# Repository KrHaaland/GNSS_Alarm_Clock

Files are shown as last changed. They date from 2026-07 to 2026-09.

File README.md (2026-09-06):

# GNSS Alarm Clock — Firmware

Firmware for the custom **SAMD51** alarm-clock board (Adafruit Metro M4
compatible), designed in `HARDWARE/` (KiCad). Two board revisions share one
firmware:

- **v2 (current)** — SAMD51J20A, **nPM1300 PMIC** with Li-ion charging and
  USB-C, LM3671 3.3 V + TPS61023 5 V boost, battery-backed RTC, MCU core on
  its internal buck regulator. See
  [`HARDWARE_V2.md`](HARDWARE_V2.md) and [ADR-0014](docs/adr/0014-npm1300-power-management.md)/[0015](docs/adr/0015-j20-default-swd-flashing.md).
  Default build: `metro_m4_j20`.
- **v1 (prototype)** — SAMD51J19A, LTC3226 + supercaps (design in
  `HARDWARE_OLD/`). Build: `adafruit_metro_m4`. The firmware detects the
  PMIC at runtime and degrades gracefully either way.

Time is set automatically from GNSS, the timezone (with DST) is derived offline
from the GNSS coordinates and saved to flash so it stays correct indoors, and
alarms drive an LED light-show + a tune through a class-D amp. The UI is LVGL on
a 428×142 color TFT driven by four buttons.

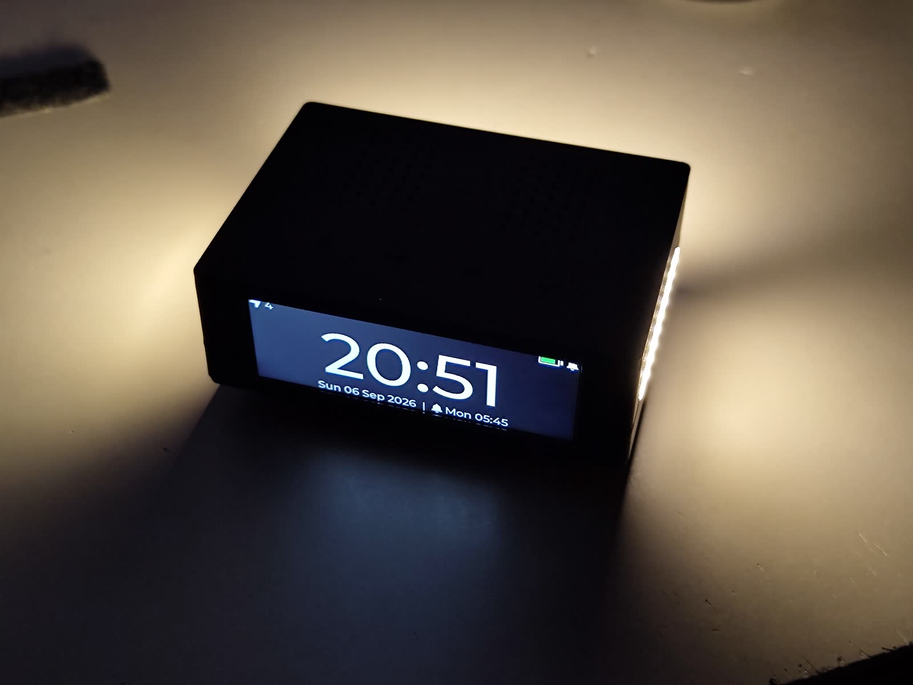
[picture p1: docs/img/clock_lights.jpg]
The clock at night, alarm light-show glowing


> **Current state:** firmware is feature-complete and running on hardware —
> display, GNSS time/timezone, alarms, audio, tunes-over-USB, settings, modes
> (speedometer/altimeter/USB-gamepad) and the RV-3028 RTC (hand-fitted; it was
> missing from the prototype) all work. See [`STATUS.md`](STATUS.md) and
> [`HARDWARE_REVIEW.md`](HARDWARE_REVIEW.md).

## Documentation

- **[User guide](docs/USER_GUIDE.md)** — buttons, menu, alarms, modes, tunes
- **[Architecture decisions](docs/adr/)** — why things are the way they are
- **[STATUS.md](STATUS.md)** — living status report · **[HARDWARE_REVIEW.md](HARDWARE_REVIEW.md)** — board findings
- **[HARDWARE_V2.md](HARDWARE_V2.md)** — v2 board reference (pinout, power tree, gotchas) · **[docs/sessions/](docs/sessions/)** — bench-session logs
- CI: GitHub Actions builds all firmware targets + runs the native test suite on every push

## What it does

- **Time**: The Quectel **L86** GNSS receiver (Serial1, 9600 NMEA, RMC+GGA @1 Hz
  plus GSV satellites-in-view every 5 s for the Sky-view screen, TinyGPS++ +
  a small in-house GSV parser) provides UTC. The clock is a `millis()`-anchored UTC counter
  disciplined by GNSS (re-syncs hourly / on ≥2 s drift) and backed by the
  **RV-3028-C7** RTC (I²C 0x52), whose VBACKUP sits on the battery (v2; the
  v1 prototype used the supercap rail) so it holds time through power loss. On boot the clock starts from the RTC
  immediately and refines from GNSS when a fix is available. A cold-start guard
  rejects the L86's free-running "year-2080" date so garbage can't be written
  into the backup RTC.
- **Timezone from coordinates**: An embedded **offline** lookup (213-box table
  covering every UTC zone worldwide — multi-zone countries split by region, plus
  no-DST exceptions like Arizona / Saskatchewan / Queensland / Kaliningrad;
  borders like US-zones and Afghanistan/Pakistan/India aligned to the real
  meridians). **Polygon zones** are checked before the boxes: real IANA
  timezone borders generated from timezone-boundary-builder data by
  `tools/gen_tz_polys.py` (tunable resolution/flash budget; enclaves ordered
  first), refinable by hand in `tools/tz_polygon_editor.html` (map GUI:
  draw/edit vertices, probe a point, export the header). Two resolutions,
  picked by flash size: v2/J20 gets the fine map
  (`src/TimezonePolyDataFine.h`, ~1–2 km borders, 404 zones / 56k vertices,
  ~250 KB), v1/J19 the coarse one (`src/TimezonePolyData.h`, ~57 KB). Anything not inside a polygon or box falls back
  to a whole-hour longitude estimate, so **every coordinate resolves**. Maps
  the GNSS position to a
  **POSIX TZ string with DST rules** (e.g. Oslo →
  `CET-1CEST,M3.5.0,M10.5.0/3`). The result is **persisted to internal flash**,
  so local time (including DST changes) stays correct after reboot even with no
  fix indoors. A DST-aware POSIX evaluator (`Timezone.*`, host-unit-tested)
  computes the offset. Manual zone override is available in the menu.
- **Alarms**: Two independent alarms with per-weekday masks. On trigger:
  - the **34 LEDs** (3 sections: left 10 / bottom 14 / right 10) run a chase at
    full brightness from a battery-capable rail (v2: TPS61023 5 V boost;
    v1: the LTC3226 supercap rail) — brightness never depends on the USB
    supply. The light show is **switchable per alarm** (Lights in the alarm
    editor; off = sound-only alarm),
  - a tune plays: a **WAV** from the QSPI flash drive, or one of 3 built-in
    melodies, via **DAC0 → TPA2016D2** class-D amp → speaker. WAVs pass a
    **200 Hz high-pass** in firmware: sub-bass cost the most battery current
    (speaker impedance minimum) for the least sound (ADR-0010),
  - optional **escalation**: after *N* minutes unacknowledged, the power buzzer
    joins in (v1 hardware only — v2 dropped the buzzer); auto-silence after
    30 min.
  - **Snooze**: short-press any button, or double-tap the clock (LIS3DH).
    **Stop**: long-press any button.
- **UI**: **LVGL 9.5** on an **NV3007 color TFT** (see below), driven by the 4
  buttons above the display: `[Back/Menu] [Prev/–] [Next/+] [OK]`. Screens:
  clock, menu, alarm-edit, time & zone, display, tunes, system-info,
  **sky view** (GSV polar plot + SNR bars — indoor antenna-placement aid),
  ringing. A true-black theme keeps the panel dark. Optional **starry night**:
  twinkling stars behind the clock digits between 22:00 and 06:00.
- **Modes** (Menu → Mode, cycles in place; alarms keep working in all of them):
  - **Alarm clock** — the normal HH:MM face.
  - **Speedometer** — the big figure shows GNSS ground speed in **km/h**.
  - **Altimeter** — GNSS altitude in **m** (MSL).
  - **Game mode** — the LIS3DH becomes a **USB HID gamepad**: tilt = stick
    X/Y, B2–B4 = buttons 1–3 (B1 keeps its menu role). The HID interface is
    always in the descriptor; it only sends reports in this mode.
- **Power (v2)**: the nPM1300 is driven end-to-end — input limit follows the
  USB-C CC advertisement (500 mA on PC ports, 1500 mA on real chargers,
  re-applied instantly on replug via the PMIC's IRQ line on PA04), charging
  400/800 mA to 4.10 V under an 80/70 °C die thermostat, live battery
  current on the Battery screen, a drawn SoC gauge on the clock face
  (ADR-0014/0016), and a low-battery policy: ship mode below 3.40 V (never
  during an alarm), fullscreen LOW BATTERY on a too-early wake, manual
  Shutdown in the menu — BUTTON1 or USB wakes it, the RTC keeps time
  throughout. The volume ceiling is bench-tuned to the PMIC's **1000 mA
  battery discharge limit (IBATLIM)** — exceeding it collapses VSYS and
  resets the device, so max volume (+7 dBV limiter) + LED chase stays under
  it with margin (ADR-0010/0014).
- **Tune upload**: the QSPI flash appears as a **USB flash drive** (`TUNES`) —
  drag & drop `.wav` files (PCM, 8/16-bit, mono/stereo, 8–48 kHz).

## Screenshots

Grabbed from the live firmware over USB serial (`tools/screenshot.py`).

| | |
|---|---|
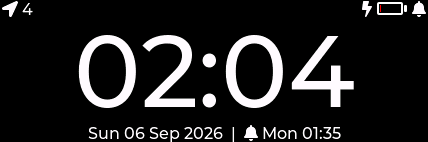
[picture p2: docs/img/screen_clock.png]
Clock face
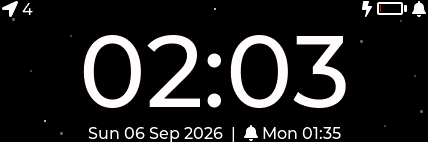
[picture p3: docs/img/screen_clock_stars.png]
Starry night
|  |  |
| Clock face — battery gauge, charge bolt, alarm bell | Starry night (22:00–06:00) |
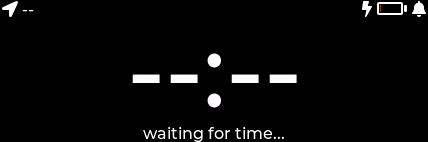
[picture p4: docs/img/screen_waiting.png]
Waiting for time
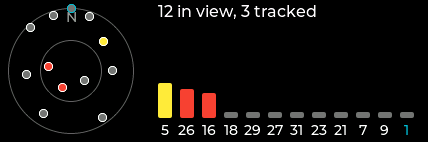
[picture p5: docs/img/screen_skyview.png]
Sky view
|  |  |
| First boot, no RTC/GNSS time yet | Sky view — GSV polar plot + SNR bars |
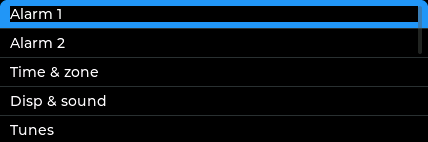
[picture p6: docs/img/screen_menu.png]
Menu
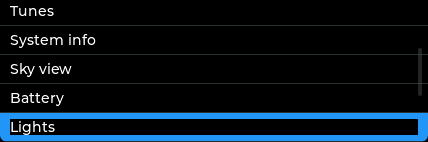
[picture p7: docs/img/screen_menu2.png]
Menu 2
|  |  |
| Main menu | …scrolled |
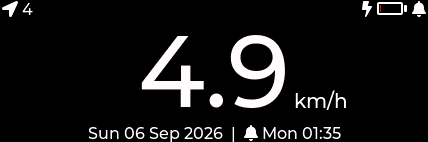
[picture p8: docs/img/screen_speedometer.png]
Speedometer
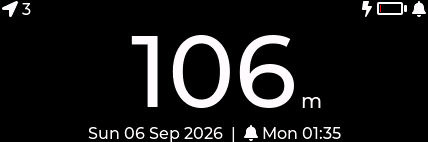
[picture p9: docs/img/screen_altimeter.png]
Altimeter
|  |  |
| Speedometer mode (GNSS) | Altimeter mode (GNSS) |
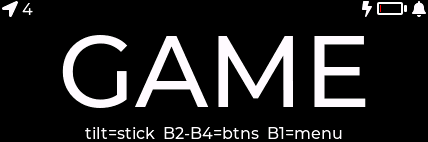
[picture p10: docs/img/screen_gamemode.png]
Game mode
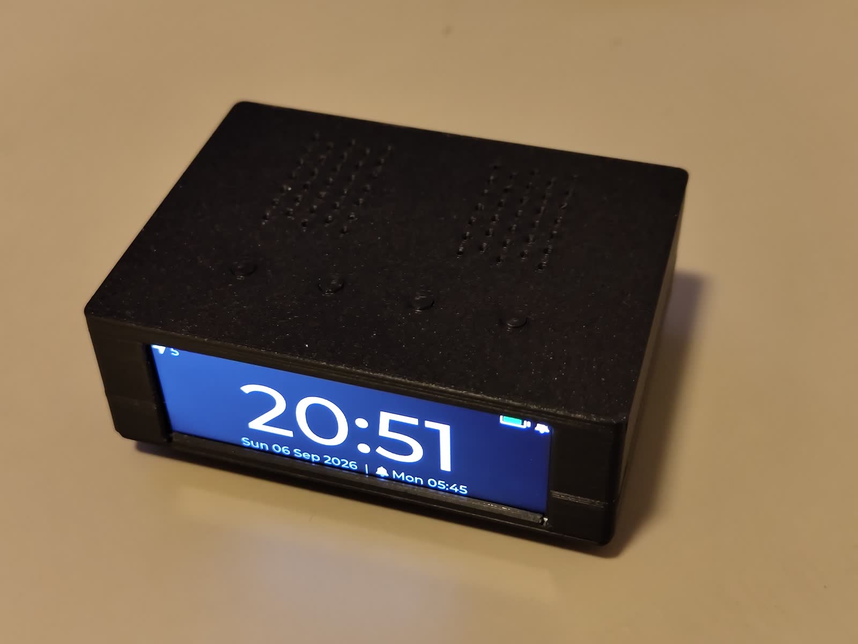
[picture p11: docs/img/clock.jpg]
The clock
|  |  |
| Game mode — USB HID gamepad | The 3D-printed enclosure |

## Display (NV3007)

The panel is an **NV3007 color TFT** (Newvision), native 142×428 bar type,
driven **landscape 428×142**. Driver: [`src/DisplayNV3007.cpp`](src/DisplayNV3007.cpp).
(The v1 prototype's ST7789 284×76 driver is kept in-tree — pick the panel via
**DISPLAY SELECT** in `platformio.ini`.)

- **Vendor init is mandatory**: `0xFF 0xA5` unlocks the extended register page
  (power/gamma/gate-driver/source-timing dump); without it the address engine
  wraps writes linearly across the glass. `0xFF 0x00` returns to the DCS page.
  Sequence cross-verified against five independent drivers (Arduino_GFX, LVGL
  lv_nv3007, vendor reference, STM32 + esp_lcd ports).
- GRAM is **168×428**; the 142 visible columns are inset 12/14. Landscape
  (`MADCTL 0xA0`, flipped 180° to match the enclosure mounting) puts the
  inset on RASET: **`NV_Y_OFFSET 12`** (unflipped 0x60 → 14). Inversion OFF.
- **SPI mode 0** (an NV3007 quirk — ST7789 setups often run mode 3), **30 MHz**
  (SERCOM2 re-clocked from the 120 MHz GCLK0 — the default 48 MHz source
  quantizes to 24 MHz max). Pixels stream via an **async DMA flush with double
  buffering** (ADR-0012, superseding ADR-0002's DMA ban): LVGL renders the
  next strip while the DMAC streams the previous one, and the completion IRQ
  hands the buffer back. Falls back to a synchronous DRE-paced register loop
  if the DMA channel is unavailable. Full frame ~26 ms on the wire, hidden
  behind rendering.
- Known silicon quirk: tiny partial writes can half-light adjacent pixels for
  RGB channel values 1–31 against black; LVGL's strip-sized flushes avoid it.
- Backlight D11/PA19, PWM-dimmed; shake-to-wake; `DISPLAY_SELFTEST` bring-up
  pattern test (colors/border/origin) as before.
- The clock figure uses a **generated 100 px Montserrat subset**
  (`src/font_clock_100.c`, 18 chars) — replacing the full 48 px font actually
  **shrank** flash by 67 KB (ADR-0011).

## Storage decision

The board has two candidate "EEPROMs" for tunes: the 24LC512 (64 KB, I²C) and a
QSPI serial flash. The firmware uses the **QSPI flash** (exposed as the USB
drive): far larger, faster, on the standard Metro M4 QSPI pins, and it enables
the drag-and-drop workflow.

**Settings** are packed into the **RV-3028 RTC's 43-byte user EEPROM**.
Chosen because it survives **firmware reflashes** (the old internal-flash
emulation sat inside the app image and was wiped on every update), takes
~100k writes/byte, and frees the **24LC512 to be dropped from the hardware-v2
BOM** (it still ACKs at 0x50 on v1 boards, unused). Verified on hardware:
settings survive both power cycles and reflashes.

### RTC user-EEPROM memory map (38 of 43 bytes)

Space is won by not storing derived data: TZ strings re-derive at boot from
the stored position (or the manual GMT-ladder index), and alarm tune filenames
are stored as 16-bit FNV-1a hashes re-matched against the TUNES directory
(missing file → builtin melody). Multi-byte fields are little-endian.

| Addr | Size | Field |
|---|---|---|
| `0x00` | 2 | Magic `'G' 'C'` |
| `0x02` | 1 | Pack-format version (4) — older blocks (v1–v3) migrate in place at boot, nothing is reset |
| `0x03` | 1 | Flags: b0 tzAuto, b1 tapSnooze, b2 use24h, b3 havePosition, b4–5 mode, b6 starryNight |
| `0x04` | 2 | Latitude, centidegrees (i16) |
| `0x06` | 2 | Longitude, centidegrees (i16) |
| `0x08` | 1 | Manual zone index into `TZ_TABLE` (`0xFF` = none/auto) |
| `0x09` | 1 | Volume (0–10) |
| `0x0A` | 1 | Snooze minutes |
| `0x0B` | 1 | Buzzer escalation after N min (0 = off) |
| `0x0C` | 1 | Brightness |
| `0x0D` | 2 | Dim timeout, seconds (u16) |
| `0x0F` | 1 | Dim brightness |
| `0x10` | 3 | Snooze counter, all time (u24, caps at 16.7 M) |
| `0x13` | 2 | Snooze counter, this week (u16) |
| `0x15` | 2 | Week start, local epoch-day − 18262 (u16, base 2020-01-01) |
| `0x17` | 7 | Alarm 1: flags (b0 enabled, b1–2 ramp Off/15/30/60 s, b3–4 random ±0/1/5/9 min, b5 lights-OFF — inverted so old blocks read as on), hour, minute, daysMask, melodyId, tuneHash (u16) |
| `0x1E` | 7 | Alarm 2: same layout |
| `0x25` | 1 | Checksum (block sums to `0xFF`) — **written last**, so a torn write invalidates the image |
| `0x26` | 5 | Free / future |

> **RV-3028 EEPROM quirks (bench-found, handled in `RtcRV3028.cpp`):** the
> chip **NACKs all I²C** while its EEPROM engine runs — both during the
> power-on auto-refresh (>100 ms) and in short windows after each programmed
> byte. The driver therefore treats failed STATUS reads as "still busy"
> (300 ms deadline), retries each byte transaction up to 5×, and read-back
> verifies every written byte.

> **Flash BOM note:** the schematic specifies a 4 MB Macronix MX25L3233F, but
> assembled boards carry a **16 MB Winbond W25Q128** (JEDEC 0xEF4018). The driver
> auto-detects the real chip via the library's default device list, so the true
> size is used for the USB drive.

## Pin map (from the KiCad netlist)

| Function | MCU pin | Arduino pin |
|---|---|---|
| Display CS / DC / RST / BL | PA18 / PA17 / PA16 / PA19 | D10 / D12 / D13 / D11 |
| Display SPI (SERCOM2) | PA12 MOSI, PA13 SCK | MOSI/SCK |
| GNSS L86 UART (SERCOM3) | PA22 TX → L86, PA23 RX ← L86 | Serial1 |
| GNSS FORCE_ON / RESET_N | PB00 / PB31 | direct port |
| I²C @100 kHz: RTC 0x52, amp 0x58, accel 0x18, EEPROM 0x50 | PB02 SDA, PB03 SCL | SDA/SCL |
| Buttons SW1..SW4 (L→R, active low) | PB14, PB13, PB12, PB15 | D5, D4, D7, D6 |
| LED gates: left / bottom / right | PA21 / PA20 / PA06 | D8 / D9 / A2 |
| Audio DAC → TPA2016 | PA02 (DAC0) | A0 |
| Amp ~SD (HIGH = on) | PB17 | D2 |
| Power buzzer gate (J5) | PB16 | D3 |
| Supercap CAPGOOD (LTC3226) | PA04 | A3 |
| LIS3DH INT1 (polled, unused) | PB08 | A4 |
| 24LC512 WP | PB01 | direct port |
| QSPI flash | PA08–11, PB10, PB11 | QSPI |

## Building & flashing

```sh
pio run                      # build (default env: adafruit_metro_m4)
pio test -e native           # host-side unit tests (timezone/DST engine)
```

### MCU select (J19 / J20)

The prototype has a **SAMD51J19A** (512 KB flash, ~95% full); the next revision
uses a **SAMD51J20A** (1 MB flash, ~48% — same pinout). Pick the build in
`platformio.ini` (`default_envs`) or per-invocation:

| env | MCU | notes |
|---|---|---|
| `adafruit_metro_m4` | J19A 512 KB | default (current prototype) |
| `metro_m4_j20` | J20A 1 MB | `boards/samd51j20a_metro.json` + `ld/samd51j20a_*.ld` |
| `sim` / `sim_j20` | either | + serial GNSS simulator (`-DGNSS_SIM`) |

```sh
pio run -e metro_m4_j20      # J20 build; flash .pio/build/metro_m4_j20/firmware.bin @0x4000
```

> **J20 + stock bootloader:** the Metro M4 UF2 bootloader is built for the
> J19A and reads the "stay in bootloader" magic at *its* RAM top
> (0x2002FFFC); a J20 app writes it at 0x2003FFFC, so the 1200-baud touch
> used to land straight back in the app. `tools/patch_tinyusb_power.py`
> patches the core's `initiateReset()` to write **both** addresses — USB
> uploads now work on the J20 with the stock bootloader.

Two flashing paths:

**A) USB (normal, no tools):** `pio run -e metro_m4_j20 -t upload` —
1200-baud touch into the bootloader, bossac writes + verifies at 0x4000
(~4 s). Manual alternative: double-tap RESET to mount the `METROM4BOOT`
drive and drag `firmware.uf2` onto it.

**B) SWD via Atmel-ICE (used in development):**

```sh
# build first, then flash the .bin at 0x4000 (offset preserves the bootloader)
openocd -c "adapter driver cmsis-dap" -c "transport select swd" \
        -c "adapter speed 2000" -f target/atsame5x.cfg \
        -c "init" -c "reset halt" \
        -c "flash write_image erase .pio/build/adafruit_metro_m4/firmware.bin 0x00004000 bin" \
        -c "reset run" -c "shutdown"
```

> ⚠️ **Never flash the `.elf` over SWD.** Its LOAD segment sits at address `0x0`
> and will overwrite the UF2 bootloader at flash start, bricking drag-and-drop
> programming (recovery = re-flash the bootloader). Always flash the **`.bin` at
> `0x4000`**. The bootloader region is additionally guarded by the
> **BOOTPROT fuse (16 KB)** since a brownout-induced wild NVMCTRL write once
> zeroed the bootloader's vector table (see `docs/sessions/`); clear it with
> `atsame5 bootloader 0` before intentional bootloader updates, restore with
> `atsame5 bootloader 16384`.

`pio device monitor -b 115200` opens the USB-CDC console. Sending `~` on
the console streams the next rendered frame as a screenshot —
`python3 tools/screenshot.py` grabs it and writes a PNG (used for the
documentation images; works on the live device, any screen).

### USB identity

The app enumerates as **`1209:0001` — "K. Haaland / GNSS Alarm Clock"**.
VID `0x1209` belongs to [pid.codes](https://pid.codes) (free USB IDs for
open-source hardware); `0x0001` is their official **test PID**, fine for
personal use — register a permanent PID via a pid.codes PR (requires a public,
OSI-licensed repo) before distributing hardware. Identity lives in
`boards/samd51j19a_kh.json` / `boards/samd51j20a_metro.json`. Bootloader mode
(double-tap reset) still enumerates as Adafruit `239A` until a custom
uf2-samdx1 is built.

### Simulated GNSS (`env:sim`)

To test the timezone/clock pipeline on-device **without a real fix**, build the
`sim` env — identical firmware plus `-DGNSS_SIM` (the L86 init is skipped and a
serial console feeds position/time):

```sh
pio run -e sim -t upload      # or SWD-flash .pio/build/sim/firmware.bin @0x4000
pio device monitor -b 115200
```

Then type commands into the monitor:

```
pos 59.91 10.75              set a fix; resolves + applies the timezone
tz  -33.87 151.2             query a zone (Jan/Jul offset + DST), no state change
utc 2026 7 13 12 0 0         set the UTC clock so local time shows on the display
status                       print fix / UTC / local time / zone
nofix                        drop the simulated fix
```

`pos` also updates the on-screen clock's zone immediately, so you can watch the
display follow you around the globe. The `sim` code compiles to nothing in the
normal build — zero production-flash cost.

## Source layout

| File | Responsibility |
|---|---|
| `src/main.cpp` | Boot order, super-loop, alarm ↔ UI ↔ button routing, I²C @100 kHz |
| `src/ClockKeeper.*` | UTC anchor, GNSS→RTC discipline, local time / DST |
| `src/Timezone.*` | Coord→zone polygons+boxes + POSIX TZ/DST evaluator (host-testable) |
| `src/TimezonePolyData.h` | Polygon zone data: `tools/gen_tz_polys.py` (world set) / `tools/tz_polygon_editor.html` (hand edits) |
| `src/Gnss.*` | L86 NMEA via TinyGPS++, PMTK config, position/speed/altitude |
| `src/RtcRV3028.*` | RV-3028-C7 driver wrapper (backup switchover, UTC, PORF) |
| `src/AlarmManager.*` | Trigger scan, ringing/snooze/escalation state machine |
| `src/AudioEngine.*` | TC2 ISR → DAC0 playback, WAV streaming, melodies, buzzer |
| `src/TuneStorage.*` | QSPI flash, FAT12 volume, USB mass storage |
| `src/DisplayST7789.*` | ST7789 driver + LVGL 9 flush (RGB565), bring-up self-test |
| `src/Ui.*` | LVGL screens: clock, menu, alarm edit, zone, display, tunes, info, sky view, battery, lights, ringing |
| `src/PmicNPM1300.*` | nPM1300: CC-based input limit, charger, IBAT/SoC, ship mode, IRQ (v2) |
| `src/Buttons.*` / `src/Leds.*` | Debounced input, LED section patterns |
| `src/AmpTPA2016.*` / `src/AccelLIS3DH.*` | Amp gain/enable, double-tap-to-snooze |
| `src/Settings.*` | Persistent settings packed into the RTC's user EEPROM (v4, 38 B) |
| `src/SimConsole.*` | Serial "virtual GPS" console — `env:sim` only (`-DGNSS_SIM`) |

## Diagnostics (compile-time, default off)

- `DISPLAY_SELFTEST` in [`DisplayST7789.cpp`](src/DisplayST7789.cpp) — on-glass
  pattern test (RGB fills, edge border) instead of LVGL.
- `I2C_SCAN` in [`main.cpp`](src/main.cpp) — loops scanning the I²C bus and
  prints ACKing addresses over USB serial (used to diagnose the RTC).

## Known issues / verify on hardware

See [`STATUS.md`](STATUS.md) for the full list. Highlights:

- 🔴 **RV-3028 RTC (U5) does not ACK on I²C** — bad joint / power on U5; being
  reflowed. (Time still works from GNSS; only power-off holdover is affected.)
- **L86 1PPS (pin 6) and AADET_N (pin 8) are unrouted** — no hardware PPS
  timing, no antenna-detect.
- **`CAPGOOD` polarity** assumed HIGH = charged (LTC3226 open-drain + pullup).
- Plus the schematic findings in [`HARDWARE_REVIEW.md`](HARDWARE_REVIEW.md)
  (LM3671 VIN/SW, L86 V_BCKP cold-start, D3 diode, C30, crystal caps, …).

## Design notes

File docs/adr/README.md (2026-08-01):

# Architecture Decision Records

Short records of the non-obvious decisions in this project — context,
the decision, and its consequences. Newest last. Format: lightweight MADR.

| # | Title | Status |
|---|---|---|
| [0001](0001-tunes-on-qspi-flash.md) | Tune storage on QSPI flash + USB MSC | Accepted |
| [0002](0002-synchronous-display-flush.md) | Synchronous per-byte display flush (no DMA) | Superseded by 0012 |
| [0003](0003-offline-timezone-resolution.md) | Offline timezone: polygons → boxes → longitude | Accepted |
| [0004](0004-settings-in-rtc-user-eeprom.md) | Settings in the RV-3028 user EEPROM | Accepted |
| [0005](0005-usb-identity-pidcodes.md) | USB identity via pid.codes | Accepted |
| [0006](0006-tinyusb-pinned-241.md) | TinyUSB pinned to 2.4.1 | Accepted |
| [0007](0007-i2c-100khz.md) | I²C bus at 100 kHz | Accepted |
| [0008](0008-hw-v2-j20-liion.md) | Hardware v2: SAMD51J20A + Li-ion | Accepted (planned) |
| [0009](0009-alarm-interaction-choices.md) | Alarm interaction choices | Accepted |
| [0010](0010-amp-loudness-architecture.md) | Amp loudness: AGC leveling, limiter as volume | Accepted |
| [0011](0011-display-panel-select-and-subset-font.md) | Panel select + subset clock font | Accepted |
| [0012](0012-async-dma-display-flush.md) | Async DMA display flush + double buffering | Accepted |
| [0013](0013-dma-paced-dac-audio.md) | DMA-paced DAC audio playback | Accepted |
| [0014](0014-npm1300-power-management.md) | v2 power management: nPM1300 strategy | Accepted |
| [0015](0015-j20-default-swd-flashing.md) | SAMD51J20A default target; SWD-first flashing | Accepted |
| [0016](0016-soc-estimate-and-gauge.md) | Battery SoC: measured-only estimate, approximate gauge | Accepted |

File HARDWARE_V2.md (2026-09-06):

# Hardware v2 — firmware-facing reference

Extracted systematically from `HARDWARE/GNSS_Alarm_Clock.kicad_pcb` (the
netlist is authoritative for the built board). v1 design lives in
`HARDWARE_OLD/`. This file is the ground truth for firmware work on v2 —
update it when the board changes.

## Power tree

```
USB-C (J1, CC1/CC2 -> PMIC)          Li-ion (J7, 2-pin JST-PH)
        |                                   |
      VUSB ──> nPM1300 (U3, I2C 0x6B) <── VBAT ──> RV-3028 VBACKUP (U5.6)
                   |  charger + power path + USB-C detection
                 VSYS  (= VBUS when present, else battery, ideal diode)
                   |   BATTERY BUDGET: nPM1300 IBATLIM caps discharge at
                   |   1000 mA — exceeding it drops VSYS below VSYSPOF and
                   |   RESETS the board. On battery, everything below must
                   |   fit in ~3.5 W. (On USB, VBUS adds its 0.5/1.5 A.)
                   ├──> LM3671 (U14)  -> +3.3V   (EN: R13 100k -> VSYS, always on)
                   └──> TPS61023 (U6) -> +5V     (EN: R4 100k -> VSYS, always on;
                        FB R5 732k / R12 100k -> ~5.0 V, boosts from battery too)
+3.3V: MCU, display (J4.7), L86 VCC+V_BCKP, RTC VDD, LIS3DH, QSPI flash,
       amp VDD (U1.13), I2C pullups (R6/R7 4.7k)

Bulk caps: C21 on +5V, C18 on +3.3V (both 220 uF aluminum electrolytic,
6.3x5.7 SMD). **C21 MUST stay an electrolytic (or get a feedforward cap
first) — its ESR is load-bearing.** Bench saga 2026-09: swapping C21 to a
560 uF (and later 330 uF) low-ESR polymer made the TPS61023 boost
UNSTABLE under load — oscillation/current slams dipped VSYS, resetting
the MCU (USB disconnects on PC charging; fast charger + all LEDs too);
charging thrashed CC<->trickle. Both polymers failed, the old elko
works: the discriminator is ESR, not capacitance. Datasheet-confirmed:
above ~40 uF output capacitance the TPS61023 needs a zero at ~1 kHz
(feedforward cap) — the elko's ESR zero (0.5 ohm x 220 uF ~ 1.4 kHz)
WAS that compensation, by accident. The ~50-125 mW ESR ripple loss is
the price of stability here. If polymer is ever wanted (v3): add
C_FF ~ 220 pF across R5 (732k) for the 1 kHz feedforward zero per the
datasheet, THEN low-ESR bulk is legal. C18 (3.3 V, buck output) is
unaffected either way — the LM3671 has its own MLCC and quiet loads.

- **The nPM1300's bucks are unused** (VOUT1/VOUT2/SW unconnected): the PMIC
  does charging, power path and USB-C only; regulation is external.
- **The MCU's core (VDDCORE) runs on its internal buck** via inductor L4
  (firmware selects it — the Arduino core defaults to the lossier LDO);
  ~4–6 mA saved at 3.3 V (ADR-0014).
- **VBUS input current limit resets to 100 mA on every VBUS plug/reset** —
  firmware re-applies it at boot AND on every attach (GPIO0 IRQ), set from
  the CC advertisement: 500 mA on Default USB/PC ports, 1500 mA on 1.5/3 A
  sources. Charging + system share the budget (supplement mode: the
  battery covers bursts beyond it).
- Charger config (firmware): 400 mA setpoint (the PMIC gives charging
  whatever remains of the input budget), terminate 4.10 V (user choice,
  cell longevity), die-temp thermostat 65/55 °C. NTC pin has a fixed 10k
  to GND (R16) — reads a constant ~25 °C, real temperature limiting is
  the die thermostat. No thermistor in the battery (J7 is 2-pin).
- **RTC backup is the battery** (VBAT -> U5.6): time survives power-off as
  long as a battery is fitted. Supercaps and LTC3226 are gone.
- **Battery: generic 505060 LiPo pouch, 3.7 V 2000 mAh, WITH PCM**
  (fitted 2026-08-10, replacing the bring-up LG HG2 18650 3000 mAh
  unprotected power cell). Battery-to-PCB leads: **100 mm, 20 AWG**
  (to J7/B2B-PH-K-S) — ~7 mOhm round trip, negligible next to the
  cell+PCM source impedance. 26 AWG was tried first and REJECTED:
  too much voltage drop under load on the bench (nominal ~27 mOhm
  round trip; real crimped wire measured worse) — and with the
  loaded-voltage 3.40 V cutoff, lead drop eats usable capacity
  directly. The PCM backstops overcharge/overdischarge/
  overcurrent, but the firmware's 3.40 V ship-mode cutoff still acts
  first (PCM floors are typically 2.5-3.0 V). Expect notably higher
  source impedance than the HG2 (generic pouch ~50-150 mOhm + PCM
  ~30-50 vs the HG2's ~25): the battery-path constant used for the
  IR-compensated SoC estimate (was ~160 mOhm total with the HG2) MUST
  be re-calibrated from the charger plug-in jump — and loaded-voltage
  sag at ~1 A is correspondingly larger (re-run the worst-case audio
  bench test; low-battery watchdog may need IR compensation).
- L86 **V_BCKP is on +3.3V** (U4.5), *not* VBAT — GNSS still cold-starts
  after a full power-off (v1 HW-review #10 persists on v2).

## MCU pin map (U18 — fitted chip is a **SAMD51J20A**)

The schematic symbol says ATSAMD51J19A, but the fitted part reports
`ATSAMD51x20` via `bossac -i` (1 MB flash / 256 KB RAM) — same stale-symbol
story as the flash chip; tidy the symbol on the next revision. J19A and
J20A are pin-identical in TQFP64, so the pin map below applies unchanged.
Build with `pio run -e metro_m4_j20` (the project default).

Complete map of all 64 pads of U18, TQFP64. Columns:

- **Pad** — TQFP64 pad number (from the ATSAMD51J19A symbol in
  `GNSS_Alarm_Clock.kicad_sch`).
- **PORT** — the SAMD51 PORT pin the symbol assigns to that pad.
- **v2 net** — net name on the pad in `GNSS_Alarm_Clock.kicad_pcb`. `—` for
  power/ground; `(unconnected)` for a genuinely floating GPIO.
- **Function** — what firmware does with it.
- **Arduino** — pin number in the `adafruit_metro_m4` variant
  (`variant.cpp`, `g_APinDescription` order). `DIRECT PORT` = the PORT pin
  is not exposed by that variant, so firmware must touch the PORT
  registers. `—` = power/ground/reset, no Arduino pin.

| Pad | PORT | v2 net | Function | Arduino |
|----:|------|--------|----------|---------|
| 1 | PA00 | XIN32 (X1.2) | 32.768 kHz crystal (XOSC32K, RTC/clock) | DIRECT PORT (crystal, not GPIO) |
| 2 | PA01 | XOUT32 (X1.1) | 32.768 kHz crystal | DIRECT PORT (crystal, not GPIO) |
| 3 | PA02 | Analog | Audio DAC out → C27 → TPA2016 INR- | D14 / A0 / DAC0 |
| 4 | PA03 | +3.3V | VREFA tied to +3.3V (analog reference, not a GPIO) | — |
| 5 | PB04 | (unconnected) | free | DIRECT PORT |
| 6 | PB05 | (unconnected) | free | DIRECT PORT |
| 7 | GNDANA | GND | analog ground | — |
| 8 | VDDANA | +3.3V | analog supply | — |
| 9 | PB06 | (unconnected) | free (was RXLED on Metro) | D27 |
| 10 | PB07 | (unconnected) | free (was USB Host EN on Metro) | D29 |
| 11 | PB08 | LIS3DH_INT1 | Accelerometer INT1 (U7.11) | D18 / A4 |
| 12 | PB09 | (unconnected) | free | D19 / A5 |
| 13 | PA04 | PMIC_GPIO0 | nPM1300 GPIO0 (U3.7); unconfigured reads LOW | D17 / A3 |
| 14 | PA05 | (unconnected) | free | D15 / A1 / DAC1 |
| 15 | PA06 | LedsR-S | Right LED section gate → R56 470R → U12 | D16 / A2 |
| 16 | PA07 | (unconnected) | free | DIRECT PORT |
| 17 | PA08 | FlashIO0 | QSPI flash DATA0 (U8.5) | D43 |
| 18 | PA09 | FlashIO1 | QSPI flash DATA1 (U8.2) | D44 |
| 19 | PA10 | FlashIO2 | QSPI flash DATA2 (U8.3) | D45 |
| 20 | PA11 | FlashIO3 | QSPI flash DATA3 (U8.7) | D46 |
| 21 | VDDIOB | +3.3V | I/O supply | — |
| 22 | GND | GND | ground | — |
| 23 | PB10 | FlashSCK | QSPI flash SCK (U8.6) | D41 |
| 24 | PB11 | FlashCS | QSPI flash CS (U8.1) | D42 |
| 25 | PB12 | BUTTON3 | SW3, active-low, 1M pull-up (R9) | D7 |
| 26 | PB13 | BUTTON2 | SW2, active-low, 1M pull-up (R8) | D4 |
| 27 | PB14 | BUTTON1 | 74LVC1G17 (U9.4) output, not a raw switch | D5 |
| 28 | PB15 | BUTTON4 | SW4, active-low, 1M pull-up (R10) | D6 |
| 29 | PA12 | SPI_MOSI | Display SPI MOSI (SERCOM2), J4.5 | D26 / MOSI |
| 30 | PA13 | SPI_SCK | Display SPI SCK (SERCOM2), J4.6 | D25 / SCK |
| 31 | PA14 | SPI_MISO | SPI MISO (SERCOM2) — not routed to J4 panel | D24 / MISO |
| 32 | PA15 | (unconnected) | free | DIRECT PORT |
| 33 | GND | GND | ground | — |
| 34 | VDDIO | +3.3V | I/O supply | — |
| 35 | PA16 | DISP_RST | Display reset (active low), J4.4 | D13 |
| 36 | PA17 | DISP_DC | Display data/command, J4.3 | D12 |
| 37 | PA18 | DISP_CS | Display chip select (active low), J4.2 | D10 |
| 38 | PA19 | DISP_BL | Display backlight/aux, J4.1 | D11 |
| 39 | PB16 | (unconnected) | **buzzer removed on v2** (was SPEAKER) | D3 |
| 40 | PB17 | AmpShutdown | TPA2016 ~SD (U1.18), 10k pull-up R68, HIGH=on | D2 |
| 41 | PA20 | LedsB-S | Bottom LED section gate → R54 470R → U11 | D9 |
| 42 | PA21 | LedsL-S | Left LED section gate → R15 470R → U10 | D8 |
| 43 | PA22 | McuTX | Serial1 TX (SERCOM3) → L86 RX (U4.1) | D1 |
| 44 | PA23 | McuRX | Serial1 RX (SERCOM3) ← L86 TX (U4.2) | D0 |
| 45 | PA24 | USB_N | USB D- (via U2 ESD) | D30 |
| 46 | PA25 | USB_P | USB D+ (via U2 ESD) | D31 |
| 47 | GND | GND | ground | — |
| 48 | VDDIO | +3.3V | I/O supply | — |
| 49 | PB22 | (unconnected) | free (was NEOPIX on Metro) | D40 |
| 50 | PB23 | (unconnected) | free | DIRECT PORT |
| 51 | PA27 | (unconnected) | free (was TXLED on Metro) | D28 |
| 52 | RESETN | SWD_RST | MCU reset (SW5 + J3 SWD, 100k pull-up R67) | — |
| 53 | VDDCORE | (core reg) | 1.2 V core LDO decoupling | — |
| 54 | GND | GND | ground | — |
| 55 | VSW | (core reg) | core regulator switch node | — |
| 56 | VDDIO | +3.3V | I/O supply | — |
| 57 | PA30 | SWD_CLK | SWD clock, J3 (100k pull-up R66) | DIRECT PORT |
| 58 | PA31 | SWD_IO | SWD data, J3 | DIRECT PORT |
| 59 | PB30 | SWO | SWO trace, J3.6 | DIRECT PORT |
| 60 | PB31 | GNSS_Reset | L86 RESET_N (U4.10), active low | DIRECT PORT |
| 61 | PB00 | GNSS_FOn | L86 FORCE_ON (U4.7) | DIRECT PORT |
| 62 | PB01 | (unconnected) | **24LC512 removed on v2** (was EEPROM WP) | DIRECT PORT |
| 63 | PB02 | I2C_SDA | I2C SDA (SERCOM), 4.7k pull-up R6 | D22 / SDA |
| 64 | PB03 | I2C_SCL | I2C SCL (SERCOM), 4.7k pull-up R7 | D23 / SCL |

Delta vs v1 (`include/pins.h`), verified net-for-net:

| Pin | v1 | v2 |
|---|---|---|
| PA04 (A3) | CAPGOOD (LTC3226, HIGH = caps charged) | **PMIC_GPIO0** (nPM1300 GPIO0; unconfigured = reads LOW) |
| PB16 (D3) | Buzzer MOSFET gate (J5) | **Unconnected — the escalation buzzer does not exist on v2** |
| PB01 | 24LC512 write protect | Unconnected (EEPROM gone) |
| PB14 (D5, BUTTON1) | raw switch, active low | driven by 74LVC1G17 (U9), see Buttons |
| PB30/SWO | — | SWO to SWD connector J3.6 |

Everything else is identical net-for-net: display PA16-19 + SERCOM2 SPI (J4
8-pin XH header: BL,CS,DC,RST,MOSI,SCK,3V3,GND — no MISO to the panel),
buttons PB12-15, LED gates PA21/PA20/PA06, GNSS PA22/PA23 + PB00/PB31, DAC
PA02 → C27 → TPA2016 INR-, QSPI PA08-11 + PB10/11, I2C PB02/PB03.

**U8 tune flash — WRONG PART FITTED on the first v2 board:** JEDEC probe
reads `EF 60 18` = **W25Q128FW**, Winbond's **1.8 V** variant, running out
of spec on the 3.3 V rail (abs max ~2.5 V). It answers JEDEC but has no
library profile, so `flash.begin()` fails and the TUNES drive/storage is
disabled (firmware degrades gracefully). **Replace with W25Q128JVSIQ**
(3 V, JEDEC `EF 40 18`, in the library's builtin list, same SOIC-8) or an
MX25L3233F (4 MB, matches the schematic symbol + our explicit descriptor).
The schematic symbol says MX25L3233F and the BOM Value says "25Q128" —
tidy both on the next revision.

## Display module gotcha: BL strap polarity

Off-the-shelf NV3007 modules differ in how the backlight enable is strapped
on the module: with a **pull-up**, a floating DISP_BL (PA19 — floats through
the whole UF2-bootloader phase) means the backlight burns at FULL power
inside the PMIC's 100 mA power-up window → a battery-less board boot-loops
before any code can help (and shows a ghost of the previous frame, since
the panel GRAM survives the shallow brownouts). Diagnosed by tying BL to
GND, which let it boot. Modules with a **pull-down** are safe. Firmware
drives PA19 low as its first instruction and soft-starts the backlight,
which closes the app-phase window but cannot reach the bootloader phase.

## Buttons

- SW2-SW4 = BUTTON2-4, active low, 1M pullups (as v1).
- **BUTTON1 is special on v2**: the physical button is SW1, which drives
  the nPM1300's **SHPHLD** pin directly and reaches PB14 through a
  74LVC1G17 buffer (U9). Idle high (PMIC internal pull), pressed = LOW —
  same polarity as v1. Consequences:
  - Pressing BUTTON1 wakes the PMIC from ship/hibernate mode (battery boot).
  - A very long press (~10 s, PMIC long-press function) power-cycles the
    whole board in hardware — independent of firmware.
- SW5 = MCU reset (SWD_RST), on the 10-pin SWD header J3 side.

## LED sections (unchanged counts, better gates)

10 left / 14 bottom / 10 right (LED1-10 / LED11-24 / LED25-34, OR-PL020W,
100R each from +5V, R20-R53). Gates now have 470R series + 10k pulldowns
(left PA21→R15/R57→U10, bottom PA20→R54/R55→U11, right PA06→R56/R58→U12) —
v1's floating-gate-at-boot quirk is fixed.

## I2C bus (100 kHz, pullups 4.7k)

| Addr | Device | Note |
|---|---|---|
| 0x18/0x19 | LIS3DH (U7) | v2 straps SA0 low (R18 10k->GND) and CS high (R63 10k->3.3V), so 0x18 is the *design* address — but the first v2 board answers at **0x19**, meaning SA0 doesn't see its pulldown (suspect solder at U7 or R18 unfitted). Harmless: FW probes both. |
| 0x52 | RV-3028 RTC | battery-backed via VBAT |
| 0x58 | TPA2016 amp | PVCC now +5V boost (works on battery) |
| 0x6B | nPM1300 PMIC | see power tree |

## GNSS (L86, U4)

Wiring identical to v1: pad1->McuTX(PA22), pad2->McuRX(PA23), VCC+V_BCKP
on +3.3V, FORCE_ON PB00, RESET_N PB31. **1PPS (U4.6) and AADET_N (U4.8)
remain unrouted** (v1 findings persist). V_BCKP not battery-backed (above).

## Other

- USB ESD: U2 PRTR5V0U2X on USB_P/N/VUSB (+C2/R1 network on pin 1).
- 32.768 kHz crystal X1 on PA00/PA01 with 10 pF load caps (v1 finding
  about wanting ~18-22 pF persists).
- Speaker: J6 from TPA2016 OUTR± (right channel only, as v1).
- nPM1300 GPIO1-4 and LED0-2 pads unconnected; GPIO0 -> PA04 (candidate:
  configure as charge-status output so FW can read charging without I2C).

## Next board revision (v3) checklist

Collected findings from the v2 bring-up, in rough priority order:

- [ ] **R68: amp ~SD pull-up → pull-DOWN.** Today the TPA2016 is enabled
      through the whole bootloader phase (~1 s) before firmware can kill
      it: wastes 5–15 mA in the battery-less boot window and audibly
      amplifies the undriven DAC node (boot noise, user-confirmed).
      Pull-down = off until firmware enables.
- [ ] **L86 load switch** (enable in front of its 3.3 V): the module is
      the largest uncontrollable boot-window load (~100 mA acquisition
      bursts) — firmware can only hold it in reset today.
- [ ] **L86 V_BCKP → VBAT** (carried over from v1 review #10): GNSS
      cold-starts after every full power-off; battery-backing it gives
      warm starts. Route 1PPS to a spare GPIO while at it.
- [ ] **VBACKUP buffer cap (U5.6)**: ~100 nF–1 µF from the RV-3028's
      VBACKUP pin to GND. In ship mode the RTC runs from VBACKUP alone
      (nA domain, high impedance) and a hot-plug ground transient — e.g.
      a floating charger's Y-cap leakage equalizing through the board
      while SWD pins board GND to PC earth — can POR it and lose the
      time (observed 2026-08-02). A local cap rides the chip through.
- [ ] **LIS3DH SA0 strap**: R18 (10k pulldown) is not effective on the
      built board (chip answers 0x19, not 0x18) — inspect/repair the
      strap or route it harder. FW probes both addresses regardless.
- [ ] **Schematic symbol tidy-up**: U18 says J19A (fitted: J20A), U8 says
      MX25L3233F with Value "25Q128" (correct part: W25Q128**JV**SIQ 3 V —
      the FW suffix cost a bricked-storage detour).
- [ ] **Display BL strap**: specify/verify pull-DOWN modules only (a
      pull-up module burns the backlight through the bootloader phase and
      boot-loops a battery-less board).
- [ ] Optional: inrush limiting on the panel rail; keep the nPM1300
      GPIO0→PA04 IRQ line (it earned its keep).

## Firmware consequences (status)

- [x] `pmic_begin()` raises VBUS ILIM at every boot + configures charger
- [x] `supercaps_ready()` returns true when PMIC present (until battery UI)
- [x] Accelerometer probes 0x18 and 0x19
- [x] Battery/PMIC screen in the menu
- [ ] Escalation buzzer is a silent no-op on v2 (PB16 unrouted) — gate the
      escalation stage on `pmic_present()` or repurpose (max volume + LEDs)
- [x] Battery gauge on the clock screen; low-battery ship-mode policy
- [x] nPM1300 GPIO0 -> PA04 used as IRQ line (VBUS attach/removal)

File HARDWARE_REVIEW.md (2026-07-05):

# Hardware Design Review — GNSS Alarm Clock (SAMD51J19A board)

> ## Display change (2026-07): SH1122 → ST7789
> The board now uses an **ST7789 color TFT** (native 76×284, driven landscape
> **284×76**) in place of the SH1122 256×64 grayscale OLED. Firmware driver:
> `src/DisplayST7789.cpp`.
> - Same 4-wire SPI on J3: CS/DC/RST + MOSI/SCK (SERCOM2).
> - **Backlight (BLK):** the ST7789 needs a backlight supply the OLED did not.
>   Per finding #14 below, **J3 has no backlight line**, so BLK must be wired
>   separately — currently assumed on **D11 / PA19** (the old `OLED_BL`,
>   PWM-capable via TCC1 for dimming). *Confirm/adjust the actual BLK pin.*
> - Also confirm the **flash BOM substitution** (16 MB Winbond W25Q128, see the
>   TuneStorage note) when you revise the BOM.
> - Panel-specific ST7789 params still being tuned on the bench: MADCTL
>   orientation, display inversion, and the column/row window offsets.

Reviewed from `HARDWARE/production/netlist.ipc` (IPC-356 connectivity),
`HARDWARE/production/bom.csv`, and `HARDWARE/samd51_gps_alarm_clock.kicad_sch`.
Findings were produced by 8 domain reviewers and each **adversarially
verified** by an independent skeptic. 19 confirmed, 7 refuted.

> ⚠️ Reality check on the critical finding: the assembled board **does** power
> up and run (MCU, USB, display all work across many flash cycles). That is in
> tension with a fully-broken 3.3 V regulator. **Measure the 3.3 V rail and
> U14 temperature** to decide whether your unit is affected/was reworked, or
> whether the KiCad symbol pin mapping actually differs from what the netlist
> text suggests. Treat the LM3671 item as "verify on the bench first."

---

## 🔴 Critical

### 1. LM3671 (U14) 3.3 V buck — VIN and SW swapped in the KiCad symbol
- **Evidence:** schematic symbol `LM3671MFX-3.3_NOPB` declares pin **1 = "VIN"**,
  pin **5 = "SW"** (pin2=GND, pin3=EN, pin4=FB). Real LM3671MF SOT-23-5 pinout
  (TI SNVS482) is **pin1=SW, pin2=GND, pin3=EN, pin4=FB, pin5=VIN**. Netlist
  copper follows the (wrong) symbol: U14 pad1=+5V, pad4=+3.3V (FB), pad5=NET-(U14-SW),
  and L1 joins pad5 ↔ +3.3V. Footprint pads are standard SOT-23-5 (no compensating renumber).
- **Why wrong:** on real silicon +5 V lands on the switch node and VIN is fed
  only through inductor L1 from the 3.3 V output → the buck cannot regulate; the
  whole +3.3 V rail (MCU, GNSS, RTC, EEPROM, accel, QSPI flash, OLED) is affected
  and the SW pin is abused by 5 V.
- **Fix:** correct the library symbol so pin 1 = SW and pin 5 = VIN (or swap the
  copper so +5 V lands on pad5 and the L1/SW node on pad1). FB→+3.3 V is already
  correct for the fixed-output variant.

---

## 🟠 Major

### 2. Buzzer/speaker flyback diode D3 wired the wrong way (found by 3 reviewers)
- **Evidence:** D3 cathode (NET-(D3-K)) = U13 drain = J5-2; D3 anode = GND.
  J5-1 = ALARMPOWER (via 0 Ω R64). U13 is a low-side N-FET (source=GND).
- **Why wrong:** for a low-side switch on a supply-referenced inductive load
  (speaker/buzzer coil), the freewheel diode must be **anode→drain, cathode→ALARMPOWER**
  so the turn-off spike recirculates into the supply. As built it parallels the
  MOSFET body diode and clamps only negative undershoot → no protection; the FET
  can avalanche on the positive spike.
- **Fix:** reorient D3 across the coil — cathode to ALARMPOWER (J5-1 / NET-(C21-PAD1)),
  anode to the drain (NET-(D3-K)).

### 3. C30 (VDDCORE decoupling) tied to +3.3 V instead of GND
- **Evidence:** C30 pad1=NET-(U18-VDDCORE), pad2=**+3.3V**. Siblings C26/C29 are
  correctly VDDCORE↔GND. BOM groups C26+C30 as identical 1 µF → C30 is meant to be
  the 3rd VDDCORE bypass cap.
- **Why wrong:** VDDCORE is the SAMD51 internal ~1.2 V core rail; its bypass must
  reference GND. Tying it to +3.3 V injects the 3.3 V ramp/switching transient into
  the core node.
- **Fix:** move C30 pad2 from +3.3 V to GND.

### 4. 32.768 kHz crystal load caps wrong (C24/C25 = 10 pF for a 12.5 pF-CL xtal)
- **Evidence:** X1 = Epson FC-135 (CL = 12.5 pF per schematic description); C24/C25 = 10 pF.
- **Why wrong:** required load caps ≈ 2·(CL − Cstray) ≈ 18–22 pF. 10 pF presents
  ~7–8 pF effective load → oscillator runs fast (~+50…100 ppm, several s/day) and
  startup margin is reduced.
- **Fix:** fit ~18–22 pF (start 18 pF), tune on-board; or swap X1 for a 7 pF-CL crystal.
- *Note:* affects the SAMD51's own 32 kHz clock accuracy; GNSS/RTC still discipline wall-clock time.

### 5. USB ESD array (U2 PRTR5V0U2X) ground pin not grounded (found by 2 reviewers)
- **Evidence:** U2 GND pin is tied to a 1 MΩ (R1) / 1 µF (C2) node, not the GND plane.
- **Why wrong:** the ESD diode array shunts surge current into its GND pin; through
  1 MΩ (DC) / 1 µF (useless at ESD timescales) there is no low-impedance path to
  ground → ESD protection on D+/D- is defeated.
- **Fix:** route U2 pin 1 directly to GND; remove/relocate R1/C2.

### 6. Audio amp input INR+ hard-grounded instead of AC-coupled
- **Evidence:** DAC0 (PA02, net ANALOG) → C27 → INR-; INR+ tied directly to GND.
- **Why wrong:** TPA2016 differential inputs are internally biased; the standard
  single-ended hookup AC-couples both inputs (signal into one, a matching cap to
  GND on the other). Hard-grounding INR+ imbalances the bias → DC offset / turn-on pop.
- **Fix:** ground INR+ through a cap matching C27 (e.g. 100 nF).

### 7. Amp PVCC (ALARMPOWER) lacks local decoupling at U1
- **Evidence:** bulk supercaps C12/C13 are remote; C18 (220 µF)/C19 are on other rails.
- **Why wrong:** class-D PVCC needs a local low-ESR bulk + HF ceramic at the amp to
  supply pulsed switching current; remote high-ESR caps let PVCC sag/ring → distortion.
- **Fix:** add ≥10 µF (ideally the 220 µF) + 100 nF from ALARMPOWER to GND right at
  U1 pins 4/5 and 11/12; verify C18's intended rail.

### 8. RTC alarm interrupt (U5 ~INT, pin 2) not routed to the MCU
- **Evidence:** RV-3028 ~INT is a dead-end net.
- **Why wrong:** the RTC's open-drain ~INT is meant to wake the MCU on alarm/timer;
  unconnected, alarms can only be caught by continuous I²C polling → MCU can't sleep
  (defeats the low-power/backup-timekeeping design intent).
- **Fix:** route ~INT to a wake-capable GPIO with a pull-up to +3.3 V; configure it as
  an external interrupt in firmware.

### 9. VREFA (PA03) left floating
- **Evidence:** PA03 (external ADC reference) unrouted, undecoupled.
- **Why wrong:** if firmware ever selects the external reference the ADC reads garbage.
- **Fix:** either drive VREFA from a reference + add 100 nF/1 µF, or document that only
  the internal/VDDANA reference may be used. *(Current firmware uses internal ref → low practical impact.)*

---

## 🟡 Minor

### 10. GNSS V_BCKP (U4 pin 5) on main +3.3 V instead of a persistent backup rail
- **Why it matters:** V_BCKP holds the L86's ephemeris/almanac + last fix. On +3.3 V it
  dies with main power → **full cold start every boot** (TTFF ~30 s+). **This is the root
  cause of the firmware "year-2080 / no-fix" cold-start behavior.**
- **Fix:** route V_BCKP to the persistent supercap rail (as the RTC's backup already is),
  or a coin cell / diode-OR'd backup.

### 11. VDDANA not isolated from digital 3.3 V (no ferrite) + missing HF decoupling
- Add a ferrite from +3.3 V to VDDANA with 100 nF + 1 µF at the pin.

### 12. I²C / peripheral ICs have only 10 µF bulk, no 100 nF HF bypass
- Add a 100 nF close to VDD of RV-3028, 24LC512, LIS3DH (VDD & VDD_IO), TPA2016 (keep the 10 µF).

### 13. Unused amp left channel inputs (INL+/INL-) left floating
- Tie INL+/INL- to GND (or 100 nF each). Leaving OUTL open is fine.

### 14. OLED_BL toggled in firmware but not routed to J3
- The backlight/aux control terminates at the MCU only. Harmless for the SH1122 (no backlight);
  either add a J3 pin or drop OLED_BL from firmware.

### 15. LTC3226 (U15) regulated backup output (VOUT) + control pins unused
- The load runs off the raw charge-pump/supercap node → ALARMPOWER is unregulated (sags as caps
  discharge). Intentional if the direct-off-supercap topology was chosen; otherwise wire the
  PowerPath PFET on GATE, route load to VOUT, set LDO_FB/RST_FB.

### 16. LED array current budget vs LTC3226/supercap (verify, not a wiring error)
- Worst-case simultaneous LED (up to ~0.85 A if all sections on) + amp load vs the supercap
  ESR / charger current. Firmware chases one section at a time, so peak is lower; confirm no
  brownout/dimming. If marginal: raise the 80 Ω, or PWM/stagger sections.

---

## ✅ Checked and correct (refuted candidates)
USB-C CC resistors (R2/R3 = 5.1 kΩ pull-downs to GND), GNSS UART crossover
(MCUTX→L86 RXD, MCURX→L86 TXD), LM3671 feedback (FB→VOUT, correct for fixed
variant), SAMD51 VDDCORE inductor L4, LED/buzzer MOSFET gate resistors +
pull-downs, and the crystal being on the correct XIN32/XOUT32 pins.

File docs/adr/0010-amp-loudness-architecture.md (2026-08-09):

# 0010 — Amp loudness architecture: AGC leveling, limiter as volume

Date: 2026-07-14, ceiling re-tuned 2026-08-09 · Status: **Accepted**

## Context
The TPA2016D2 was used as "fixed gain + peak limiter"; loudness = the gain
register, digital volume scaled the DAC stream in parallel. User-supplied
WAV tunes are mastered wildly differently, and a bedside alarm benefits from
a gentle volume ramp.

## Decision
Enable the chip's **AGC at 1:4 compression** so program material is leveled
toward the output ceiling. With AGC active the **output limiter level is the
real volume control**, so:
- volume 0–10 maps to the limiter level: v1 = −6.5 dBV (~28 mW into 8 Ω) …
  v10 = **+7 dBV** (~0.63 W into 8 Ω). The ceiling is deliberately below the
  chip max (+9 dBV): bench measurement (2026-08-09) showed max volume + LED
  chase crossing the nPM1300's **1000 mA battery discharge limit** as the
  AGC wound up — IBATLIM collapses VSYS and resets the device. A USB-only
  higher ceiling was rejected: the limit applies instantly at unplug while
  software reacts in ~10–50 ms, an unwinnable race. See ADR-0014,
- fixed gain stays constant (+6 dB into the AGC),
- the digital (DAC) volume is pinned high — it would otherwise be undone by
  the AGC,
- a **200 Hz 2nd-order Butterworth high-pass** filters the WAV path in
  firmware (AudioEngine, `AUDIO_HPF_HZ`): below the small driver's resonance
  the impedance is at minimum (max current) while the cone barely radiates,
  so deep bass was the most expensive content per mA and the least audible.
  Trimming it lowers the sustained current peaks that threaten the
  nPM1300's IBATLIM (ADR-0014) — and the AGC then spends the energy budget
  on the audible band instead. Builtin melodies (sines ~260 Hz+) bypass it.
  Bench tool: `tools/gen_sweep.py` + the dev IBAT readout map the speaker's
  current-vs-frequency curve in one 30 s pass,
  the set volume over 0/15/30/60 s — configured **per alarm** in the alarm
  editor (weekday alarm can fade in, weekend alarm can blast); snooze
  **re-rings skip the ramp**, and buzzer escalation jumps to full volume,
- the SETUP register's fault/thermal bits are surfaced on System info.

## Consequences
- All tunes play at comparable loudness regardless of mastering.
- Wake-up starts gentle but cannot be slept through (re-ring + escalation
  bypass the ramp).
- Volume perception is now tied to the limiter. The floor cannot go below
  the chip's −6.5 dBV while AGC leveling is active (the AGC lifts material
  toward the ceiling regardless of input gain) — a true whisper mode would
  need compression disabled at low volumes.

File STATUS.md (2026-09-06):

# Project Status Report — GNSS Alarm Clock

_Last updated: 2026-09-06 — **release [v1.0.1](https://github.com/KrHaaland/GNSS_Alarm_Clock/releases/tag/v1.0.1)** (bin + UF2 for both boards); previously [v1.0.0](https://github.com/KrHaaland/GNSS_Alarm_Clock/releases/tag/v1.0.0) published** (bin + UF2 for both boards)_

Custom **SAMD51** board (Adafruit Metro M4 compatible) — the **v2 board
(SAMD51J20A, nPM1300 PMIC, Li-ion, USB-C) is now the primary target**; the
v1 prototype (J19A, supercaps) remains supported. Firmware:
PlatformIO + Arduino + **LVGL 9.5**. This report captures the current state,
what changed most recently, and the open items — hardware and firmware.

---

## 1. Overall status

**Firmware is feature-complete — release v1.0.0 — and running on the v2
board.** Every subsystem is implemented and bench-verified. Open hardware
items are parts in the mail (L86 module, 3 V QSPI flash, pull-down display);
none stop daily use — the clock runs off the battery-backed RTC.

| Subsystem | State | Notes |
|---|---|---|
| Display (NV3007) | ✅ Working | 428×142 landscape, vendor-page init, Y+14 offset, 30 MHz mode 0 |
| GNSS time (L86) | 🔴 Module dying | Works only when heated (4-5 proto cycles); replacement ordered. FW verified OK |
| Power/charging (v2) | ✅ Working | CC-based 500/1500 mA budget, 400/800 mA charge → 4.10 V, 80/70 °C thermostat, ship-mode low-batt policy (ADR-0014/0016) |
| Timezone + DST | ✅ Working | Offline coord→POSIX-TZ, persisted to flash. J20: fine polygon map (404 zones, ~1–2 km borders); J19: coarse |
| RTC (RV-3028) | ✅ Working | U5 hand-soldered onto the prototype; ACKs at 0x52, settings EEPROM verified. Backup switchover (LSM) EEPROM-verified at every boot — factory-fresh chips ship with it OFF |
| Alarms + snooze | ✅ Implemented | Verify ring/re-ring/tap on hardware (§4) |
| Audio (DAC→TPA2016) | ✅ Working | WAV + 3 melodies, digital + amp volume |
| LEDs (3 sections) | ✅ Working | Chase/blink; v2: +5 V boost rail (battery-capable), v1: supercap rail |
| Tunes over USB | ⏳ Awaiting part | v2's U8 is a 1.8 V W25Q128FW (wrong variant) — storage disabled until a JVSIQ is fitted; melodies work |
| Settings persistence | ✅ Working | RV-3028 user EEPROM (38 B packed, v4) — survives reboot, reflash **and format upgrades** (in-place migration, verified) |
| UI (9 screens) | ✅ Working | 4-button nav, true-black theme, starry-night option |

---

## 2. Recent changes

**The C21 polymer lesson (2026-09):** upgrading the 5 V bulk cap to a
low-ESR polymer (560, then 330 uF) destabilized the TPS61023 boost —
oscillation under load dipped VSYS and reset the MCU (USB disconnects
during PC charging; fast charger + all LEDs too; charger thrashing
CC<->trickle). The old 220 uF electrolytic's ESR zero (~1.4 kHz) was
unknowingly the loop compensation the datasheet requires above 40 uF
output capacitance. Elko restored; v3 may use polymer only together with
a ~220 pF feedforward cap across R5. Diagnosis trail: charge-status
decoding -> FW A/B test (exonerated firmware) -> no host over-current ->
component A/B (both polymers fail, elko works). New permanent tool from
the hunt: **Reset cause on System info** (RSTC->RCAUSE decoded).

**Power budget, RTC backup & bootloader hardening (2026-08-03 → 08-09):**
- **IBATLIM is the system's power wall**: the nPM1300 limits battery
  discharge to 1000 mA — exceeding it collapses VSYS below VSYSPOF and
  resets the device (bench-confirmed: full volume + all LEDs cut ~30 s in
  as the amp's AGC wound up, even at 4.1 V). Volume ceiling re-tuned to
  +7 dBV (~500–900 mA worst case measured); a USB-only higher ceiling was
  rejected — IBATLIM applies instantly at unplug, software can't win that
  race (ADR-0010).
- **Dev telemetry**: live `V/mA` readout on the clock face + ringing screen
  (`UI_DEV_IBAT` in Ui.cpp, 1 Hz) — bench tool for the power work above.
- **200 Hz high-pass in the WAV path** (2nd-order Butterworth, per-tune
  sample-rate aware): deep bass drew the most current (speaker impedance
  minimum) for the least sound — trimming it cuts the sustained peaks that
  threaten IBATLIM and lets the AGC spend the budget on audible content.
  Bench-verified with a log-sweep WAV (`tools/gen_sweep.py`) + the mA
  readout; this board's actual IBATLIM trips somewhere above the 1120 mA
  measurement ceiling (spec says 1000 — margin exists but is unstamped).
- **RTC backup switchover now EEPROM-verified at boot** after a flat-battery
  incident reset the RTC: factory-fresh RV-3028s ship with switchover OFF;
  read-back + rewrite until BSM=LSM verifies, PORF surfaced on System info.
- **Bootloader zeroed by a brownout**: repeated VSYSPOF resets during the
  power bench work left one wild NVMCTRL quad-word write at address 0
  (NVMCTRL.ADDR resets to 0) — the bootloader's vector table was zeroed,
  bricking boot (double-fault lockup). Restored via SWD; **BOOTPROT fuse
  now set (16 KB)** so flash hardware refuses such writes.
- **USB flashing repaired**: the stock J19A bootloader reads the dbl-tap
  magic at a different RAM top than the J20 app writes it; the build now
  patches `initiateReset()` to write both — `pio run -t upload` works over
  USB (ADR-0015 update).
- **Settings format v4**: snoozeTotal u32→u24 + spare byte dropped (40→38 B);
  old blocks migrate in place at boot, nothing resets.
- Display flipped 180° (`MADCTL 0xA0`, Y-offset 12) to match the enclosure.
- **Low-battery farewell chirp**: the automatic 3.40 V shutdown announces
  itself — 0.5 s 2200 Hz beep (fixed moderate volume, independent of the
  alarm volume) + a sequential LED sweep — so a forgotten charger is
  noticed. Manual Shutdown stays silent on purpose.
- **Charger-vs-shutdown races fixed**: the nPM1300 refuses ship-mode entry
  with VBUS present — pmic_enter_ship_mode() used to spin forever (frozen
  screen when a charger was plugged during the LOW BATTERY boot gate); it
  now reboots into a normal charging boot after 300 ms. The boot gate also
  polls VBUS during its 4 s message and continues booting if a charger
  appears. Known remaining gap: a 10 s SHPHLD reset WITH USB attached
  power-cycles the PMIC back to its 100 mA default and brownout-loops in
  the bootloader window (amp noise) — bench workaround: unplug first; real
  fix is the planned custom bootloader with an early ILIM write.
- **Ringing screen**: ALARM 1/2 title lifted above the big digits' opaque
  background (same z-order fix as the clock-face symbols).
- **Per-alarm Lights switch** (alarm editor): off = sound-only alarm — no
  LED chase/blink while ringing. Stored in a free alarm-flag bit
  (inverted; old settings read back as on, no migration needed). Also
  saves the chase's ~0.2-0.3 A on battery alarms.

**Power management completed (2026-08-01 → 08-02)** — ADR-0014/0016:
- **CC-following input limit** (500 mA PC / 1500 mA charger) re-applied
  instantly on replug via the nPM1300's GPIO0 IRQ (wired to PA04) — fixed
  a real bug where a replug left the limit at 100 mA, draining the battery
  in the charger.
- **Charging**: setpoint follows the budget (400/800 mA), 4.10 V
  termination, die thermostat bench-tuned 55/45 → **80/70 °C** (measured:
  800 mA continuous, die ~75 °C cold-board / near 80 heat-soaked; thermal
  vias spread ~1 W across the ground plane). VDDCORE moved to the MCU's
  internal buck (~4–6 mA saved).
- **Battery telemetry**: IBAT measurement on the Battery screen (signed
  current = the bench multimeter on-screen); Lights menu (per-section LED
  switches) as its power-measurement companion.
- **Low-battery policy**: ship mode below 3.40 V on battery (paused while
  an alarm rings/snoozes; the ring beats the last percent), fullscreen
  icon + Montserrat-48 "LOW BATTERY" on a too-early wake (J20-only — it
  overflowed the J19), manual Shutdown menu item; BUTTON1/USB wakes, the
  battery-backed RTC keeps time. Field-proven on a genuinely empty cell.
- **SoC**: IR-compensated voltage estimate (160 mΩ path calibrated from
  the observed plug-in jump); a coulomb-counting tracker was tried and
  deliberately reverted (guesses beat by measurements — ADR-0016). Clock
  face shows a drawn battery gauge (red/orange/green fill), no percent.
- Battery (bring-up): LG HG2 18650 3000 mAh unprotected power cell — the
  firmware's cutoff was the protection layer. **Replaced 2026-08-10 by the
  production cell: generic 505060 LiPo, 2000 mAh, with PCM** (firmware's
  3.40 V cutoff still acts first). Higher source impedance than the HG2 —
  SoC path-resistance re-calibration + worst-case audio re-test pending.

**v2 board bring-up (2026-07-22 → 08-01)** — full session log in
`docs/sessions/`. Every subsystem verified on the new board:
- **MCU is a SAMD51J20A** (verified `bossac -i`; schematic symbol says J19A)
  → `metro_m4_j20` is the default build (ADR-0015). Flash 42 %, RAM 60 %.
- **nPM1300 power** (ADR-0014): VBUS limit raised to 500 mA at every boot
  (100 mA OTP default brownout-looped the LED test on a battery-less
  board), charger enabled at 200 mA → 4.10 V, boot-window load clamping
  (L86 reset, amp off, backlight low + soft-start ramp).
- **Battery UI**: SoC% + level-mirroring battery icon + charge bolt on the
  clock face; "Battery" menu screen with live VBAT/state/die-temp.
- **VDDCORE on the internal buck** (`SUPC->VREG.SEL=1`, board has the L4
  inductor): ~4-6 mA saved continuously vs the core's default LDO.
- **Bench findings, all diagnosed on-board**: LIS3DH cold joint (answers at
  0x19 — SA0 strap not effective; FW probes both addresses), L86 cold VCC
  joint (reflowed; **module now failing after 4-5 prototype cycles — trickle
  of NMEA unless heated; replacement ordered**), U8 flash is a 1.8 V
  W25Q128FW (wrong variant, storage disabled until a JVSIQ arrives),
  display module straps BL with a pull-up (full backlight through the
  bootloader phase → battery-less bootloop; replacement display has a
  pull-down), one aborted bossac write left a half-flashed app that
  enumerated but "saw no satellites" — SWD via Atmel-ICE is now the primary
  flash path (ADR-0015).
- **ledtest diag env**: I2C scan + WHO_AM_I, LED sections, GNSS listener
  with reset-pulse aliveness test, QSPI JEDEC probe, nPM1300 unlock.
- Earlier in the window: async DMA display flush (ADR-0012), DMA-paced
  audio (ADR-0013), Sky view (GSV), starry night, Tunes-freeze fix
  (LVGL pool 80 K).

## 2b. Older changes (v1 era)

**Display bring-up (SH1122 → ST7789)** — committed:
- New `DisplayST7789` driver (RGB565, LVGL 9). Panel is a centered sub-window of
  the 320×240 GRAM → window offsets **`ST_X_OFFSET=18` / `ST_Y_OFFSET=82`**.
- **Inversion off** (`ST_INVERSION=0`) — this panel inverts colors with INVON.
- **SPI raised 4 → 24 MHz** — full-frame flush ~86 ms → ~15 ms; big UI smoothness
  win. Synchronous per-byte flush kept (DMA path freezes the MCU via an
  unhandled `DMAC_1` IRQ).
- Gated `DISPLAY_SELFTEST` bring-up tool retained (default 0).
- **Backlight PWM dimming** — `display_set_contrast()` now uses `analogWrite` on
  D11/PA19 (TCC1_CH3), so the brightness slider + dim-after timeout actually dim
  the panel (was on/off before).

**Timekeeping / GNSS:**
- Added `gnss_get_speed_kmph()` and `gnss_get_altitude_m()` (from RMC/GGA, only
  when fixed) and a **Speed / Alt line on the System-info screen**.
- **Fine-grained timezone table** — expanded `kZones[]` from ~32 to **213
  boxes** covering every UTC zone worldwide: multi-zone countries split
  (US/Canada/Mexico/Russia/Brazil/Australia/China-single…) and no-DST
  exceptions (Arizona, Saskatchewan, Queensland/NT/WA, Kaliningrad, Sonora,
  Quintana Roo, Crimea, Easter I., Lord Howe…), with current 2025/26 DST rules
  (Brazil/Mexico/Iran/Turkey no DST, Egypt DST back, etc.). Generated + verified
  region-by-region. A **100+ city coverage audit** then caught and fixed 5
  errors: broad boxes overreaching neighbors (India→Afghanistan, Myanmar→
  Thailand, Egypt→Jordan — re-aligned to real borders) and two missing
  territories (added America/Nuuk, Atlantic/Cape_Verde). Host-tested: 19 cases
  incl. a 13-city offset/DST check + an 8-case border regression guard. Anything
  not in a box falls to a whole-hour longitude estimate, so every coordinate
  resolves. Flash 86.6% → 88.0%.

**UI:**
- Clock face: **centered HH:MM, seconds removed**.
- **Mode selector** (Menu → Mode, cycles in place; settings **v2** — stored
  settings reset once on first boot): Alarm clock / **Speedometer** (GNSS
  km/h as the big figure) / **Altimeter** (GNSS m) / **Game mode** (LIS3DH as
  a USB HID gamepad: tilt = stick, B2–B4 = buttons, B1 = menu; HID interface
  always enumerated, silent outside the mode). Alarms fire in every mode.
  Sim console gained `mov <kmh> [altM]` to exercise the GNSS modes indoors.
- **Shake / tap to wake** — new `accel_moved()` (motion delta on the LIS3DH)
  restores full brightness / resets the dim timer, like a button press.
  Sensitivity `MOVE_THRESHOLD` (~0.6 g) is tunable on the bench.

**I²C:**
- **Bus dropped 400 → 100 kHz.** RV-3028 intermittently failed to ACK at
  400 kHz (board lacks local HF decoupling — HW review #12). Added a gated
  `I2C_SCAN` bus scanner.

**Build targets:** added **SAMD51J20A** envs for the next board revision
(`metro_m4_j20`, `sim_j20`; custom `boards/samd51j20a_metro.json` +
`ld/samd51j20a_flash_with_bootloader.ld`, 1 MB/256 KB). Same firmware: J19
95.2% flash → J20 47.6%. Select via `default_envs` in platformio.ini. J20
must be SWD-flashed until a J20 UF2 bootloader is built.

**Settings storage moved to the RV-3028 user EEPROM** (packed 39-byte image;
coordinates instead of TZ strings, tune-name hashes matched against the TUNES
dir at boot; memory map in README). Survives firmware reflashes — the old
FlashStorage emulation sat inside the app image and was wiped on every update
— and has 4x the write endurance. FlashStorage_SAMD dropped (flash 95.6% ->
93.3%); the 24LC512 is now unused and **leaves the BOM in hardware v2**.
Bring-up found two RV-3028 quirks (chip NACKs I2C during EEPROM busy at POR
and in windows after each programmed byte) — fixed with tolerant busy-wait +
per-byte retry & read-back verify. **User-verified: settings survive both
reboot and reflash.**

**Amp (TPA2016) rework:** AGC 1:4 loudness leveling (all tunes comparable),
volume 0–10 maps to the output limiter across its full range — v1 = −6.5 dBV
(~28 mW) … v10 = +9 dBV (~1.0 W into the 8 Ω speaker, chip max). **Gentle-wake
ramp is per alarm** (alarm editor "Ramp": Off/15/30/60 s — first ring only;
snooze re-rings and buzzer escalation at full volume; packed into spare alarm
flag bits, EEPROM v3). New **Volume slider** on "Disp & sound" (the setting
previously had no UI control). Amp fault/thermal status on System info.

**Random alarm trigger:** per-alarm "Random" (Off/±1/±5/±9 min) — each
occurrence fires at a fresh hardware-TRNG offset around the set time (absolute
-minute targeting, so windows cross hour/day boundaries). Display keeps
showing the nominal time. Packed into spare alarm-flag bits (no EEPROM cost).

**Display swapped to NV3007 (428×142):** new driver (vendor-page init is
mandatory — without the 0xFF 0xA5 register dump the address engine wraps
writes linearly), GRAM 168×428 with Y+14 landscape offset, SPI mode 0,
inversion off. Init cross-verified against five independent driver
codebases (researched via web). Old ST7789 driver kept, selectable via
DISPLAY SELECT in platformio.ini. UI scaled up for the doubled resolution
(fonts 12→16/14/20, wider sliders/dropdowns, taller day-matrix).

**100 px clock font:** generated a Montserrat-Medium subset (" -.0123456789:AEGM",
4bpp, Pillow from lvgl's bundled TTF, LVGL 9.5 fmt_txt layout) for the big
clock/ring figure on the 142 px panel. Montserrat-48 became unreferenced and
is linker-GC'd: flash 95.7% -> 82.9% (net -67 KB) while the clock doubled in
size. Generator approach documented in src/font_clock_100.c header.

**Display speed (NV3007):** SPI 24 → **30 MHz** (SERCOM2 re-clocked from the
120 MHz GCLK0 — the default 48 MHz source can't divide above 24) and the pixel
stream now goes through a **DRE-paced bulk loop** writing straight into the
double-buffered SERCOM data register (back-to-back SCK instead of a per-byte
`SPI.transfer()` RX round-trip). Full-frame flush ~90 → ~26 ms; user-verified
"veldig mye bedre". Follow-ups: LVGL refresh period 30 → 15 ms and render
buffer 24 → 32 rows.

**Async DMA flush (ADR-0012, supersedes 0002):** dedicated DMAC channel
(Adafruit_ZeroDMA — installs the IRQ handlers whose absence caused the 0002
freeze) + **two** 32-row LVGL buffers (RAM 63 %), so rendering overlaps the
transfer and the main loop no longer stalls during flushes. Synchronous
DRE-loop kept as automatic fallback. User-verified on hardware: "displayet
er smooth!"

**DMA-paced audio (ADR-0013):** the per-sample TC2 ISR (22–48 k IRQ/s) is
gone — TC2 overflow now triggers one DMAC beat per sample from a two-half
ping-pong buffer into DAC0, with one IRQ per 2048-sample half. Underrun
guard silences a stale half; per-sample ISR kept as fallback. Verified:
WAV/melodies play cleanly while scrolling the UI — pixels and samples
stream concurrently on two DMAC channels.

**Sky view (GSV):** new screen — polar az/elev plot + SNR bars of every
satellite in view, colored by signal and constellation (GPS/GLONASS). The L86
now emits GSV every 5th fix (PMTK314; full-rate GSV would crowd the 9600-baud
link) and a small in-house parser runs beside TinyGPS++ (which lacks GSV).
Works without a fix — this is the indoor antenna-placement aid.

**Starry night:** optional (Disp & sound) — 26 twinkling stars behind the
clock digits between 22:00 and 06:00, clock mode only. Stored in a spare
flags bit (b6), no EEPROM format bump. Also: AM/PM and unit tags now sit on
the big digits' baseline.

**Post-mortem:** the sky screen's ~50 LVGL objects exhausted the 48 KB LVGL
pool at boot — LV_ASSERT_MALLOC hangs in a loop with a black panel (USB alive
via IRQs, hence the confusing symptom). Pool now 64 KB, RAM 71.7 %.

**Docs:** README refreshed to current reality; this STATUS report added.

---

## 3. Open HARDWARE items

### ✅ RV-3028 RTC (U5) — RESOLVED (was: not populated)
Bus scan showed `0x52` silent because **U5 was never soldered onto this
prototype**. Hand-fitted on the bench; now ACKs at 0x52, the settings
EEPROM survives both reboot and reflash, and **holdover is verified**
(2026-07-21): power-loss → correct time back via the supercaps. The full
RTC chain — timekeeping, backup power, settings storage — works.

### L86 GNSS signals unrouted (new findings)
- **1PPS (L86 pin 6) is a dead-end net** — no hardware pulse-per-second to the
  MCU. This is the most valuable signal for a *GNSS clock* (sub-µs timing vs our
  ~1 s NMEA timestamp). Would need a bodge wire to a spare GPIO.
- **AADET_N (L86 pin 8) unrouted** — no active-antenna presence/short detection.

### Existing HARDWARE_REVIEW findings (unchanged)
See [`HARDWARE_REVIEW.md`](HARDWARE_REVIEW.md). Most relevant:
- 🔴 **#1 LM3671 (U14) VIN/SW swapped** in symbol+copper — *verify on bench*
  (board does run, so measure the 3.3 V rail / U14 temp before acting).
- 🟠 **#10 L86 V_BCKP on main 3.3 V** → full cold start every boot (root cause of
  the "year-2080/no-fix" behavior). Route to the supercap backup rail.
- 🟠 **#8 RV-3028 ~INT unrouted** → alarm/wake only by polling (can't sleep).
- 🟠 D3 flyback diode reversed; C30 VDDCORE cap to +3.3 V not GND; crystal load
  caps C24/C25 10 pF (want ~18–22 pF); USB ESD array U2 ground; amp INR+ /
  PVCC decoupling.

---

## 3½. Hardware v2 — status (built and running!)

The v2 board is assembled and every subsystem is bench-verified (see
`HARDWARE_V2.md` for the full firmware-facing reference). Realized:
SAMD51J20A, nPM1300 (charger 400/800 mA → 4.10 V, power path, USB-C CC),
LM3671 3.3 V + TPS61023 5 V boost (both battery-capable), battery-backed
RTC, battery icon/SoC in the UI. The escalation buzzer was dropped in
hardware (PB16 unconnected).

**Waiting on parts:**
- **L86 GNSS module** — the veteran module (4-5 prototype cycles) now only
  talks when heated; replacement ordered.
- **W25Q128JVSIQ (3 V)** — fitted U8 is the 1.8 V FW variant; storage/TUNES
  disabled until swapped. FW supports the JVSIQ out of the box.
- **Display with BL pull-down** — current module's pull-up burns the
  backlight through the bootloader phase (battery-less bootloop).

**Still open (firmware):**
- Custom **uf2-samdx1 bootloader**: pid.codes identity + early nPM1300
  ILIM write (kills the last battery-less-boot window, ADR-0014/0015).
- Escalation stage on v2: gate the (nonexistent) buzzer on
  `pmic_present()`, or substitute max-volume + LED blitz.
- L86 V_BCKP still on 3.3 V (not battery): GNSS cold-starts after power
  loss — next board spin, along with an L86 load switch and the U8/U18
  schematic symbol tidy-up.

## 4. Open FIRMWARE items

**Verify on hardware (behavior already implemented):**
- Double-tap-to-snooze (LIS3DH, `CLICK_THRESHOLD=32` — tune on hardware).
- Value up/down editing in menus; alarm ring → snooze → re-ring cycle.
- `CAPGOOD` polarity (HIGH = supercaps charged).

**Polish / nice-to-have:**
- **Red gamma** — bright red renders slightly brown; ST7789 gamma table could be
  tuned (cosmetic; UI is white-on-black).
- ~~Async flush (DMA)~~ — **done** (ADR-0012): DMA + double buffering,
  verified on hardware. The display path is now wire-bound; the only lever
  left is a higher SCK (50 MHz — above the NV3007's ~40 MHz ceiling, revisit
  only on the v2 PCB with proper routing).
- **GSV sky-view** — enable GSV + parse per-satellite SNR for an indoor
  reception/antenna-placement screen (high value given indoor use).
- **Escalation timer** restarts on each snooze re-ring (`s_ringStartMs` reset) —
  confirm that's the intended behavior vs. total-elapsed.

**Code hygiene (non-blocking):**
- Stale header comments still say "SH1122" in `main.cpp` / `Ui.cpp` /
  `platformio.ini` (functionally ST7789). *(Being cleaned up.)*
- `TuneStorage.cpp` includes `ff.c` via a fragile relative path into
  `.pio/libdeps/…` — breaks if the lib layout / env name changes.
- Settings have no migration path — a version/magic bump silently resets to
  defaults.

---

## 5. Build / flash quick reference

- Build: `pio run` (default env `adafruit_metro_m4`).
- Tests: `pio test -e native` (timezone/DST engine).
- Flash (SWD/Atmel-ICE): write **`firmware.bin` at `0x4000`** via OpenOCD —
  **never the `.elf`** (overwrites the UF2 bootloader). See [README](README.md).
- Flash (normal): double-tap reset → drag `firmware.uf2` to `METROM4BOOT`.
- Diagnostics: `DISPLAY_SELFTEST` / `I2C_SCAN` (`#define … 1`, rebuild).

**Toolchain pins that matter:** LVGL 9.5.0; Adafruit TinyUSB **2.4.1**
(do not bump — the core bundles 3.1.0; 2.4.1 is the highest that enumerates);
Adafruit SPIFlash 5.1.1; SdFat-Adafruit 2.3.103; TinyGPS++ 1.0.3;
FlashStorage_SAMD 1.3.2; RV-3028-C7 lib 2.1.0.

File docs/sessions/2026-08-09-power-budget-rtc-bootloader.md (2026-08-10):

# Bench session 2026-08-03 → 08-10 — power budget, RTC backup, bootloader

Follow-up bench work on the v2 board (J20 + nPM1300 + LG HG2). Three
investigations that turned out to be one story: the battery discharge limit.

## 1. The IBATLIM discovery (speaker experiments)

Trigger: 2×4 Ω speakers in parallel (2 Ω) instantly reset the device; the
same pair in series (8 Ω) cut out ~30 s into a full-volume tune with all
LEDs on — even at 4.1 V battery.

Root cause: the **nPM1300 limits battery discharge to 1000 mA (IBATLIM,
its maximum setting)**. Exceeding it collapses VSYS below VSYSPOF → hard
reset. The ~30 s delay was the TPA2016's AGC winding program material up
toward the limiter ceiling — draw creeps for the first half minute of
playback. Measured with the new dev telemetry (live V/mA on the clock
face + ringing screen, `UI_DEV_IBAT`): 500–900 mA swings at the re-tuned
ceiling, worst case (all 34 LEDs continuous + bass-heavy tune).

Decisions:
- **Volume ceiling lowered to +7 dBV** (limiter step 27, was chip-max 31):
  the whole 0–10 knob rescales, max now equals the measured-safe level.
- **USB-only higher ceiling rejected**: IBATLIM applies analog-instantly at
  unplug; software reacts in 10–50 ms. Unwinnable race (ADR-0010).
- Speaker guidance: min 4 Ω per amp channel (chip spec); loudness gains
  come free from enclosure sealing + driver sensitivity, not lower
  impedance. Deep bass costs the most mA for the least sound on small
  drivers — master alarm tunes with a ~200 Hz high-pass.

## 2. RTC reset on a flat battery

The RTC lost time when the cell ran flat, despite VBACKUP sitting on VBAT.
Two real gaps found and fixed:
- Factory-fresh RV-3028s ship with **backup switchover disabled**; the
  library nominally sets LSM every boot but nothing ever verified it.
  `rtc_begin()` now reads the config EEPROM back (via Refresh → RAM mirror;
  ReadSingle can't reach 0x37) and rewrites until BSM=LSM + TCE=off
  verifies. System info shows `ok+LSM` / `BKUP=0xNN!` / `POR!`.
- The PORF flag was latched but never read by anyone — now sticky and
  surfaced, so a future reset is attributable.

The actual trigger was most likely a bench-only ground transient (floating
charger hot-plugged while SWD pinned board GND to PC earth). v3 checklist:
buffer cap on VBACKUP (U5.6).

## 3. Bootloader zeroed by a brownout

After the repeated VSYSPOF resets above, the board went dark: **the UF2
bootloader's first 16 bytes (vector table) were zeroed** — SP=0/PC=0 at
boot → double-fault lockup. Exactly one NVMCTRL quad-word (16 B) written
at address 0, which is NVMCTRL.ADDR's reset default: a wild write during
one of the brownout deaths (the firmware itself never touches internal
flash).

Recovery + hardening:
- Bootloader restored over SWD (Adafruit uf2-samdx1 v3.16.0 for Metro M4);
  app region was untouched.
- **BOOTPROT fuse set to 16 KB** (was 0 = unprotected): flash hardware now
  refuses any write/erase in the bootloader region. Clear with
  `atsame5 bootloader 0` before intentional bootloader updates.

## 4. USB flashing repaired (long-standing mystery solved)

ADR-0015's "1200-baud touches reset into the app instead of the
bootloader" got a root cause: the Arduino core writes the stay-in-bootloader
magic at the **compiled chip's** RAM top (J20 → 0x2003FFFC), the stock
J19A-built bootloader reads **its** RAM top (0x2002FFFC). The
`patch_tinyusb_power.py` build script now also patches `initiateReset()`
to write both addresses. `pio run -e metro_m4_j20 -t upload` verified
end-to-end over USB — bossac writes+verifies in ~4 s (~5× faster than
SWD). SWD remains the surgical path (this session was its showcase:
lockup autopsy, bootloader restore, fuses).

## 5. Settings format v4

snoozeTotal shrunk u32 → u24 (caps 16.7 M) and the spare byte dropped:
40 → 38 B packed, 5 B free. Old blocks migrate **in place at boot** via the
established versioned-migration pattern (v1/v2 chain through the same
shift); verified on-device — counters and alarms survived. Little-endian
made it clean: the u24 keeps the u32's three low bytes in place.

Also this window: display flipped 180° (`MADCTL 0xA0`, Y-offset 12) to
match the enclosure mounting.

## 6. Audio high-pass — sub-bass costs mA, not sound (08-09 → 08-10)

Follow-through on the IBATLIM work: deep bass is the most expensive
content per mA (speaker impedance minimum below the driver resonance) and
the least audible on a small driver. A **200 Hz 2nd-order Butterworth
high-pass** now filters the WAV path (per-tune sample-rate aware; builtin
melodies bypass — synth sines ~260 Hz+). The AGC spends the energy budget
on the audible band instead: same loudness, lower sustained peaks.

Bench instrument built alongside: `tools/gen_sweep.py` generates a 30 s
log sweep WAV (20 Hz–20 kHz, equal time per octave, crest factor 1 — the
harshest possible load) that together with the dev IBAT readout maps the
speaker's current-vs-frequency curve in one pass. Measured on this board:
**survives ≥1116 mA sustained** — the IBAT ADC's ceiling at the 1000 mA
limit setting — so this unit's actual IBATLIM sits above spec (Nordic
originally characterized 1370 mA before down-spec'ing to 1000). Margin
noted, not designed against. Also considered and correctly rejected:
polymer bulk caps (ESR hygiene, not amps — µs-scale energy, not the
100 ms a bass note needs) and AGC re-tuning (changes how often you're at
max, not how high max is; only the limiter voltage bounds current
deterministically).

## 7. Per-alarm Lights switch (08-10)

New alarm-editor row: the LED show while ringing (chase + escalation
blink) is switchable per alarm — off = sound-only alarm. Stored in free
alarm-flag bit 5, inverted so old blocks read back as on (no format
bump — the starryNight/jitter trick). Side benefit: saves the chase's
~0.2–0.3 A on battery alarms.

## 8. Production battery fitted (08-10)

The bring-up LG HG2 18650 (3000 mAh, unprotected, ~25 mΩ) was replaced by
the production cell: **generic 505060 LiPo pouch, 2000 mAh, with PCM**.
Charging config kept (400/800 mA = 0.2/0.4C on this cell, 4.10 V
termination, 80/70 °C thermostat). Pending measurements: SoC
path-resistance re-calibration (the ~160 mΩ constant is HG2+holder
specific; generic pouch + PCM is expected notably higher), worst-case
audio re-test (bigger sag), and possibly IR-compensating the low-battery
watchdog with the new constant.

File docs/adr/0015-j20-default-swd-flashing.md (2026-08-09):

# 0015 — SAMD51J20A as default target; SWD-first flashing

Date: 2026-08-01 · Status: **Accepted**

## Context
The v2 board was designed around the schematic's ATSAMD51J19A symbol, but
the fitted chip reports `ATSAMD51x20` via `bossac -i` (1 MB flash / 256 KB
RAM) — the J19/J20 are pin-identical in TQFP64. Running the J19 build left
half the silicon unused and forced repeated memory squeezes (LVGL pool
incidents, font subsetting). Meanwhile, USB-based flashing (1200-baud touch
+ bossac) proved unreliable on the bench: racing re-enumeration, a write
aborted mid-flash (leaving a half-programmed app that enumerated but
misbehaved — worth remembering as a failure mode), and touches that reset
into the app instead of the bootloader.

## Decision
- **`metro_m4_j20` is the default PlatformIO environment** (512 KB → 1 MB
  flash, 192 → 256 KB RAM). The J19 env stays for the v1 prototype.
- **SWD via Atmel-ICE is the primary flashing path**: openocd CMSIS-DAP,
  `firmware.bin` written at **0x4000** (never the `.elf` — its LOAD segment
  at 0x0 overwrites the UF2 bootloader). Fast (~40 KiB/s), deterministic,
  immune to USB enumeration races, and it cannot half-flash silently
  (verify is part of the write).
- Known quirk: openocd's `reset halt` + `reset run` counts as a double-tap
  and parks the board in the bootloader; issue one extra single
  `reset run` (or press reset once) to enter the app.
- USB paths (1200-baud touch, UF2 drag-and-drop) remain as fallbacks when
  no debug probe is attached.

## Update 2026-08-09: USB flashing repaired and promoted
The "touches that reset into the app" mystery was root-caused: the Arduino
core writes the stay-in-bootloader magic at the **compiled chip's** RAM top
(J20: 0x2003FFFC) while the stock J19A-built bootloader reads **its own**
(0x2002FFFC). `tools/patch_tinyusb_power.py` now patches `initiateReset()`
to write both addresses; `pio run -t upload` works reliably over USB (and
bossac verifies ~5× faster than SWD). SWD remains the surgical path —
bootloader repair, fuses, lockup autopsies. Relatedly: after a
brownout-induced wild NVMCTRL write zeroed the bootloader's vector table,
the **BOOTPROT fuse is now set to 16 KB** (clear with `atsame5 bootloader 0`
before intentional bootloader updates).

## Consequences
- Memory ceilings are gone for the foreseeable future (flash 42 %, RAM
  60 % at time of writing); features like a finer timezone polygon map
  (ADR-0003 tooling supports regeneration) become practical.
- The stock Metro M4 bootloader handles the x20 over bossac fine, so the
  old "J20 needs SWD for first flash" caveat is dropped; the custom
  uf2-samdx1 bootloader (pid.codes identity + early PMIC ILIM write,
  ADR-0014) remains planned but is not a blocker.
- CI builds all four envs, so the J19 build cannot silently rot.

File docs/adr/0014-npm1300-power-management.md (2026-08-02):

# 0014 — v2 power management: nPM1300 strategy

Date: 2026-08-01 · Status: **Accepted**

## Context
The v2 board replaces v1's LTC3226 + supercaps with a **nPM1300 PMIC**
(I2C 0x6B): Li-ion charging, USB-C input with CC detection, VBUS→VSYS power
path with battery supplement. Regulation stays external (LM3671 3.3 V,
TPS61023 5 V boost — both VSYS-fed). Hard requirement from the user: the
device must never draw more than **500 mA from a PC USB port**. Battery:
2000–3000 mAh Li-ion, 2-pin (no thermistor; the PMIC's NTC pin has a fixed
10k to GND = constant ~25 °C reading).

The PMIC powers up with a **100 mA VBUS limit** (OTP default, resets on
every VBUS plug) and its charger **disabled** until the host configures it.

## Decision
1. **`pmic_begin()` runs at every boot, as early as possible**, and sets
   the VBUS input limit from the **USB-C CC advertisement**
   (USBCDETECTSTATUS): Default USB / A-to-C cable / PC port → **500 mA**
   (the hard port-protection rule); a detected 1.5/3 A source → **1500 mA**.
   Read-back verified. The PMIC enforces the limit in hardware and
   supplement mode lets the battery cover bursts beyond it. Because the
   limit resets to 100 mA on every VBUS attach, the PMIC's **GPIO0 (wired
   to PA04) is configured as an IRQ output** for VBUS events; the main loop
   services it and re-applies the CC-based limit on replug. The re-apply is
   **deferred, not immediate**: reconfiguring in the attach IRQ raced the
   PMIC's own attach sequence (CC still classifying, read-back mismatch —
   surfaced as "RAISE FAILED" on the Battery screen with the limit stuck
   low). `pmic_task()` runs a pass ~300 ms after the event and a second at
   ~1.5 s (late CC settle), retrying every 1.5 s while verification fails.
2. **Boot-window load clamping**: before the I2C transactions (~2–3 ms),
   firmware's first instructions clamp every reachable load — L86 held in
   reset (it hangs directly on 3.3 V, no enable pin, bursts ~100 mA
   acquiring), TPA2016 forced off (R68 pulls it ON by default), display
   backlight driven low (some modules strap BL with a pull-up: a floating
   PA19 means full backlight through the whole bootloader phase). The
   backlight then **soft-starts** (PWM ramp ~100 ms) in display_init().
3. **Charger config**: 400 mA charge *setpoint* — the PMIC prioritizes
   system load in hardware and gives charging whatever remains of the
   input budget (~325–350 mA at the measured ~165 mA system draw), so the
   setpoint is a max, not a demand. Terminate at **4.10 V** (user choice:
   the clock lives on the charger; undercharging markedly extends cell
   life), NTC type 10k. A **die-temperature thermostat** pauses charging
   at 80 °C and resumes at 70 °C (chip default 110/100; bench-tuned
   upward from 55/45 as charge rates grew). **Measured equilibrium at 800 mA:** die ~75 °C
   with a cool board, creeping toward 80 °C once the whole PCB is
   heat-soaked (the thermal-via field under the PMIC spreads the ~1 W
   across the ground plane — case stays comfortably warm). Near the
   threshold the thermostat duty-cycles briefly, trading a little charge
   time for temperature — accepted behavior — tight enough that the
   enclosure stays cool and the charge rate self-regulates. The charge
   setpoint itself follows the detected budget: 400 mA on 500 mA
   sources, 800 mA on 1.5/3 A sources (0.13C/0.27C on the LG HG2). Charger enabled
   only after current + termination + thresholds are set.
4. **SoC estimate**: linear voltage map 3.5 V → V_term via
   `pmic_soc_percent()` — one shared implementation for the clock-face
   battery row and the Battery screen. Reads high while charging; good
   enough for a status glance, no fuel-gauge pretensions.
5. **MCU core runs on the internal buck regulator** (`SUPC->VREG.SEL=1`,
   first instruction in `setup()`): the Arduino core defaults to the LDO,
   but the board carries the VSW inductor (L4). Saves ~4–6 mA at 3.3 V
   continuously and trims the MCU's draw inside the 100 mA power-up
   window; becomes proportionally more valuable when a sleep/night mode
   is introduced.
6. **Battery-less boot is out of scope on USB-A**: the UF2 bootloader phase
   (~0.5–1 s) runs before any application code, inside the 100 mA window,
   with the un-clampable base load (MCU + L86 + pulled-on amp + panel) at
   ~100–120 mA. Remedies, in order of practicality: keep a battery fitted
   (the design assumption); use a USB-C→C cable from a 1.5/3 A source (the
   PMIC reads the CC advertisement autonomously, before any code); bake the
   ILIM write into the planned custom uf2-samdx1 bootloader; add inrush
   limiting/load switches on the next board spin.

7. **Low-battery policy (ship mode)**: on battery only — never on a
   charger, and never while an alarm is Ringing/Snoozed (the LED+speaker
   load sags VBAT 50–100 mV and would false-trigger; waking someone beats
   the last percent of battery) — three consecutive 10 s readings under
   3.40 V enter ship mode (<500 nA, battery cut from VSYS, RTC keeps time
   on VBAT). Woken below 3.45 V without a charger: fullscreen
   "LOW BATTERY" for 4 s, then back to ship mode. A menu "Shutdown" item
   (OK-confirmed, refused on USB power) enters the same state manually.
   Wake is BUTTON1 (=SHPHLD) or USB attach.
8. **Battery telemetry**: IBAT measurement rides on every VBAT ADC round;
   the Battery screen shows signed current, the active input limit, charge
   state and die temperature — the bench multimeter lives on-screen.

## Consequences
- Any future code that adds a load at boot must either run after
  `pmic_begin()` or be added to the clamp block.
- On 1.5/3 A sources the limit is 1500 mA, so charging + alarm peaks are
  fully USB-fed; the 400 mA charge setpoint (not the input limit) is then
  the charging bottleneck, by choice.
- The fixed-10k NTC means no real temperature protection — acceptable for
  a stationary indoor clock at a 400 mA setpoint with the 55 C thermostat.
- VBUS replug always reverts to 100 mA until `pmic_begin()` runs — device
  behavior right after plug-in (before boot completes) stays budget-bound.

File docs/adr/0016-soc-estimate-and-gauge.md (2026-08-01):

# 0016 — Battery SoC: measured-only estimate behind an approximate gauge

Date: 2026-08-02 · Status: **Accepted** · Related: [0014](0014-npm1300-power-management.md)

## Context
The clock face needs a battery indicator. The nPM1300 has no hardware
fuel gauge — it provides raw VBAT/IBAT/die-temp. Nordic's nRF Fuel Gauge
library was evaluated and **rejected on principle: it is a closed-source
precompiled binary** (also: it wants a characterized battery model and a
battery-temperature input the board doesn't have). The firmware stays
fully open source.

A naive linear voltage→SoC map mis-read badly around charging: plugging a
charger lifted the terminal voltage (I·R + polarization), showing an
instant +8 % at 350 mA and +20 % at 800 mA.

## Decision
1. **SoC = IR-compensated voltage, nothing else.**
   `V_ocv ≈ V_meas − I_meas × 160 mΩ`, linear 3.5 V → V_term. The 160 mΩ
   is the whole battery path as seen from the PMIC's VBAT pin (LG HG2
   cell ~25 mΩ; the rest is holder contacts + wiring) and was calibrated
   from the observed plug-in jump itself. Every displayed value derives
   from a present-moment measurement — no history, no stored state.
2. **A coulomb-counting tracker was built, shipped, and deliberately
   reverted the same day.** Integrating measured IBAT against the cell
   capacity fixed the plug-in jump but replaced one measured artifact
   with layered guesses: the anchor error propagates, real capacity at a
   4.10 V termination is unknown (and ages), the estimate seams visibly
   when switching models at unplug, and a reboot mid-charge re-anchors
   wrong. Verdict (user): honest-but-disturbed beats smooth-but-guessed.
3. **The clock face shows no percent number.** False precision confuses;
   instead a **drawn battery gauge** (white 2 px frame + nub — matching
   the true-black/white aesthetic) with a fill bar whose width tracks the
   estimate and whose color grades **red < 20 % / orange < 50 % / green**.
   A charge bolt appears while charging — which is also the honest signal
   that the reading is elevated (~15–20 % at 800 mA; known, accepted).
   The Battery menu screen keeps full numeric detail (V, signed I, state,
   die temp, active input limit) for diagnostics.
4. Status symbols live in a flex row lifted above the clock label in
   z-order: the true-black theme (`blacken()`) gives every object an
   opaque black background, and the big digits' box otherwise clips
   overlapping symbols.

## Consequences
- SoC accuracy is honest-approximate (±10–15 %, worse while charging) —
  the gauge presentation makes that acceptable; nothing pretends to know
  better than the measurement.
- The 160 mΩ constant is board-specific (mostly holder contacts): a new
  holder or battery type means re-checking the plug-in jump.
- If real accuracy is ever wanted: characterize the cell and implement a
  proper (open-source) model — not more layered heuristics.

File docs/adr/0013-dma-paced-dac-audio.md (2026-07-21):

# 0013 — DMA-paced DAC audio playback

Date: 2026-07-21 · Status: **Accepted** · Related: [0012](0012-async-dma-display-flush.md)

## Context
Audio playback (WAV from QSPI + builtin melodies) was paced by a TC2 ISR
firing **once per sample** — 22 050–48 000 interrupts per second — popping a
lock-free ring buffer into DAC0. That worked, but burned a few percent CPU
in pure interrupt overhead, added constant IRQ jitter, and the display's new
async DMA flush (ADR-0012) proved the DMAC + Adafruit_ZeroDMA path safe.

## Decision
Let the DMAC move samples instead of the CPU:

- **TC2 stays the sample-rate pacer** (MFRQ at the WAV's rate, IRQ disabled);
  each overflow raises `TC2_DMAC_ID_OVF`, triggering **one halfword beat**
  ring → `DAC->DATA[0]`.
- The ring is now a **two-half ping-pong buffer** (2 × 2048 samples, same
  8 KB as before): the two descriptors are linked in a loop with
  `BLOCKACT=INT`, so the channel plays A → B → A … continuously and the CPU
  gets **one IRQ per half** (~93 ms at 22.05 kHz) instead of one per sample.
- The half-complete IRQ frees the played half for `audio_task()` to refill.
  **Underrun guard:** if the half now starting was never refilled, the IRQ
  overwrites it with midpoint silence — stale audio never loops audibly
  (the analog of the old ISR's midpoint hold).
- Drain (end of a non-looping source) pads the final half with silence and
  stops after both queued halves have played.
- **Fallback:** if DMA channel allocation fails, `audio_begin()` re-enables
  the per-sample TC2 ISR, which walks the same halves.

## Consequences
- CPU cost of playback drops to ~zero; no per-sample IRQ jitter. Together
  with ADR-0012 the ring screen is interrupt-quiet: the DMAC streams pixels
  and samples concurrently while the CPU only decodes WAV and runs LVGL.
- Volume/content changes take effect within ~one half (~0.1–0.2 s), same
  order as the old 4096-sample ring.
- Two DMAC channels now in use (display=0, audio=1); audio's single-beat
  triggers interleave freely with the display's stream.
- Verified on hardware 2026-07-21: melodies + WAV play cleanly while
  scrolling the UI.

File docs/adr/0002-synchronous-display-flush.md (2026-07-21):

# 0002 — Synchronous per-byte display flush (no DMA)

Date: 2026-07-05 · Status: **Superseded by [0012](0012-async-dma-display-flush.md)**

## Context
The ST7789 flush originally used the SAMD51 SPI DMA path (4-arg
`SPI.transfer`). On this core the DMA completion fires **DMAC channel-1's
IRQ, which has no handler installed** — the CPU lands in `Dummy_Handler`'s
infinite loop: display dead, USB dead, MCU frozen. Diagnosed over SWD
(PC parked in `Dummy_Handler`).

## Decision
Stream pixels with **synchronous per-byte `SPI.transfer`** at 24 MHz and
accept ~15 ms per full-frame flush. Do not enable DMA without first
installing proper DMAC IRQ handlers.

## Consequences
- Absolute stability; LVGL partial rendering keeps typical flushes small.
- ~15 ms of blocking CPU per full-screen redraw (menu transitions) — fine in
  practice at 24 MHz.
- A future optimization (direct SERCOM register loop or DMA-with-handler)
  can halve it if ever needed.

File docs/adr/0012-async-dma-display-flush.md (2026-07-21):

# 0012 — Async DMA display flush with double buffering

Date: 2026-07-21 · Status: **Accepted** · Supersedes: [0002](0002-synchronous-display-flush.md)

## Context
ADR-0002 banned DMA after the SPI library's own DMA path (4-arg
`SPI.transfer`) froze the MCU: its completion fired **DMAC channel-1's IRQ,
which had no handler installed**, parking the CPU in `Dummy_Handler`. The
synchronous flush that replaced it was later upgraded to a DRE-paced SERCOM
register loop at 30 MHz (wire speed, ~26 ms full frame on the NV3007) — but
it still blocks: LVGL cannot render the next strip while the previous one is
on the wire, and the main loop (GNSS parsing, buttons, WAV feed) stalls for
the duration of every flush.

The root cause of the 0002 freeze was the *missing handler*, not DMA itself.

## Decision
Flush the NV3007 asynchronously with a dedicated DMAC channel via
**Adafruit_ZeroDMA** (bundled with the core), which installs handlers for all
five SAMD51 DMAC IRQ lines — the exact piece missing in the 0002 incident:

- One channel, beat-triggered on `SERCOM2_DMAC_ID_TX`, byte beats, one
  descriptor rewritten per flush (`changeDescriptor` + `startJob`). A 32-row
  strip is 27 392 beats, under the 65 535-beat descriptor cap.
- **Two 32-row LVGL buffers** (2 × ~27 KB, RAM 49 → 63 %): `flush_cb` starts
  the DMA job and returns; LVGL renders the next strip into the other buffer
  while the transfer runs.
- The completion IRQ waits out the shift register (TXC, <1 µs), drains the RX
  side and clears BUFOVF/ERROR (so polled `SPI.transfer` keeps working for
  command bytes), raises CS, and calls `lv_display_flush_ready()`.
- **Fallbacks:** if channel allocation or `startJob` fails, the driver falls
  back to the synchronous DRE-paced loop — the display never goes dark over a
  DMA problem. `display_power()` (and `flush_cb` itself, belt-and-suspenders)
  wait out an in-flight transfer before touching the bus.

## Consequences
- Rendering and transfer overlap: full-screen redraws drop from
  render + ~26 ms to ~max(render, 26 ms); scroll/animation frames more easily
  fit the 15 ms refresh tick.
- The CPU is free during transfers — audio feed, GNSS parsing and button
  polling no longer stall behind a flush (most visible on the ring screen).
- +27 KB RAM for the second buffer (63 % on the J19; a non-issue on the
  J20's 256 KB).
- Anything new touching SERCOM2 or the render buffers outside `flush_cb`
  must call `dma_wait_idle()` first.
- Verified on hardware 2026-07-21: menus, fast screen changes, ring screen
  with audio — stable and visibly smoother ("displayet er smooth!").

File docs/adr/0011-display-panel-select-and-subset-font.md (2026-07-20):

# 0011 — Compile-time panel select + subset clock font

Date: 2026-07-14 · Status: **Accepted**

## Context
The prototype's ST7789 (284×76) was replaced by an NV3007 bar TFT (native
142×428, driven landscape 428×142) on the same SPI pins. The NV3007 is not
init-compatible: without its vendor register dump (behind the `0xFF 0xA5`
page unlock) the address engine ignores windows and wraps writes linearly
across the glass — bench-observed as colored bands. It also requires SPI
mode 0 and has a GRAM inset (168×428, visible columns offset 12/14).
Separately, the old 48 px clock figure drowned on the 142 px-tall panel,
and LVGL's built-in fonts stop at 48 px.

## Decision
1. **One display API, compile-time panel select.** Both drivers implement the
   same four functions + `DISP_W/H`; `Display.h` picks the driver from a
   build flag (`DISPLAY SELECT` in platformio.ini, NV3007 default, ST7789 for
   the v1 board). The rest of the firmware is panel-agnostic; the UI reads
   `DISP_W/H`.
2. **NV3007 init is the cross-verified vendor sequence** (five independent
   driver codebases agree), kept byte-exact including undocumented registers
   (`0x46 0x10`, doubled `0xEC`). Landscape MADCTL 0x60 with RASET+14.
3. **Big clock figure via a generated subset font**: `font_clock_100.c` is a
   Montserrat-Medium 100 px subset of the 18 characters the big label can
   show, generated with Pillow from lvgl's own bundled TTF directly in the
   LVGL 9.5 `fmt_txt` layout (4bpp continuous packing, adv_w in 1/16 px,
   FORMAT0_TINY cmap, no kerning) — no node/lv_font_conv dependency.

## Consequences
- Panel swaps are a driver file + one flag; bring-up tooling
  (`DISPLAY_SELFTEST` patterns) is part of each driver.
- Retiring both Montserrat-48 users made the 90 KB full-ASCII font
  linker-GC'd: the clock **doubled in size while flash dropped 95.7% → 82.9%**.
  The same subsetting technique is available if flash gets tight again.
- NV3007 quirks to remember: SPI mode 0 only; partial writes can half-light
  adjacent pixels for RGB channel values 1–31 on black (LVGL strip flushes
  avoid it); GRAM readback over SPI does not work.

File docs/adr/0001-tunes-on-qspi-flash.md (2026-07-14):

# 0001 — Tune storage on QSPI flash + USB mass storage

Date: 2026-07-04 · Status: **Accepted**

## Context
The board carries two candidate "EEPROMs" for alarm tunes: a 24LC512
(64 KB, I²C) and a QSPI serial flash (4 MB on the schematic; assembled
boards carry a 16 MB Winbond W25Q128). Tunes are sampled audio — seconds
of WAV at 22 kHz already exceeds 64 KB.

## Decision
Use the **QSPI flash** for tunes, formatted FAT12 and exposed to the host as
a **USB mass-storage drive** (`TUNES`) for drag-and-drop upload. Leave the
24LC512 unused (later repurposed candidate → superseded by ADR-0004/0008).

## Consequences
- Minutes of audio instead of seconds; standard Adafruit SPIFlash/SdFat stack.
- Tune upload requires no custom tooling — any file manager works.
- WAV playback is refused while the USB host owns the drive (`storage_busy`).
- The 24LC512 became dead weight → eventually dropped from the v2 BOM.

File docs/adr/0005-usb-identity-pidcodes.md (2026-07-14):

# 0005 — USB identity via pid.codes

Date: 2026-07-13 · Status: **Accepted**

## Context
The firmware shipped with Adafruit's VID/PID (0x239A:0x8020, Metro M4), so
hosts displayed "Adafruit …". Own VID costs ~$6000 (USB-IF); pid.codes hands
out PIDs under VID 0x1209 to open-source projects, and reserves
0x0001–0x0010 as free-for-testing.

## Decision
Enumerate as **0x1209:0x0001** (pid.codes test PID) with descriptor strings
"K. Haaland / GNSS Alarm Clock", MSC INQUIRY vendor "KH", and **MaxPower
500 mA** (the clock charges storage caps / future Li-ion from VBUS). The
Adafruit bootloader pairs stay in the board `hwids` so PlatformIO's upload
port-hunting still works.

## Consequences
- No "Adafruit" anywhere in app mode; upload/monitor flows unchanged.
- The test PID is shared by definition — register a permanent PID via a
  pid.codes PR (requires public OSI-licensed repo) before distributing.
- Bootloader mode still enumerates as 239A until a custom uf2-samdx1 is
  built (planned with the J20 bootloader, ADR-0008).
- MaxPower required patching TinyUSB 2.4.1 (hardcoded 100 mA) via
  `tools/patch_tinyusb_power.py` + `board_build.usb_power` (the builder's
  own define otherwise wins over `build_flags`).

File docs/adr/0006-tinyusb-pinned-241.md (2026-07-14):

# 0006 — TinyUSB pinned to 2.4.1

Date: 2026-07-04 · Status: **Accepted**

## Context
The Adafruit SAMD core bundles its own TinyUSB copy. Relying on the bundled
copy broke enumeration (device descriptor read error -110); forcing 3.x via
lib_deps clashes with the bundled copy (TU_RESERVED/TU_COUNTER redefinitions).

## Decision
Pin `adafruit/Adafruit TinyUSB Library@2.4.1` — the newest version that
enumerates cleanly alongside this core.

## Consequences
- Stable CDC+MSC+HID composite; do not bump without re-testing enumeration.
- The build compiles **two** copies of some TinyUSB sources (lib_deps + core
  bundle) and the linker may pick either — patches must be applied to both
  (see `tools/patch_tinyusb_power.py`).

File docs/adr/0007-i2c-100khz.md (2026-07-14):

# 0007 — I²C bus at 100 kHz

Date: 2026-07-05 · Status: **Accepted**

## Context
At 400 kHz the RV-3028 intermittently failed to ACK. The hardware review
(finding #12) notes the board lacks local HF decoupling at the I²C devices.

## Decision
Run the bus at **100 kHz** (standard mode). All devices (RTC 0x52, accel
0x18, EEPROM 0x50, amp 0x58) are registers-only, low-rate peripherals.

## Consequences
- Rock-solid bus; total traffic is tiny (poll accel at 50 Hz, RTC on sync).
- Revisit only if v2 adds HF bypass caps and a bandwidth need appears.

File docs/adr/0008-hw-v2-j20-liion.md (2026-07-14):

# 0008 — Hardware v2: SAMD51J20A + Li-ion

Date: 2026-07-13 · Status: **Accepted (planned)**

## Context
The J19A's 512 KB flash sits at ~93 % with fonts, LVGL and timezone data.
Supercaps limit alarm loudness duration and provide no true portability.

## Decision
v2 swaps in the pin-compatible **SAMD51J20A** (1 MB flash / 256 KB RAM,
build targets `metro_m4_j20`/`sim_j20` already in-tree with custom board
JSON + linker script) and replaces the supercaps with a **Li-ion cell +
USB charger** (power-path topology recommended; MaxPower 500 mA already
declared). The **24LC512 leaves the BOM** (ADR-0004).

## Consequences
- Flash pressure gone (~47 %); room for font subsetting to be optional.
- Firmware work queued for the schematic: charger status pins replace
  CAPGOOD, battery icon/percentage, low-battery behavior, RTC VBACKUP and
  L86 V_BCKP from the battery (fixes GNSS cold-start, HW review #10).
- A J20 uf2-samdx1 bootloader build is needed for UF2 drag-and-drop
  (SWD flashing works meanwhile) — good moment to bake in the pid.codes
  identity (ADR-0005).

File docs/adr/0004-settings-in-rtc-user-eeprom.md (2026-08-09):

# 0004 — Settings in the RV-3028 user EEPROM (packed 38 B)

Date: 2026-07-14, format v4 2026-08-09 · Status: **Accepted** (supersedes
internal-flash storage)

## Context
Settings originally lived in SAMD51 internal flash via FlashStorage_SAMD.
That storage array sits **inside the app image** (0x4C000), so every firmware
reflash wiped alarms/zone/counters. Alternatives: the idle 24LC512 (1M
cycles, but leaving the v2 BOM) or the RTC's 43-byte user EEPROM (~100k
cycles, survives reflash by construction, chip must exist anyway).

## Decision
Pack settings into a **38-byte image in the RV-3028 user EEPROM** (map in
README). Derived data is not stored: TZ strings re-derive at boot from
packed lat/lon centidegrees or the manual GMT-ladder index; alarm tune
filenames pack as 16-bit FNV-1a hashes matched against the TUNES directory.
Checksum written last so torn writes invalidate the block.
Format changes migrate **in place at boot** (versioned branches in
`settings_begin()` — v1→v3 ramp moves, v3→v4 snoozeTotal u32→u24 + one-byte
shift), so users never lose stored settings to an upgrade.

## Consequences
- Settings survive power loss **and reflashes** (user-verified both).
- 24LC512 can leave the v2 BOM; FlashStorage dependency dropped (−12 KB).
- Bench-found chip quirks are handled in `RtcRV3028.cpp`: the RV-3028
  **NACKs all I²C while its EEPROM engine runs** (POR auto-refresh >100 ms;
  short windows after each programmed byte) → tolerant 300 ms busy-wait,
  per-byte retry (≤5×) and read-back verification.
- Writes are slow (~16 ms/byte) — irrelevant at a-few-bytes-a-day rates.

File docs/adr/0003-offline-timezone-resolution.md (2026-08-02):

# 0003 — Offline timezone: polygons → boxes → longitude fallback

Date: 2026-07-06 (boxes), 2026-07-12 (polygons), 2026-08-02 (dual resolution) ·
Status: **Accepted**

## Context
The clock must derive local time (incl. DST) from GNSS coordinates with **no
network**. Full IANA border data is far too large for an MCU; a naive
longitude formula gets whole countries wrong.

## Decision
Three layers, first hit wins:
1. **Polygons**: real IANA borders from timezone-boundary-builder,
   simplified to int16 centidegrees, smallest-area-first so enclaves win.
   Generated by `tools/gen_tz_polys.py`, hand-refinable in
   `tools/tz_polygon_editor.html`. **Two resolutions of the same map**,
   picked at compile time by flash size: the J20 (1 MB) includes
   `TimezonePolyDataFine.h` (eps 0.015° ≈ 1.7 km worst-case, 404 zones /
   927 polygons / 56k vertices, ~250 KB — close to both the 1.1 km int16
   quantization floor and the uint16 vertex-index ceiling); the J19
   (512 KB, ~85 % full) keeps the coarse `TimezonePolyData.h`
   (eps 0.20°, ~383 zones, ~57 KB).
2. **Boxes** (`kZones[]`, 214): hand-curated rectangles, exceptions-first
   (Arizona, Saskatchewan, Kaliningrad, …) — also the fallback data set.
3. **Longitude**: `round(lon/15)` → whole-hour offset, no DST. Every
   coordinate resolves.
Zones carry **POSIX TZ strings** evaluated at runtime by a host-unit-tested
parser (`Timezone.*`, `pio test -e native`).

## Consequences
- Correct offset + DST for essentially every populated place, offline.
- POSIX strings with non-`M` DST rules are unsupported by the evaluator —
  the generator sanitizes them to fixed offsets (found via Morocco).
- Border precision is ~km-level (simplification); offsets rarely differ
  across a border anyway. Manual GMT-ladder override exists in the menu.

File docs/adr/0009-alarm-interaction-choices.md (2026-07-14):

# 0009 — Alarm interaction choices

Date: 2026-07-05..13 · Status: **Accepted**

## Context
Several small behavioral decisions shape how the alarm feels; each had a
bench-found reason.

## Decision
- **Double-tap** (not single-tap) snoozes: the speaker's own vibration
  triggers single-tap detection; the LIS3DH click path also needs its
  high-pass filter enabled (CTRL_REG2=0x84) or gravity sits at the
  threshold and fires continuously.
- Taps are ignored the first **2 s** of each ring (stale-tap drain +
  arm delay) so a bump can't instantly snooze.
- **daysMask 0 == daily** (0x7F) — an alarm with no days selected still
  rings rather than silently never firing.
- A newly-due alarm **takes over an active snooze** instead of being
  swallowed; stopping during the trigger minute cannot re-fire it.
- Escalation (power buzzer after N min) restarts its countdown on each
  snooze re-ring; auto-silence after 15 min.
- Every snooze increments the persisted **shame counter** (week + total),
  shown on the ringing screen and System info.
- **Random trigger** (per alarm, ±1/±5/±9 min): each occurrence rolls a fresh
  offset from the SAMD51's hardware TRNG; the target is an absolute
  local-epoch minute so the window crosses hour/day boundaries correctly,
  and the UI keeps showing the nominal time (no cheating).

## Consequences
Predictable wake-up behavior with the failure modes (vibration self-snooze,
forgotten day-mask, swallowed alarms) engineered out.

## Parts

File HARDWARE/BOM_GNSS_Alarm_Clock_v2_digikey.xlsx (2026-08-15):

GNSS Alarm Clock v2 - Bill of Materials
Generated from HARDWARE/GNSS_Alarm_Clock.kicad_pcb, 2026-08-10. 146 components, 38 unique parts. Resistor value notation normalized (schematic mixes 100KΩ/100k/100kΩ).
Designators | Qty | Value / Part | Price | Line total (NOK) | Digikey Partnumber | Notes
C1, C3, C4 | 3 | 22uF | 2.99 kr |  | 1276-CL21A226MAYNNNECT-ND | Samsung CL21A226MAYNNNE. BACKORDER: 0 pa lager, paafyll ~15-09-2026 (22uF/0805 bredt restordret)
C2, C5, C26 | 3 | 1uF | 1.54 kr |  | 399-C0805C105K3RACTUCT-ND | KEMET C0805C105K3RACTU
C6, C7, C8, C9, C10, C11, C12, C16, C17, C19, C20, C22, C28, C29 | 14 | 10uF | 2.22 kr |  | 445-7644-1-ND | TDK C2012X5R1C106K085AC (905 pa lager - nok til 14 stk)
C13 | 1 | 4.7uF | 2.80 kr |  | 445-4116-1-ND | TDK C2012X5R1E475K125AB
C14, C15, C27 | 3 | 100nF | 0.96 kr |  | 1276-1003-1-ND | Samsung CL21B104KBCNNNC
C18, C21 | 2 | 220uF | 7.72 kr |  | P15084CT-ND | Bulk electrolytic - polymer upgrade candidate (e.g. Nichicon RSA series), 10V rating for the VSYS-side position. | Panasonic EEE-FT1A221AP (elko). Polymer-alternativ: Nichicon RSA0J331MCN1GS = 493-7370-1-ND, 10,61 kr, god lagerstatus
C24, C25 | 2 | 10pF | 1.06 kr |  | 732-7846-1-ND | Wurth 885012007051 (Samsung-originalen utgatt)
J1 | 1 | USB4110GFA | 12.25 kr |  | 2073-USB4110-GF-A-1-ND
J3 | 1 | SWD-Connector_3220-10-0100-00 | 5.69 kr |  | 1175-1627-ND | CNC Tech 3220-10-0100-00
J4 | 1 | B8B-XH-A | 2.89 kr |  | 1651049
J6, J7 | 2 | B2B-PH-K-S | 1.06 kr |  | 926611 | Battery connector - production cell: 505060 LiPo 3.7V 2000mAh with PCM. | pris per stk
L1 | 1 | 2.2uH | 5.21 kr |  | 445-VLCF4020T-2R2N1R7CT-ND | TDK. BACKORDER: paafyll ~03-09-2026
L2 | 1 | 1uH | 4.15 kr |  | 445-6683-1-ND | EQUIVALENT: TDK VLS4012ET-1R0N for YXMAA0412-1R0M (1uH 4x4x1.2mm 2.5A) - NB: NRND
L4 | 1 | 10uH | 2.70 kr |  | 490-LQH32CN100K33LCT-ND | EQUIVALENT: Murata LQH32CN100K33L 1210 (LQH31CN utgatt, dette er Muratas erstatning)
LED1, LED2, LED3, LED4, LED5, LED6, LED7, LED8, LED9, LED10, LED11, LED12, LED13, LED14, LED15, LED16, LED17, LED18, LED19, LED20, LED21, LED22, LED23, LED24, LED25, LED26, LED27, LED28, LED29, LED30, LED31, LED32, LED33, LED34 | 34 | OR-PL020W | 3.86 kr |  | 160-1725-1-ND | ADVARSEL: OR-PL020W er en SIDE-EMITTER 3.8x1.2mm (LCSC-datablad) - LTW-670DS (PLCC-2 toppemitter) er FEIL pakketype. Finn side-view hvit LED eller kjop originalen fra LCSC (C205440) ved restock. Pris her gjelder LTW-670DS.
R1, R8, R9, R10 | 4 | 1MΩ | 0.96 kr |  | 311-1.00MCRCT-ND | Yageo RC0805FR-071ML
R4, R12 | 2 | 100kΩ | 0.96 kr |  | 311-100KHRCT-ND | Yageo RC0603FR-07100KL
R5 | 1 | 732kΩ | 0.96 kr |  | 311-732KHRCT-ND | Yageo RC0603FR-07732KL
R6, R7 | 2 | 4.7kΩ | 0.96 kr |  | 311-4.70KCRCT-ND | Yageo RC0805FR-074K7L
R13, R67 | 2 | 100kΩ | 0.96 kr |  | 311-100KCRCT-ND | Yageo RC0805FR-07100KL
R15, R54, R56 | 3 | 470Ω | 0.96 kr |  | 311-470CRCT-ND | Yageo RC0805FR-07470RL
R16, R18, R55, R57, R58, R63, R68 | 7 | 10kΩ | 0.96 kr |  | 311-10.0KCRCT-ND | v3 change queued: amp ~SD pull-up should become pull-DOWN (boot noise). | Yageo RC0805FR-0710KL
R20, R21, R22, R23, R24, R25, R26, R27, R28, R29, R30, R31, R32, R33, R34, R35, R36, R37, R38, R39, R40, R41, R42, R43, R44, R45, R46, R47, R48, R49, R50, R51, R52, R53 | 34 | 80Ω | 0.96 kr |  | 311-80.6CRCT-ND | Yageo RC0805FR-0780R6L - 80.6 ohm E96 (80 ohm finnes ikke i E96; 0,75% avvik)
R66 | 1 | 1kΩ | 0.96 kr |  | 311-1.00KCRCT-ND | Yageo RC0805FR-071KL
SW1, SW2, SW3, SW4, SW5 | 5 | TS-1187A-B-A-B | 3.47 kr |  | 1146840 | EQUIVALENT: C&K PTS645SM43SMTR92 6x6 SMD tact (TS-1187A-B-A-B ikke hos DigiKey); pris per stk
U1 | 1 | TPA2016D2RTJR | 22.57 kr |  | 296-25430-1-ND
U2 | 1 | PRTR5V0U2X_C2827688 | 8.10 kr |  | 1727-PRTR5V0U2X,215CT-ND
U3 | 1 | NPM1300-QEAA-R7 | 28.45 kr |  | 4823-NPM1300-QEAA-R7CT-ND
U4 | 1 | L86-M33 | 127.31 kr |  | 13278361 | Quectel L86-M33 - lagerfort hos DigiKey
U5 | 1 | RV-3028-C7 | 24.59 kr |  | 2195-RV-3028-C732.768KHZ1PPM-TA-QCCT-ND | RV-3028-C7 32.768KHZ 1PPM-TA-QC
U6 | 1 | TPS61023DRLR | 11.77 kr |  | 296-TPS61023DRLRCT-ND
U7 | 1 | LIS3DH | 18.71 kr |  | 497-10613-1-ND | LIS3DHTR
U8 | 1 | 25Q128 | 40.61 kr |  | W25Q128JVSIQCT-ND | Correct part: W25Q128JVSIQ (3.0V). A 1.8V W25Q128FW was fitted by mistake once; do not repeat.
U9 | 1 | 74LVC1G17 | 1.45 kr |  | 296-11933-1-ND | SN74LVC1G17DBVR
U10, U11, U12 | 3 | IRLML6344TRPBF | 4.53 kr |  | IRLML6344TRPBFCT-ND | pris per stk
U14 | 1 | LM3671MFX-3.3/NOPB | 16.98 kr |  | 296-45289-1-ND
U18 | 1 | ATSAMD51J19A-AUT | 64.81 kr |  | ATSAMD51J20A-AUT-ND | Schematic says SAMD51J19A - FITTED PART IS SAMD51J20A (verified via bossac). Order J20A.
X1 | 1 | 32.768 | 25.66 kr |  | SER4071CT-ND | Epson FC-135R 32.7680KA-A3 (= Q13FC1350000500-krystallen under ordrekode)
Display NV3007 428x142 TFT (modul m/ BL pull-down) | 1 |  | 60.00 kr
Batteri 505060 LiPo 3.7V 2000mAh m/PCM | 1 |  | 90.00 kr
PCB (produksjon) | 1 |  | 40.00 kr
Diverse: skruer, kabler, 3D-print (kabinett) | 1 |  | 50.00 kr
TOTAL per klokke (komponenter + display/batteri/PCB/div, eks. mva):
Priser fra digikey.no 2026-08-16, eks. mva. EQUIVALENT = original ikke lagerfort hos DigiKey.

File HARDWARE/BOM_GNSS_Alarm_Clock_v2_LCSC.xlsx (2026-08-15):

GNSS Alarm Clock v2 - Bill of Materials
Generated from HARDWARE/GNSS_Alarm_Clock.kicad_pcb, 2026-08-10. 146 components, 38 unique parts. Resistor value notation normalized (schematic mixes 100KΩ/100k/100kΩ).
Designators | Qty | Value / Part | Price (USD) | MOQ | Line total (USD) | LCSC Partnumber | Notes
C1, C3, C4 | 3 | 22uF | $0.1173 | 1 |  | C296720 | Samsung CL21A226KOQNNNE 22uF 16V X5R (16V slaar spec; 25V-varianten utsolgt)
C2, C5, C26 | 3 | 1uF | $0.0507 | 10 |  | C28323 | Samsung CL21B105KBFNNNE 1uF 50V X7R, MOQ 10
C6, C7, C8, C9, C10, C11, C12, C16, C17, C19, C20, C22, C28, C29 | 14 | 10uF | $0.1007 | 20 |  | C15850 | Samsung CL21A106KAYNNNE 10uF 25V X5R, MOQ 20
C13 | 1 | 4.7uF | $0.0440 | 20 |  | C1779 | Samsung CL21A475KAQNNNE 25V, MOQ 20
C14, C15, C27 | 3 | 100nF | $0.0234 | 20 |  | C49678 | YAGEO CC0805KRX7R9BB104, MOQ 20
C18, C21 | 2 | 220uF | $0.0384 | 20 |  | C970693 | Bulk electrolytic - polymer upgrade candidate. | DMBJ RVT0J221M0605 (elko, kun 220 pa lager). Polymer-alternativ: Panasonic 6SVPC330M = C139569, $0.71/stk, 1040 pa lager
C24, C25 | 2 | 10pF | $0.0183 | 100 |  | C107107 | YAGEO CC0805JRNPO9BN100 NP0, MOQ 100 (~$1.83 min-kjop)
J1 | 1 | USB4110GFA | $1.5708 | 1 |  | C5143397 | EKSAKT GCT USB4110-GF-A; 100+ @ $0.97
J3 | 1 | SWD-Connector_3220-10-0100-00 | $1.5289 | 1 |  | C448647 | EQUIVALENT: Samtec FTSH-105-01-L-DV-K (CNC Tech-originalen ikke lagerfort) - standard ARM 2x5 1.27mm
J4 | 1 | B8B-XH-A | $0.1480 | 5 |  | C157972 | EKSAKT B8B-XH-A(LF)(SN), MOQ 5
J6, J7 | 2 | B2B-PH-K-S | $0.0354 | 20 |  | C131337 | Battery connector (J7) - production cell: 505060 LiPo 3.7V 2000mAh with PCM. | EKSAKT B2B-PH-K-S(LF)(SN), MOQ 20; pris per stk
L1 | 1 | 2.2uH | $0.3131 | 1 |  | C136245 | EKSAKT TDK VLCF4020T-2R2N1R7, 1543 pa lager (DigiKey: restordre!)
L2 | 1 | 1uH | $0.0632 | 1 |  | C340375 | YJYCOIN YNR4020-1R0N 1uH 2.15A - NB 2.0mm hoy vs originalens 1.2mm, sjekk klaring. Eksakt YXMAA0412 = C241325, men kun via szlcsc/JLCPCB
L4 | 1 | 10uH | $0.0834 | 10 |  | C5832376 | cjiang FTC252012S100MBCA 10uH 1008, MOQ 10
LED1, LED2, LED3, LED4, LED5, LED6, LED7, LED8, LED9, LED10, LED11, LED12, LED13, LED14, LED15, LED16, LED17, LED18, LED19, LED20, LED21, LED22, LED23, LED24, LED25, LED26, LED27, LED28, LED29, LED30, LED31, LED32, LED33, LED34 | 34 | OR-PL020W | $0.0200 | 1 |  | C205440 | EKSAKT OR-PL020W lagerfort hos LCSC men UTSOLGT (ingen pris). NB: original er SIDE-EMITTER 3.8x1.2mm - in-stock 'ekvivalenter' i PLCC-2/3528 (topp-emitter) er FEIL pakke. Vent pa restock eller finn side-view-ekvivalent
R1, R8, R9, R10 | 4 | 1MΩ | $0.0078 | 100 |  | C17514 | UNI-ROYAL 0805W8F1004T5E, MOQ 100
R4, R12 | 2 | 100kΩ | $0.0068 | 100 |  | C25803 | UNI-ROYAL 0603WAF1003T5E, MOQ 100
R5 | 1 | 732kΩ | $0.0025 | 100 |  | C23239 | UNI-ROYAL 0603WAF7323T5E, MOQ 100
R6, R7 | 2 | 4.7kΩ | $0.0082 | 100 |  | C17673 | UNI-ROYAL 0805W8F4701T5E, MOQ 100
R13, R67 | 2 | 100kΩ | $0.0019 | 100 |  | C17407 | UNI-ROYAL 0805W8F1003T5E, MOQ 100
R15, R54, R56 | 3 | 470Ω | $0.0073 | 100 |  | C17710 | UNI-ROYAL 0805W8F4700T5E, MOQ 100
R16, R18, R55, R57, R58, R63, R68 | 7 | 10kΩ | $0.0056 | 100 |  | C17414 | R68: v3 change queued - amp ~SD pull-up should become pull-DOWN. | UNI-ROYAL 0805W8F1002T5E, MOQ 100
R20, R21, R22, R23, R24, R25, R26, R27, R28, R29, R30, R31, R32, R33, R34, R35, R36, R37, R38, R39, R40, R41, R42, R43, R44, R45, R46, R47, R48, R49, R50, R51, R52, R53 | 34 | 80Ω | $0.0025 | 10 |  | C17833 | UNI-ROYAL 0805W8F806JT5E 80.6R E96 (eksakt 80R finnes ikke), MOQ 10, 2320 pa lager
R66 | 1 | 1kΩ | $0.0083 | 100 |  | C17513 | UNI-ROYAL 0805W8F1001T5E, MOQ 100
SW1, SW2, SW3, SW4, SW5 | 5 | TS-1187A-B-A-B | $0.0185 | 20 |  | C318884 | EKSAKT TS-1187A-B-A-B (XKB), MOQ 20 - 943k pa lager
U1 | 1 | TPA2016D2RTJR | $3.5323 | 1 |  | C412823
U2 | 1 | PRTR5V0U2X_C2827688 | $1.4751 | 1 |  | C12333
U3 | 1 | NPM1300-QEAA-R7 | $1.7482 | 1 |  | C7501206 | UTSOLGT hos LCSC - kjop hos DigiKey (28,45 kr)
U4 | 1 | L86-M33 | $8.1300 | 1 |  | C909689 | EKSAKT L86-M33 men UTSOLGT - kjop hos DigiKey (127,31 kr); 30+ @ $5.93 ved restock
U5 | 1 | RV-3028-C7 | $2.2200 | 1 |  | C3019759 | UTSOLGT (begge TA-QC/TA-QA-varianter) - kjop hos DigiKey (24,59 kr)
U6 | 1 | TPS61023DRLR | $0.2670 | 5 |  | C919459 | MOQ 5
U7 | 1 | LIS3DH | $1.9400 | 1 |  | C15134 | LIS3DHTR
U8 | 1 | 25Q128 | $2.7537 | 1 |  | C97521 | Correct part: W25Q128JVSIQ (3.0V) - do not order the 1.8V FW variant. | W25Q128JVSIQ 2.7-3.6V bekreftet, 30k pa lager
U9 | 1 | 74LVC1G17 | $0.1897 | 5 |  | C7836 | SN74LVC1G17DBVR (ekte TI), MOQ 5
U10, U11, U12 | 3 | IRLML6344TRPBF | $0.1977 | 5 |  | C53550 | MOQ 5; pris per stk
U14 | 1 | LM3671MFX-3.3/NOPB | $1.0509 | 1 |  | C477918
U18 | 1 | ATSAMD51J19A-AUT | $8.8200 | 1 |  | C619371 | Fitted/correct part is SAMD51J20A (schematic symbol says J19A). | EKSAKT ATSAMD51J20A-AUT - men kun 29 pa lager
X1 | 1 | 32.768 | $0.1739 | 5 |  | C32346 | Epson Q13FC1350000400 (FC-135 12.5pF standardvariant), MOQ 5
Sum reell bestilling for 1 kort (max(antall, MOQ) x stykkpris; LED1 utsolgt/ikke medregnet): |  |  |  |  |  | NOK: gang med ~9,44
Priser fra lcsc.com 2026-08-16 (USD, laveste pristrinn - flere har MOQ 10-100, se notater). UTSOLGT hos LCSC: nPM1300, RV-3028, L86, OR-PL020W - kjopes hos DigiKey/ventes pa.
— I NOK (kurs i celle D under) —
USD/NOK-kurs (2026-08-16): |  |  | 9.44
Komponenter fra LCSC (omregnet)
Display NV3007 428x142 TFT (modul m/ BL pull-down) | 1 |  | 60.00 kr
Batteri 505060 LiPo 3.7V 2000mAh m/PCM | 1 |  | 90.00 kr
PCB (produksjon) | 1 |  | 40.00 kr
Diverse: skruer, kabler, 3D-print (kabinett) | 1 |  | 50.00 kr
TOTAL per klokke (eks. mva, eks. frakt):

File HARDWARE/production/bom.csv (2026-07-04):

Designator | Footprint | Quantity | Value | LCSC Part #
_5, _4, _3, _2, |  | 5
C10, C11, C16, C17, C19, C20, C21, C28, C6, C7, C8, C9 | 0805 | 12 | 10uF
C12, C13, C14, C15 | CP_Radial_D6.3mm_P2.50mm | 4 | C_Polarized
C18 | CP_Elec_6.3x5.7 | 1 | 220uF
C2 | 0805 | 1 | 1uF
C22 | 0805 | 1 | 2.2uF
C23 | 0805 | 1 | 4.7uF
C24, C25 | 0805 | 2 | 10pF | C32949
C26, C30 | 0805 | 2 | 1uF | C52923
C27 | 0805 | 1 | 100nF
C29 | 0805 | 1 | 10μF | C52923
D3 | D_SMA | 1 | US1M
J1 | USB4110-GF-A | 1 | USB4110GFA
J2 | PinHeader_2x05_P1.27mm_Vertical | 1 | Conn_ARM_JTAG_SWD_10
J3 | B7B-XH-A | 1 | B7B-XH-A
J5, J6 | B2B-PH-K-S | 2 | B2B-PH-K-S
L1 | VLCF4020T-2R2N1R7 | 1 | 2.2uH
L4 | 1008 | 1 | 10uH
LED1, LED10, LED11, LED12, LED13, LED14, LED15, LED16, LED17, LED18, LED19, LED2, LED20, LED21, LED22, LED23, LED24, LED25, LED26, LED27, LED28, LED29, LED3, LED30, LED31, LED32, LED33, LED34, LED4, LED5, LED6, LED7, LED8, LED9 | OR-PL020W | 34 | OR-PL020W | C205440
R1, R10, R11, R8, R9 | 0805 | 5 | 1M
R13 | 0805 | 1 | 100k
R14 | 0805 | 1 | 33kΩ
R15, R54, R56, R59 | 0805 | 4 | 470Ω | C25117
R18, R55, R57, R58, R60, R63, R68 | 0805 | 7 | 10kΩ | C25744
R2, R3 | 0805 | 2 | 5100Ω
R20, R21, R22, R23, R24, R25, R26, R27, R28, R29, R30, R31, R32, R33, R34, R35, R36, R37, R38, R39, R40, R41, R42, R43, R44, R45, R46, R47, R48, R49, R50, R51, R52, R53 | 0805 | 34 | 80Ω
R6, R7 | 0805 | 2 | 4.7K
R61 | 0805 | 1 | 1MΩ
R62 | 0805 | 1 | 300kΩ
R64 | 1206 | 1 | 0Ω | C25117
R65 | 0805 | 1 | 10kΩ
R66 | 0805 | 1 | 1kΩ | C11702
R67 | 0805 | 1 | 100KΩ | C25741
RESET, SW1, SW2, SW3, SW4 | TS-1187A-B-A-B | 5 | TS-1187A-B-A-B | C318884
U1 | TPA2016D2 | 1 | TPA2016D2RTJR | TPA2016D2RTJR
U10, U11, U12, U13 | IRLML6344 | 4 | IRLML6344TRPBF | C53550
U14 | LM3671MFX-3.3 | 1 | LM3671MFX-3.3/NOPB
U15 | LTC3226 | 1 | LTC3226EUD-PBF
U18 | ATSAMD51J19_TQFP | 1 | ATSAMD51J19A-AUT
U2 | PRTR5V0U2X | 1 | PRTR5V0U2X_C2827688 | C2827688
U4 | L86-M33 | 1 | L86-M33
U5 | RV-3028-C7 | 1 | RV-3028-C7 | C3019759
U6 | SOIC-8_3.9x4.9mm_P1.27mm | 1 | 24LC512
U7 | LGA-16_3x3mm_P0.5mm_LayoutBorder3x5y | 1 | LIS3DH | C15134
U8 | SOP-8_3.9x4.9mm_P1.27mm | 1 | MX25L3233FM1
X1 | Q13FC13500005 | 1 | 32.768 | C841881

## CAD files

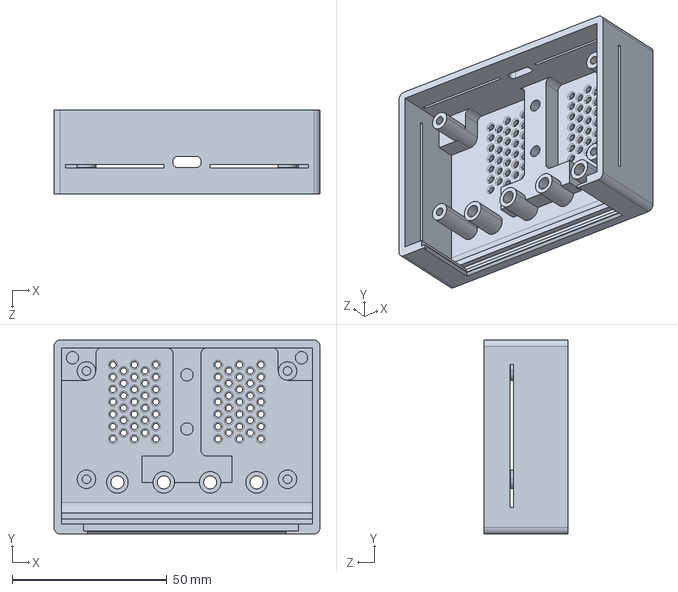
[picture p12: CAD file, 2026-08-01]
HARDWARE/Enclosure/Main_box_main-part.STEP
86.0 x 62.7 x 27.0 mm

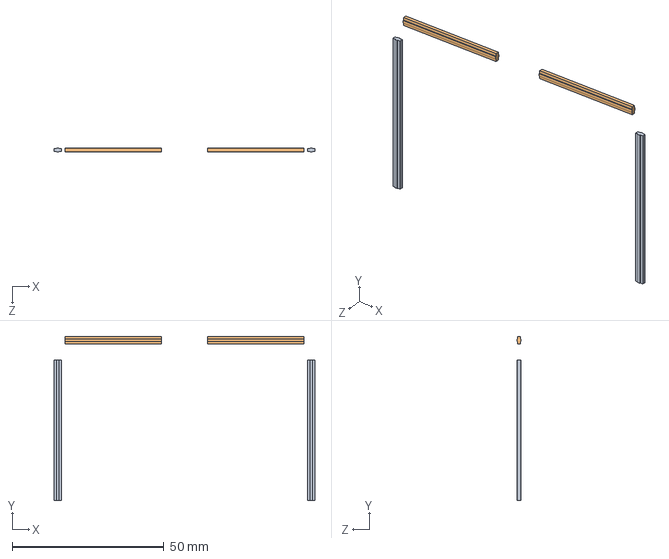
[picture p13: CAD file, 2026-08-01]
HARDWARE/Enclosure/Main_box_lights-part.STEP
86.0 x 54.2 x 1.40 mm

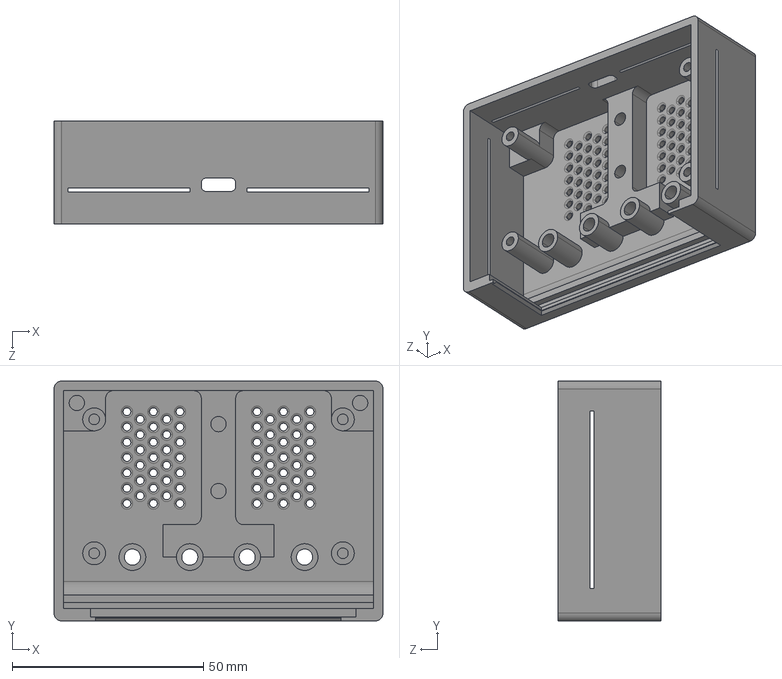
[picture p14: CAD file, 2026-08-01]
HARDWARE/Enclosure/Main_box.STEP
86.0 x 62.7 x 27.0 mm

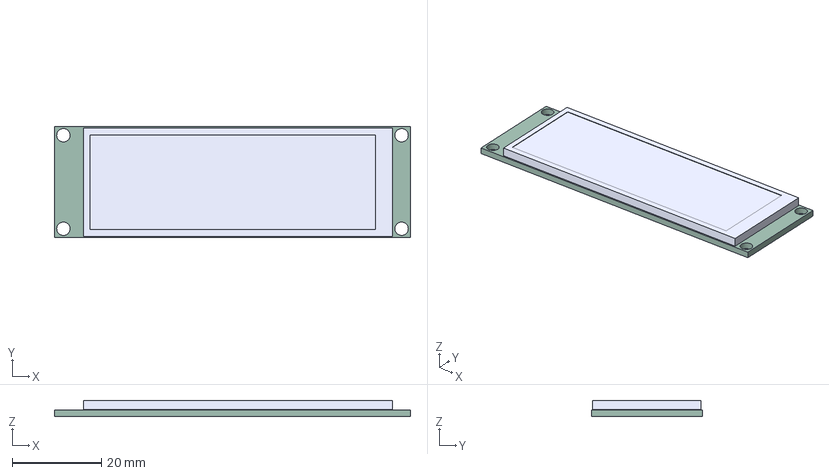
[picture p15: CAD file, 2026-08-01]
HARDWARE/Enclosure/PCB_Display.step
80.0 x 25.0 x 3.70 mm
disp_panel
Display_kicadpro_PCB

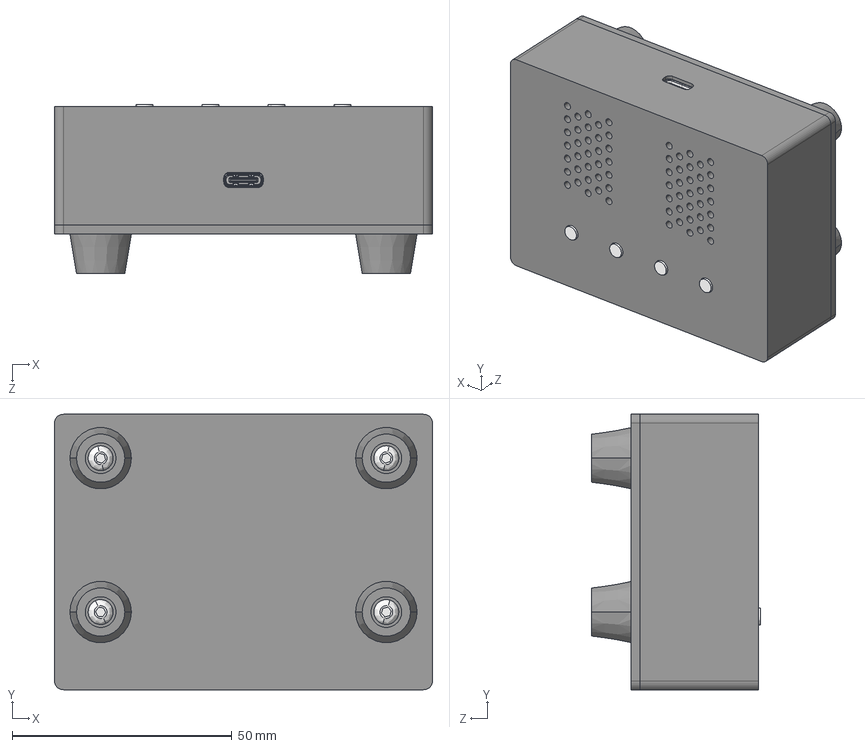
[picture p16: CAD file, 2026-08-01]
HARDWARE/Enclosure/Assem.STEP
86.0 x 62.7 x 38.5 mm
Main_Box
Button x 4
C_0805_2012Metric-0.step x 30
R_0805_2012Metric-1.step x 56
CP_Elec_63x57.step x 2
SW-SMD_4P-L5.2-W5.2-H1.5-LS6.4-P3.70.step x 5
L86-M33-2.step
VLCF4020T-1R8N1R9.step
LED-SMD_L3.8-W1.2-H0.6-OR-PL020W.step x 34
LGA_16_3x3mm_P05mm_LayoutBorder3x5y.step
USB4110-GF-A_revB(1) MF.step
BxB-XH-A_08.step
part.step
COMPOUND.step x 2
CRYSTAL-SMD_L3.2-W1.5-1.step
R_0603_1608Metric-3.step x 3
part-4.step x 3
3220-xx-0100-00 body_10.step
Pin^3220-xx-0100-00.step x 10
RV-3028-C7-5.step
part-6.step
SOIC-8_5.3x5.3mm_P1.27mm-7.step
FRAME-DRL0006A.step
BODY-SOT.step
IND-SMD_L4.5-W4.1-H2.0_YXMAA04X.step
BODY-SOT-8.step
LEAD-SOT.step x 5
LEAD-DUMMY.step
SOT-143-4_L2.9-W1.3-P1.92-LS2.4-BL.step
SOT-23-5-9.step
L_1008_2520Metric-10.step
RTJ20.step
GNSS_Alarm_Clock_PCB.step
disp_panel.step
SOT-23-1.step
SxB-PH-SM4-TB white_8.step
Display_kicadpro_PCB.step
speaker x 2
pcb_bat_plate
505060_battery
speaker_fastener
Lid
hex_socket_button_head_M3x16.step x 4
Rubber_feet x 4

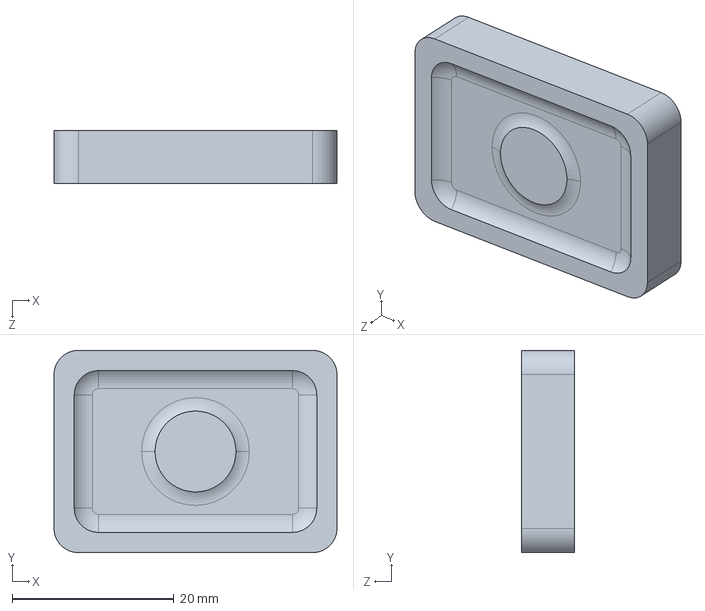
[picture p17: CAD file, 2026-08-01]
HARDWARE/Enclosure/speaker.STEP
35.0 x 25.0 x 6.50 mm

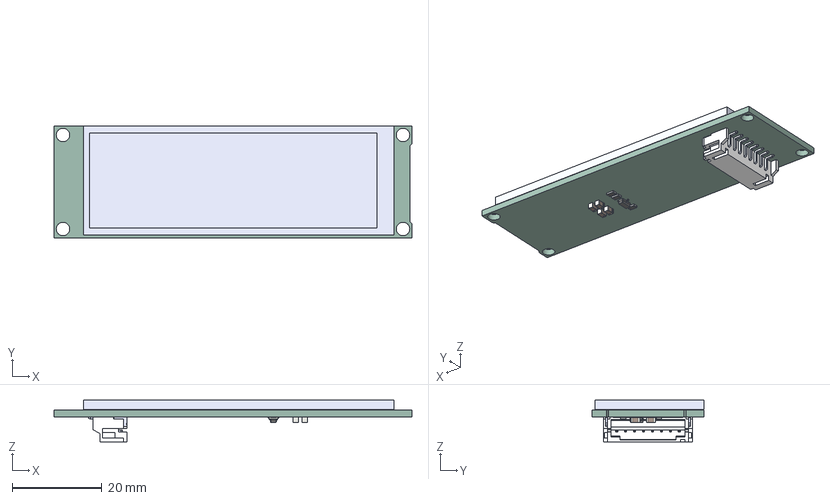
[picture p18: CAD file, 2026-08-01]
HARDWARE/Enclosure/PCB_Display_panel-shifted.step
80.0 x 25.0 x 9.28 mm
disp_panel
C_0805_2012Metric x 4
SOT-23
R_0805_2012Metric x 3
SxB-PH-SM4-TB white_8
Display_kicadpro_PCB

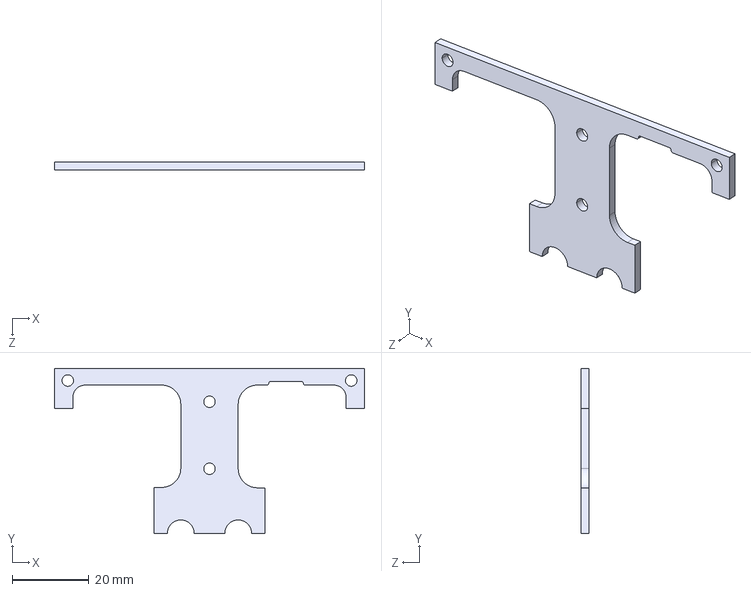
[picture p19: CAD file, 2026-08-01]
HARDWARE/Enclosure/speaker_fastener.STEP
81.0 x 43.2 x 2.00 mm

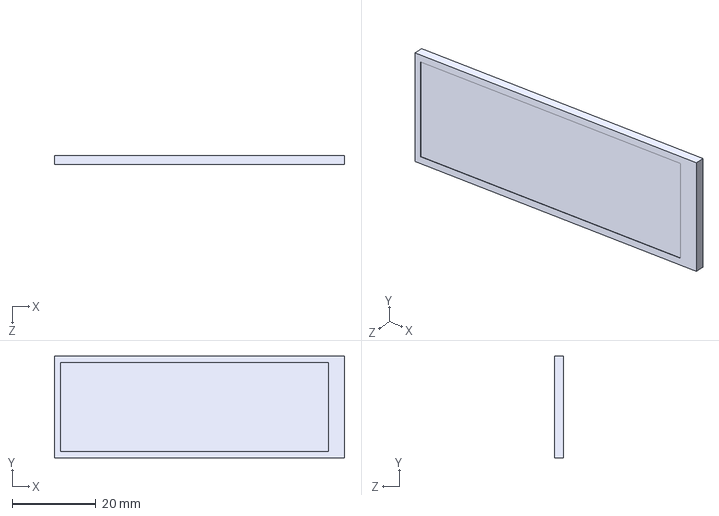
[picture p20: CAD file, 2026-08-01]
HARDWARE/Enclosure/disp_panel.STEP
69.4 x 24.4 x 2.10 mm

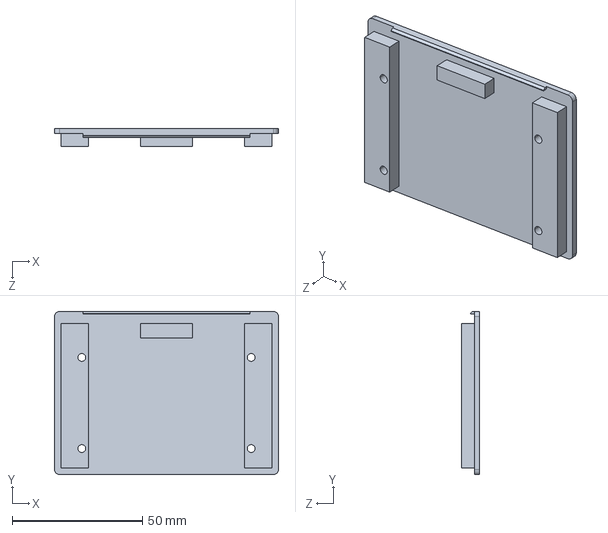
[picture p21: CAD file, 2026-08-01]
HARDWARE/Enclosure/Lid.STEP
86.0 x 62.7 x 7.00 mm

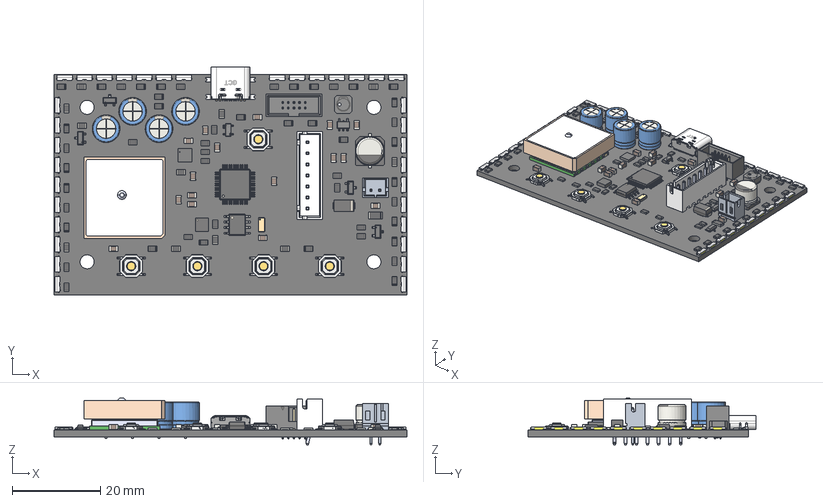
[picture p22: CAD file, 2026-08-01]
HARDWARE/Enclosure/PCB.step
80.0 x 51.6 x 10.6 mm
OR-PL020W x 34
C_0805_2012Metric x 16
R_0805_2012Metric x 60
PCB 1.13
CP_Radial_D6.3mm_P2.50mm x 4
TS-1187A-B-A-B x 5
BODY-SOT
LEAD-SOT x 5
LEAD-DUMMY
IRLML6344 x 4
SOIC-8_3.9x4.9mm_P1.27mm
3220-xx-0100-00 body_10
Pin^3220-xx-0100-00 x 10
R_1206_3216Metric
LGA-16_3x3mm_P0.5mm_LayoutBorder3x5y
D_SMA
USB4110-GF-A_revB(1) MF
L86-M33
RV-3028-C7
VLCF4020T-2R2N1R7
CP_Elec_6.3x5.7
PRTR5V0U2X
LTC3226
BxB-XH-A_07
TQFP-48_7x7mm_P0.5mm
GPS-Klokke_PCB

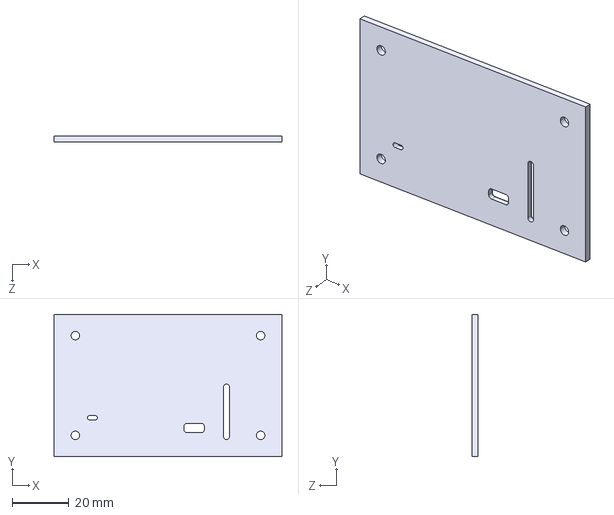
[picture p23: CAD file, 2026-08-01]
HARDWARE/Enclosure/pcb_bat_plate.STEP
80.0 x 50.0 x 2.00 mm

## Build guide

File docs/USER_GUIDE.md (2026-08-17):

# GNSS Alarm Clock — User Guide

How to operate the clock. (Building/flashing lives in the
[README](../README.md); design decisions in [docs/adr/](adr/).)

## The four buttons

Above the display, left to right:

| | B1 | B2 | B3 | B4 |
|---|---|---|---|---|
| Normal | **Back** / open menu | Prev / up | Next / down | **OK** / open menu |
| Editing a value | Cancel | − step | + step | Commit |
| Long-press | **Home** (clock) from anywhere | Coarse − | Coarse + | — |
| While ringing | any short press = **snooze**, any long press = **stop** | | | |
| While snoozed | long press = stop; short presses navigate normally | | | |
| Game mode | menu | gamepad button 1 | button 2 | button 3 |

**Editing:** focus a value (roller/dropdown/slider/day-matrix) with B2/B3,
press B4 to enter edit mode, adjust with B2/B3 (long-press jumps: ×5 in
dropdowns, ×10 in rollers, ±50 on sliders), B4 commits, B1 cancels.
Dropdown lists open as a full-screen overlay with the current choice centered.

## The clock screen

- Big **HH:MM** (or the active mode's figure). Top-left: satellite count.
  Top-right: USB (host owns the TUNES drive), a charge bolt while charging,
  a **drawn battery gauge** (white frame, fill width = charge level, colored
  red under 20% / orange under 50% / green above — no percent number; the
  estimate is approximate by nature, especially while charging), bell (an
  alarm is enabled). v1 boards show a full green battery when the supercaps
  are ready. Bottom: date and next alarm.
- **Low battery** (v2): under 3.40 V on battery (never during an alarm, never on a charger) the clock powers itself off; woken below 3.45 V without a charger it shows **LOW BATTERY** for 4 s and sleeps again. The RTC keeps time throughout.
- Display dims after the configured timeout — any button **or a small
  shake/tap** wakes it (LIS3DH motion).
- **Starry night** (Disp & sound): between **22:00 and 06:00** a couple dozen
  faintly twinkling stars appear behind the digits. Clock mode only.

## Menu

`B1` (or `B4`) on the clock screen opens it:

| Item | What it does |
|---|---|
| Alarm 1 / Alarm 2 | Enable switch, time rollers, weekday matrix (S M T W T F S — **no days selected = every day**), tune dropdown, **Ramp** (per-alarm gentle wake: Off/15/30/60 s), **Random** (the alarm fires at a random offset of ±1/±5/±9 min around the set time — a new roll every occurrence, and the display still shows the set time so you can't cheat), **Lights** (the LED show while ringing; off = sound-only alarm), Test, Save. *Back does not save.* |
| Time & zone | **Auto TZ (GNSS)** on/off; manual **Zone** = the full GMT ladder (GMT−12…+14 incl. half/quarter hours, fixed offsets, no DST); 24 h switch; **Sync now**. |
| Disp & sound | **Volume** (0–10, live while a tune plays), brightness slider (live), dim-after timeout, dim level, **Starry night** (stars behind the clock 22–06). |
| Tunes | Preview built-in melodies and WAVs from the TUNES drive (press again to stop). Unavailable while the USB host owns the drive. |
| System info | Fix/sats/HDOP, position, speed/altitude, zone + POSIX string, UTC offset/DST, GNSS sync age, RTC status, caps status, **snooze counters**, FW version. Scroll with B2/B3. |
| Battery | (v2 boards) Live power status: USB present, battery voltage + estimated SoC, charge state (trickle/CC/CV/charged — "battery assisting" means the load momentarily exceeds the 500 mA USB budget and the battery covers the difference), PMIC die temperature. Charging targets 400 mA on a 500 mA source and 800 mA on a detected 1.5/3 A USB-C source, to 4.10 V (the PMIC gives charging whatever remains of the budget, and pauses above 80 °C die temp until it cools to 70 °C). Live battery current (+ = charging, − = discharging) is shown on this screen. |
| Sky view | Live satellite map: left a **polar plot** (center = straight up, outer ring = horizon, N = north; dot color green/yellow/red/grey = signal strength, border white = GPS / cyan = GLONASS), right **SNR bars** for the strongest 12 with PRN numbers (65–96 = GLONASS). Updates every ~5 s — walk the clock around to find the best indoor reception spot. Works without a fix. |
| Lights | Manual on/off switch per LED section (Left 10 / Bottom 14 / Right 10). A power-measurement tool: flip a section, hop to Battery and read the current. State persists while navigating; an alarm's light show overrides it. |
| Tap snooze | Toggle double-tap-to-snooze. |
| Mode | Cycles the main screen: **Alarm clock → Speedometer → Altimeter → Game mode**. |
| Shutdown | (v2, battery only) Confirm with OK → the PMIC cuts the battery (<500 nA); the RTC keeps time. **B1 or a USB plug wakes it.** On USB power it asks you to unplug instead. The clock also does this by itself when the battery runs down to 3.40 V (never while an alarm rings/snoozes) — announced by a short high chirp and a light sweep right before it goes dark, so you notice a forgotten charger. Woken too early without a charger it shows LOW BATTERY and turns back off — plug in USB and it boots normally. |
| Back | To the clock. |

## Alarms

- On trigger: LED chase + the chosen tune (WAV, else built-in melody) —
  fading in over the alarm's own **Ramp** setting on the first ring (snooze
  re-rings and buzzer escalation play at full volume immediately). The light
  show is per-alarm: **Lights off** in the alarm editor gives a sound-only
  alarm. Tunes play at comparable loudness regardless of how the WAV was
  mastered (AGC).
  After the configured minutes unacknowledged, the power buzzer joins in.
  Auto-silence after 30 min; the alarm re-arms for its next day.
- **Snooze**: short-press any button, or **double-tap the clock body**
  (if Tap snooze is on; taps are ignored the first 2 s of each ring).
  Default 9 minutes, then it re-rings.
- **Stop**: long-press any button (also while snoozed).
- The **snooze shame counter** counts every snooze — this week and all time —
  shown on the ringing screen ("snooze (3x this week!)") and in System info.

## Modes

- **Speedometer / Altimeter**: the big figure shows GNSS ground speed (km/h)
  or altitude (m). `---` until there is a fix. Alarms still work.
- **Game mode**: the clock is a **USB gamepad** ("K. Haaland GNSS Alarm
  Clock"): tilt = stick X/Y (~20° for full deflection), B2–B4 = buttons 1–3,
  B1 = menu. Test on Linux with `jstest-gtk`. Alarms still work.

## Tunes (WAV upload)

Plug into a computer — the **TUNES** drive appears. Drop `.wav` files in the
root: PCM, 8- or 16-bit, mono or stereo, 8–48 kHz, filename ≤ 31 chars.
Select the tune in the alarm editor. If a chosen file is later deleted, the
alarm falls back to its built-in melody.

**Converting MP3s**: `python3 tools/tune_converter.py` (Linux/Windows,
needs ffmpeg on PATH) — opens a small GUI: load any audio file, drag across
the waveform to cut out the section you want, preview it, and it writes a
clock-ready WAV (16-bit mono, rate of your choice, peak-normalized,
filename-length guarded).

Playback high-passes WAVs at **200 Hz**: the small speaker can't reproduce
deep bass anyway — it only burns battery current (below the driver's
resonance the impedance is at its minimum while the cone barely moves), so
sub-bass is traded for louder, cleaner output in the audible band. Pick or
master alarm tunes for mid/high energy; sub-heavy tracks lose nothing you
would have heard.

## Time & timezone

Time comes from GNSS automatically (the RV-3028 RTC keeps it through power
loss). The timezone — including DST — is derived **offline** from your
position and remembered, so the clock is right indoors and after reboots.
If you ever want a fixed offset instead, switch Auto TZ off and pick from
the GMT ladder.

## Settings persistence

Everything you configure (alarms, zone, brightness, mode, counters) is
stored in the RTC's EEPROM and survives power loss **and firmware updates**.

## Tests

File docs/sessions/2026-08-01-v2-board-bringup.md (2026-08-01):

# Session log: v2 board bring-up (2026-07-22 → 2026-08-01)

Human-readable summary of the bench session that brought the v2 board from
freshly soldered to fully operational. The complete raw log (every command,
measurement and wrong turn) is in `2026-07-13_2026-08-01-session-raw.jsonl.gz`.

## Starting point

Freshly hand-soldered v2 board: SMD only (THT display/SWD held back until
the LEDs were proven), no battery. The same session window also produced
the display/audio DMA work (ADR-0012/0013), Sky view, starry night and the
Tunes-freeze fix — this summary covers the hardware bring-up arc.

## The bring-up, in order of discovery

1. **Board enumerated immediately** — bootloader + USB + MCU good.
2. **Bottom LED section brownout-looped the board.** Root cause: the
   nPM1300 powers up with a 100 mA VBUS limit until the host raises it.
   Wrote the `ledtest` diag env (I2C scan + serial-armed LED cycling) and
   the nPM1300 unlock (`VBUSINILIM0=5` + `TASKUPDATEILIMSW`). All three
   sections passed with no battery fitted. → ADR-0014, `PmicNPM1300` module.
3. **I2C census:** RTC (0x52) ✅, TPA2016 (0x58) ✅, nPM1300 (0x6B) ✅ —
   and LIS3DH silent. After reflow of U7 it answered at **0x19** despite
   the design strapping SA0 low (R18): the strap isn't reaching the pin
   (cosmetic — FW now probes 0x18 and 0x19, WHO_AM_I-verified).
4. **Battery arrived (3000 mAh interim, 2000 mAh on order).** Charger
   configured: 200 mA, terminate 4.10 V (user's longevity choice), NTC
   type 10k (board has a fixed resistor — no thermistor in the pack).
   Battery/PMIC menu screen added.
5. **USB unplug killed the board** despite the battery → the battery
   holder was at fault; replaced by the user. Power path then verified:
   seamless VBUS ↔ battery switchover.
6. **GNSS silent (0 bytes).** The `ledtest` reset-pulse aliveness test
   (a healthy L86 answers $PMTK011 within ~1 s of reset even with no
   antenna) proved it electrically dead. Multimeter: RESET_N read 2.8 V
   (backup domain alive) while FORCE_ON read 0 V (main domain dead) →
   cold VCC joint on U4. Reflow → **13 satellites indoors.**
7. **Tunes screen froze the clock.** Two independent finds: LVGL pool
   exhaustion (64 K → 80 K; same failure signature as the earlier Sky-view
   incident) and, via a raw JEDEC probe (`EF 60 18`), that U8 is a
   **W25Q128FW — the 1.8 V variant** on a 3.3 V rail. Storage stays
   gracefully disabled until a W25Q128JVSIQ (3 V) is fitted; the BOM's
   "25Q128" listing hid the voltage suffix.
8. **The MCU is actually a SAMD51J20A** (`bossac -i`: ATSAMD51x20) — the
   schematic symbol says J19A. Switched default build to `metro_m4_j20`:
   flash 84.8 → 42.4 %, RAM 80.2 → 60.2 %. → ADR-0015.
9. **USB flashing degraded all day** (aborted write at 56 % → an app that
   enumerated but was half-flash garbage — "no satellites" red herring;
   failing 1200-baud touches). Switched to **SWD via Atmel-ICE** (openocd,
   `.bin` @ 0x4000 — never the `.elf`): fast and deterministic. Quirk:
   openocd's double reset parks the UF2 bootloader; one extra single reset
   enters the app.
10. **Battery-less boot bootlooped with a ghost image.** Long diagnosis
    (panel GRAM survives shallow brownouts, so the "image" was the previous
    boot's frame) ended with the user's find: the current display module
    straps **BL with a pull-up**, so a floating PA19 burns the backlight at
    full power through the whole bootloader phase — inside the 100 mA
    window. Tying BL to GND let it boot; the replacement display has a
    pull-down. FW now clamps BL/L86/amp as its first instructions and
    soft-starts the backlight; the bootloader-phase window remains until
    the custom bootloader lands.
11. **GNSS module end-of-life:** after all fixes the veteran L86 (4-5
    prototype solder cycles, spec allows 2-3) only produces NMEA when
    heated. Replacement ordered; the clock runs fine off the battery-backed
    RTC meanwhile.

## Where that leaves the project

Fully working v2 board pending three parts in the mail: L86-M33 module,
W25Q128JVSIQ flash, pull-down display. Open firmware items: custom
uf2-samdx1 bootloader (pid.codes identity + early ILIM write), v2
escalation stage (no buzzer in hardware), low-battery policy, finer
timezone polygons (flash headroom now allows it).

## Lessons collected

- Suffixes are the datasheet: W25Q128**FW** (1.8 V) vs **JV** (3 V);
  J19A symbol vs J20A chip. Verify silicon, not schematics.
- A PMIC's power-up defaults (100 mA, charger off) shape the whole boot
  story — and reset on every replug.
- A half-flashed app can enumerate and look alive; SWD verify-on-write
  beats USB bootloader flashing for bench work.
- Panel GRAM survives brownouts: a "working display" proves nothing about
  boot progress.
- Modules have reflow-cycle budgets; veterans of many prototypes fail in
  creative, heat-dependent ways.

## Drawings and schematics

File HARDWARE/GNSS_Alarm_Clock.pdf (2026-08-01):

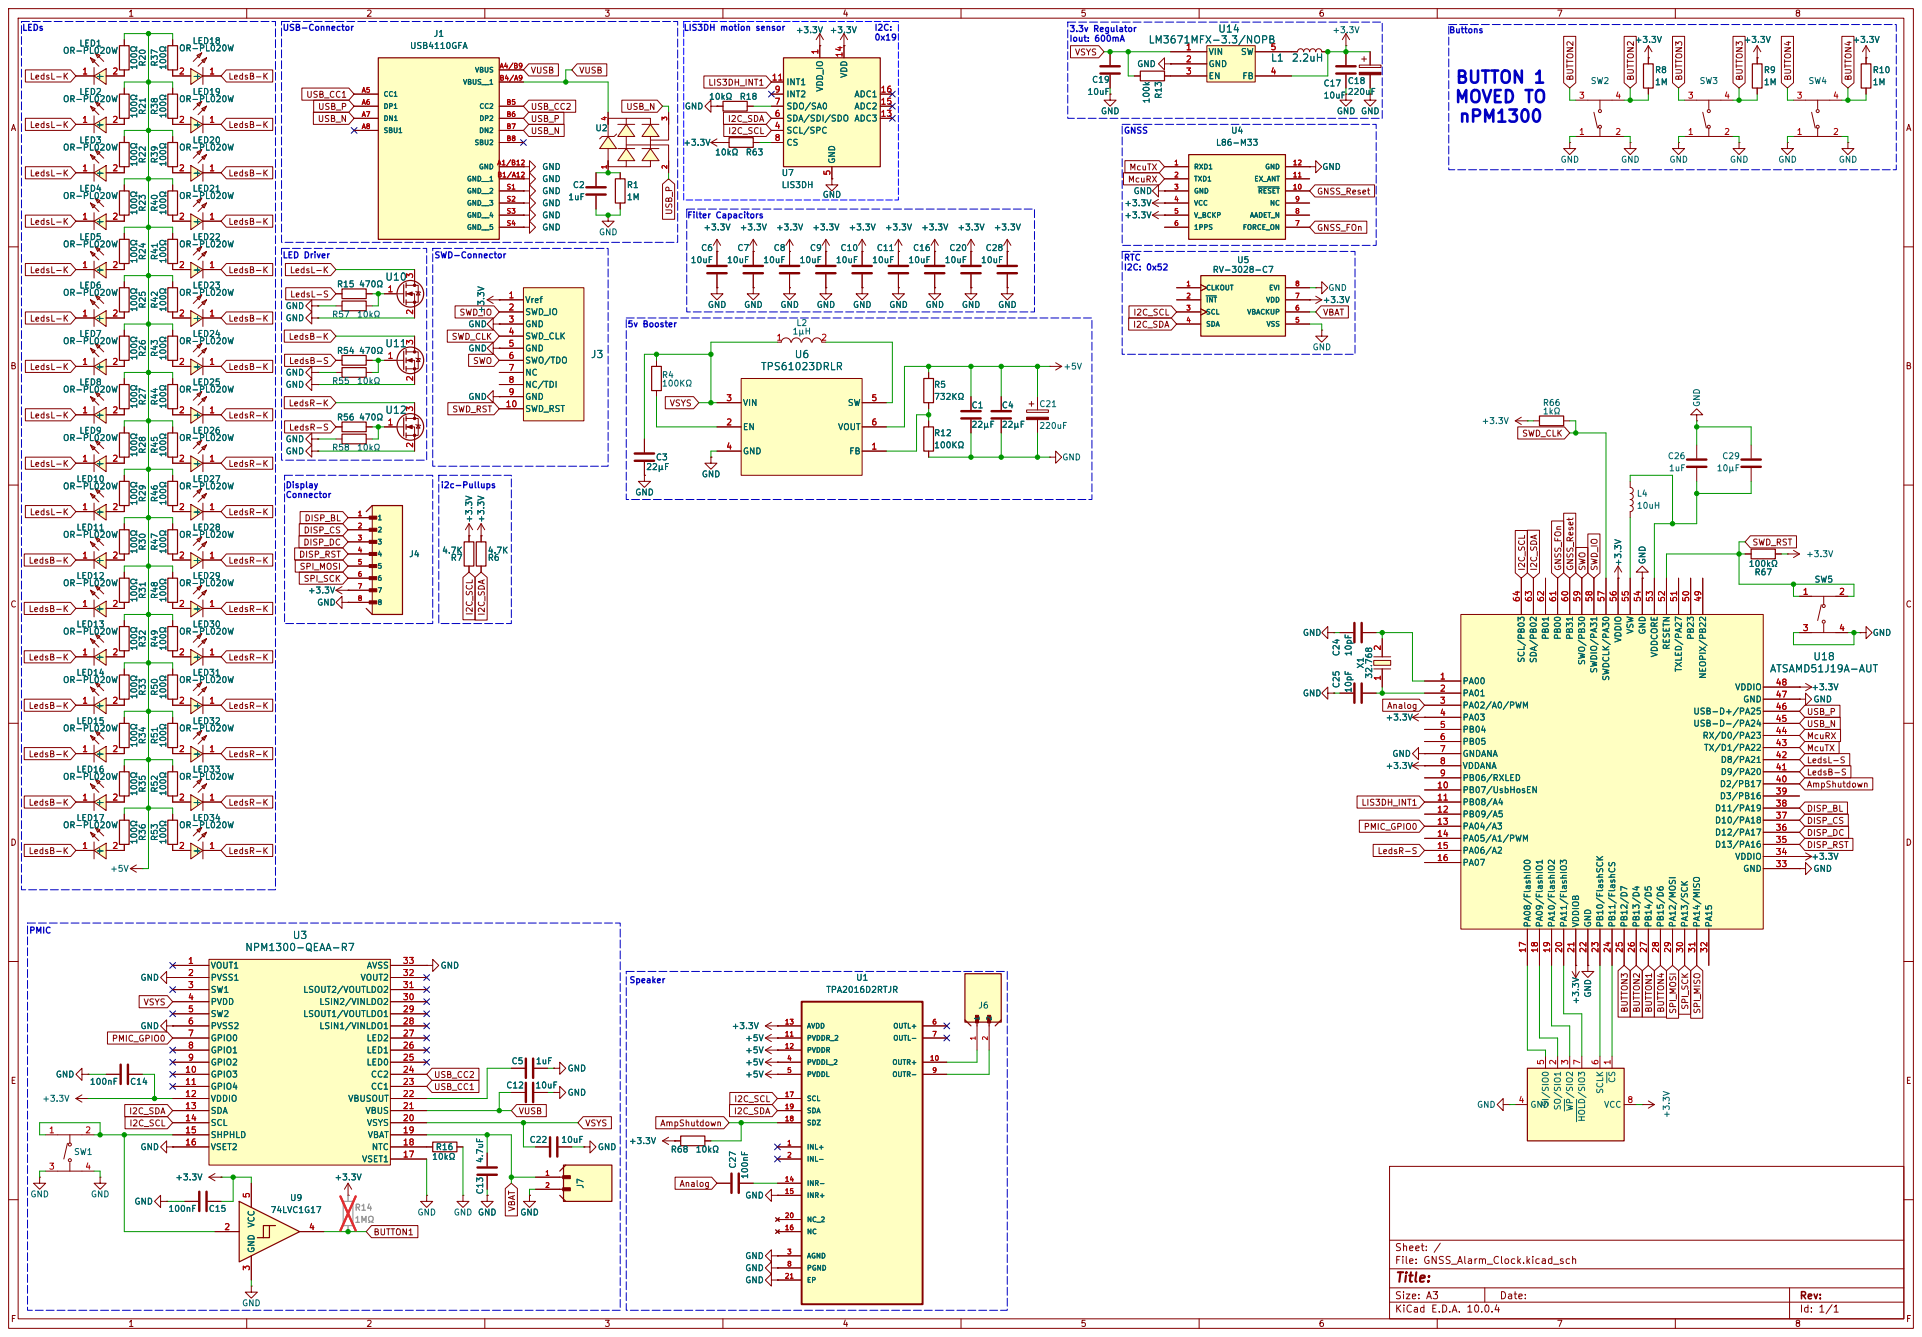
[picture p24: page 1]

10uF | GND +3.3V GND | 10uFGND +3.3V +3.3V GND | GND +3.3V +3.3V GND | GND

L2 1µH | | SWD_RST LedsB-K

46 NEOPIX/PB22 49 TXLED/PA27 51 SWDCLK/PA30 57 SWDIO/PA31 58 SWO/PB30 59 SDA/PB02 63 SCL/PB03 64

48 PB23 50 RESETN 52 VDDCORE 53 GND 54 VSW 55 VDDIO 56 PB31 60 PB00 61 PB01 62

Size: A3 | Rev: | F Date:
KiCad E.D.A. 10.0.4 | Id: 1/1

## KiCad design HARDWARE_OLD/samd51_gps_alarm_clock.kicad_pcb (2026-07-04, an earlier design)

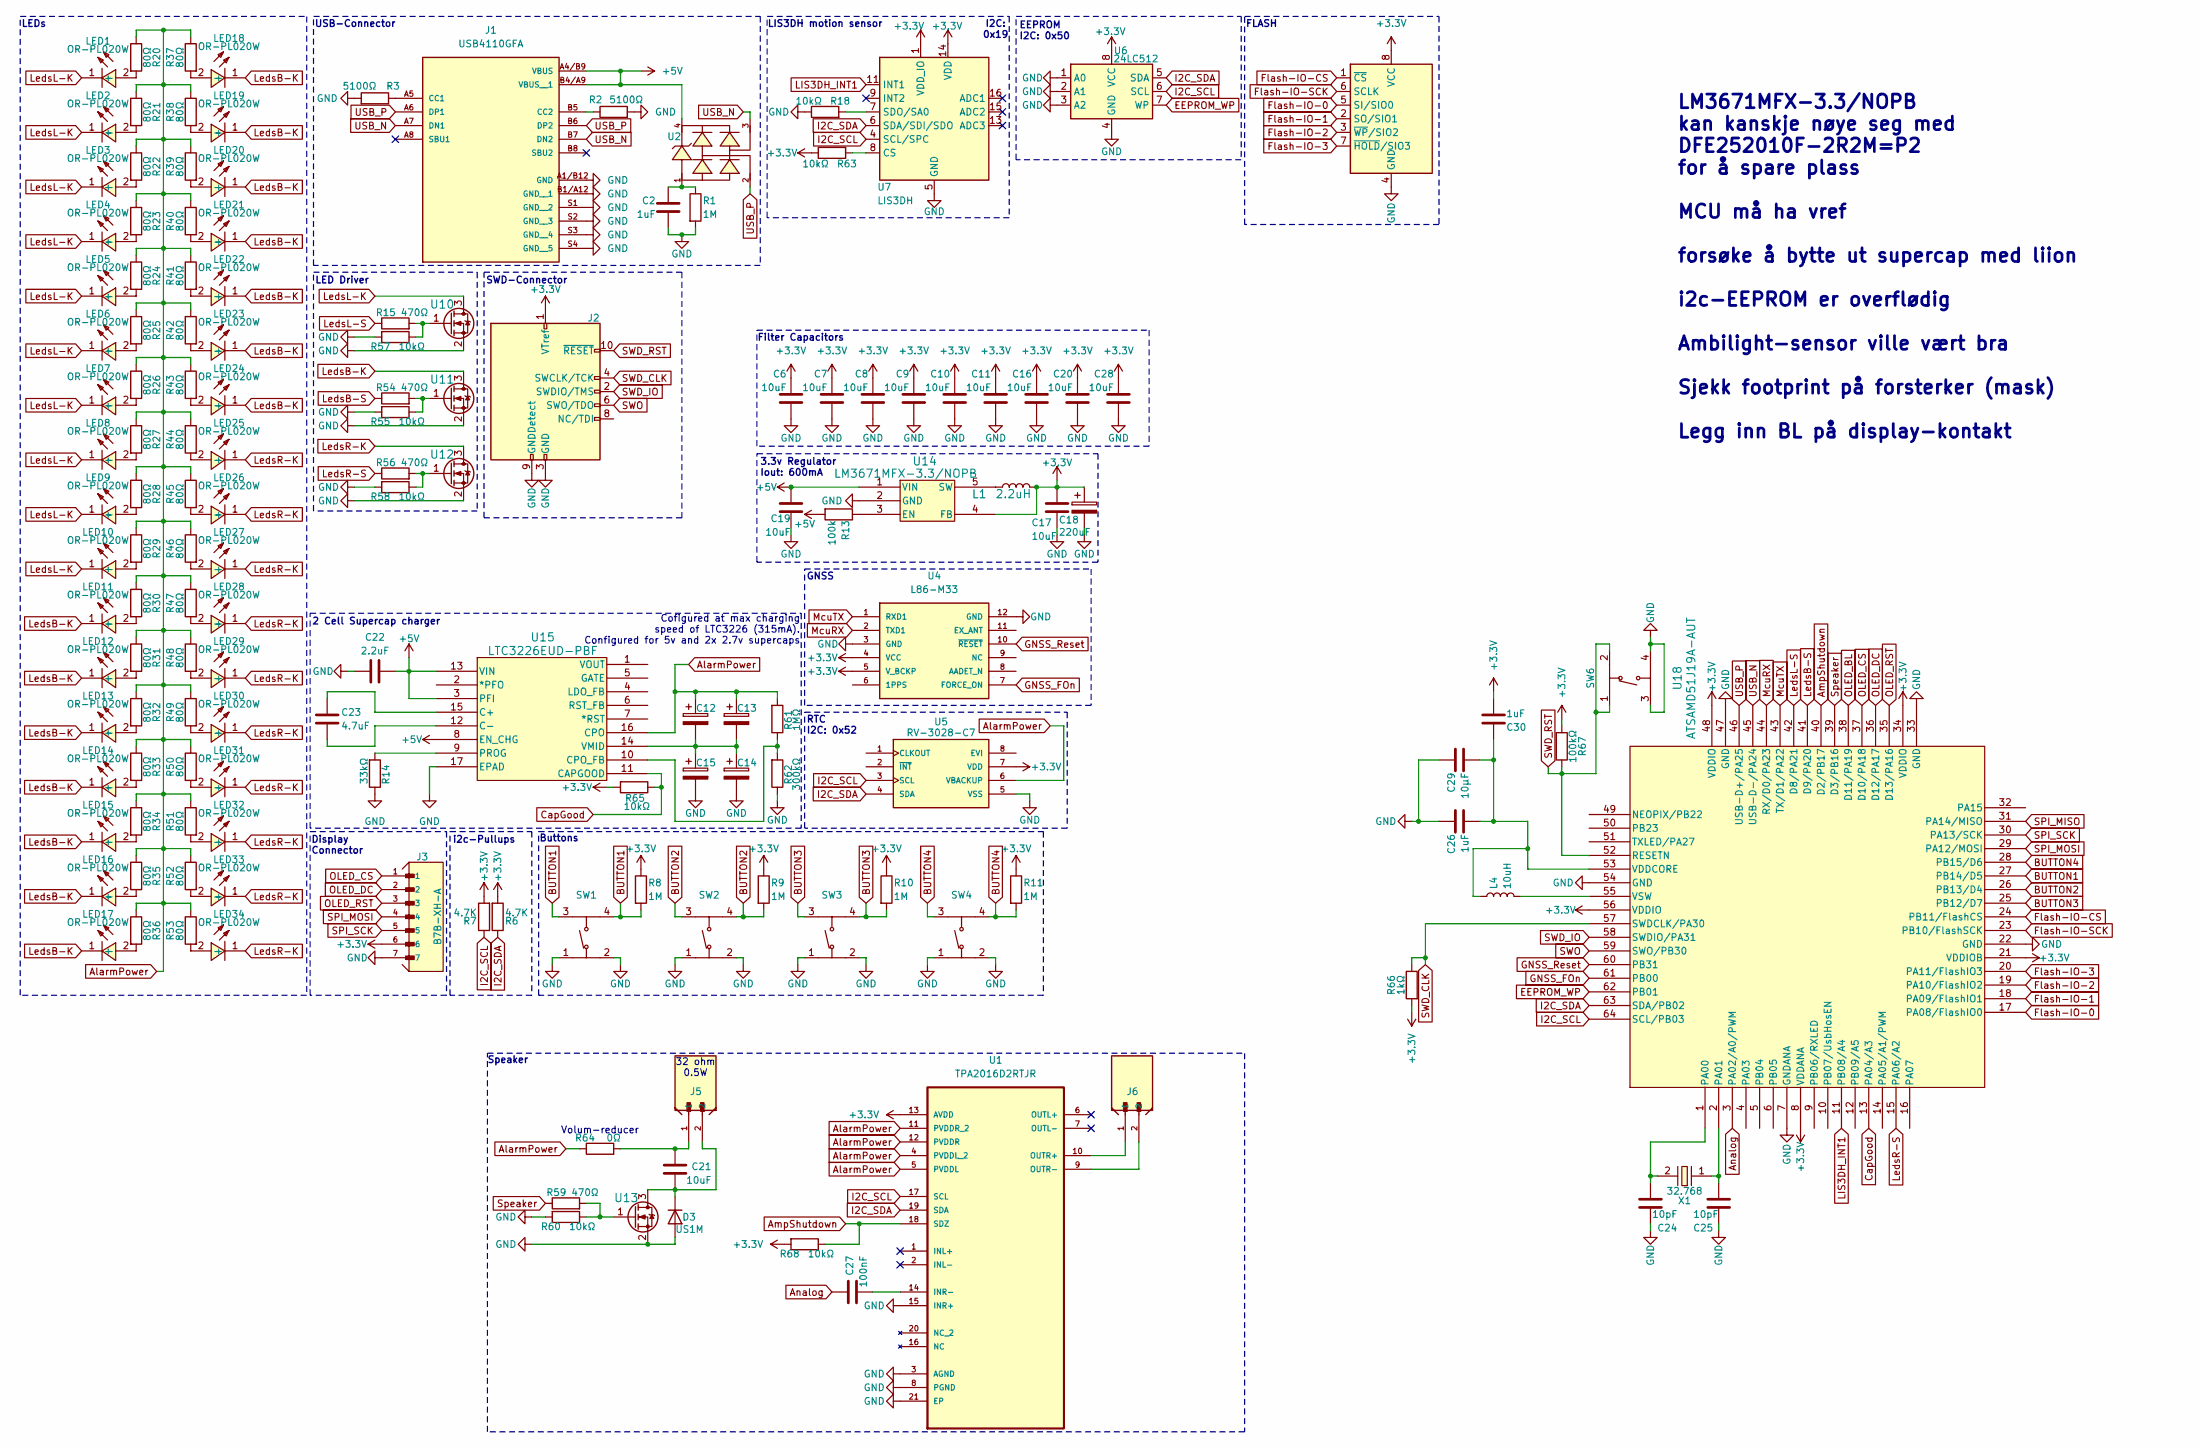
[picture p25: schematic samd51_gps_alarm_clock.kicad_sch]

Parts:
C2: 1uF; C_0805_2012Metric
C6, C7, C8, C9, C10, C11, C16, C17, C19, C20, C21, C28: 10uF; C_0805_2012Metric
C12, C13, C14, C15: C_Polarized; CP_Radial_D6.3mm_P2.50mm
C18: 220uF; CP_Elec_6.3x5.7
C22: 2.2uF; C_0805_2012Metric
C23: 4.7uF; C_0805_2012Metric
C24, C25: 10pF; C_0805_2012Metric; LCSC Part C32949
C26, C30: 1uF; C_0805_2012Metric; LCSC Part C52923
C27: 100nF; C_0805_2012Metric
C29: 10μF; C_0805_2012Metric; LCSC Part C52923
D3: US1M; D_SMA
J1: USB4110GFA; USB4110-GF-A
J2: Conn_ARM_JTAG_SWD_10; PinHeader_2x05_P1.27mm_Vertical
J3: B7B-XH-A; PARTREV 7/4/21
J5, J6: B2B-PH-K-S
L1: 2.2uH; VLCF4020T-2R2N1R7
L4: 10uH; L_1008_2520Metric
LED1, LED2, LED3, LED4, LED5, LED6, LED7, LED8, LED9, LED10, LED11, LED12, LED13, LED14, LED15, LED16, LED17, LED18, LED19, LED20, LED21, LED22, LED23, LED24, LED25, LED26, LED27, LED28, LED29, LED30, LED31, LED32, LED33, LED34: OR-PL020W; LCSC Part C205440
R1, R8, R9, R10, R11: 1M; R_0805_2012Metric
R2, R3: 5100Ω; R_0805_2012Metric
R6, R7: 4.7K; R_0805_2012Metric
R13: 100k; R_0805_2012Metric
R14: 33kΩ; R_0805_2012Metric
R15, R54, R56, R59: 470Ω; R_0805_2012Metric; LCSC Part C25117
R18, R55, R57, R58, R60, R63, R68: 10kΩ; R_0805_2012Metric; LCSC Part C25744
R20, R21, R22, R23, R24, R25, R26, R27, R28, R29, R30, R31, R32, R33, R34, R35, R36, R37, R38, R39, R40, R41, R42, R43, R44, R45, R46, R47, R48, R49, R50, R51, R52, R53: 80Ω; R_0805_2012Metric
R61: 1MΩ; R_0805_2012Metric
R62: 300kΩ; R_0805_2012Metric
R64: 0Ω; R_1206_3216Metric_Pad1.30x1.75mm_HandSolder; LCSC Part C25117
R65: 10kΩ; R_0805_2012Metric
R66: 1kΩ; R_0805_2012Metric; LCSC Part C11702
R67: 100kΩ; R_0805_2012Metric; LCSC Part C25741
SW1, SW2, SW3, SW4, SW6: TS-1187A-B-A-B; LCSC Part C318884
U1: TPA2016D2RTJR; TPA2016D2; MPN TPA2016D2RTJR
U2: PRTR5V0U2X_C2827688; PRTR5V0U2X; LCSC C2827688
U4: L86-M33
U5: RV-3028-C7; LCSC Part C3019759
U6: 24LC512; SOIC-8_3.9x4.9mm_P1.27mm
U7: LIS3DH; LGA-16_3x3mm_P0.5mm_LayoutBorder3x5y; LCSC Part C15134
U8: MX25L3233FM1; SOP-8_3.9x4.9mm_P1.27mm
U10, U11, U12, U13: IRLML6344TRPBF; IRLML6344; LCSC Part C53550
U14: LM3671MFX-3.3/NOPB; LM3671MFX-3.3
U15: LTC3226EUD-PBF; LTC3226
U18: ATSAMD51J19A-AUT; ATSAMD51J19_TQFP
X1: 32.768; Q13FC13500005; LCSC Part C841881

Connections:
+3.3V: C6.1, C7.1, C8.1, C9.1, C10.1, C11.1, C16.1, C17.1, C18.1, C20.1, C28.1, C30.2, J2.1 (VTref), J3.6, L1.2, R6.2, R7.2, R8.1, R9.1, R10.1, R11.1, R63.1, R65.2, R66.2, R67.2, R68.2, U1.13 (AVDD), U4.4 (VCC), U4.5 (V_BCKP), U5.7 (VDD), U6.8 (VCC), U7.1 (VDD_IO), U7.14 (VDD), U8.8 (VCC), U14.4 (FB), U18.8 (VDDANA), U18.21 (VDDIOB), U18.34 (VDDIO), U18.48 (VDDIO), U18.56 (VDDIO)
+5V: C19.1, C22.2, J1.A4/B9 (VBUS), J1.B4/A9 (VBUS__1), R13.2, U2.4, U14.1 (VIN), U15.3 (PFI), U15.8 (EN_CHG), U15.13 (VIN)
AlarmPower: C12.1, C13.1, R20.1, R21.1, R22.1, R23.1, R24.1, R25.1, R26.1, R27.1, R28.1, R29.1, R30.1, R31.1, R32.1, R33.1, R34.1, R35.1, R36.1, R37.1, R38.1, R39.1, R40.1, R41.1, R42.1, R43.1, R44.1, R45.1, R46.1, R47.1, R48.1, R49.1, R50.1, R51.1, R52.1, R53.1, R61.2, R64.1, U1.4 (PVDDL_2), U1.5 (PVDDL), U1.11 (PVDDR_2), U1.12 (PVDDR), U5.6 (VBACKUP), U15.16 (CPO)
AmpShutdown: R68.1, U1.18 (SDZ), U18.40 (D2/PB17)
Analog: C27.1, U18.3 (PA02/A0/PWM)
BUTTON1: R8.2, SW1.3, SW1.4, U18.27 (PB14/D5)
BUTTON2: R9.2, SW2.3, SW2.4, U18.26 (PB13/D4)
BUTTON3: R10.2, SW3.3, SW3.4, U18.25 (PB12/D7)
BUTTON4: R11.2, SW4.3, SW4.4, U18.28 (PB15/D6)
CapGood: R65.1, U15.11 (CAPGOOD), U18.13 (PA04/A3)
EEPROM_WP: U6.7 (WP), U18.62 (PB01)
Flash-IO-0: U8.5 (SI/SIO0), U18.17 (PA08/FlashIO0)
Flash-IO-1: U8.2 (SO/SIO1), U18.18 (PA09/FlashIO1)
Flash-IO-2: U8.3 (~WP/SIO2), U18.19 (PA10/FlashIO2)
Flash-IO-3: U8.7 (~HOLD/SIO3), U18.20 (PA11/FlashIO3)
Flash-IO-CS: U8.1 (~CS), U18.24 (PB11/FlashCS)
Flash-IO-SCK: U8.6 (SCLK), U18.23 (PB10/FlashSCK)
GND: C2.2, C6.2, C7.2, C8.2, C9.2, C10.2, C11.2, C14.2, C15.2, C16.2, C17.2, C18.2, C19.2, C20.2, C22.1, C24.1, C25.1, C26.1, C28.2, C29.1, D3.2 (A), J1.A1/B12 (GND), J1.B1/A12 (GND__1), J1.S1 (GND__2), J1.S2 (GND__3), J1.S3 (GND__4), J1.S4 (GND__5), J2.3 (GND), J2.5 (GND), J2.9 (GNDDetect), J3.7, R1.2, R2.2, R3.2, R14.1, R18.1, R55.2, R57.2, R58.2, R60.2, R62.1, SW1.1, SW1.2, SW2.1, SW2.2, SW3.1, SW3.2, SW4.1, SW4.2, SW6.3, SW6.4, U1.3 (AGND), U1.8 (PGND), U1.15 (INR+), U1.21 (EP), U4.3 (GND), U4.12 (GND), U5.5 (VSS), U6.1 (A0), U6.2 (A1), U6.3 (A2), U6.4 (GND), U7.5 (GND), U7.10 (GND), U7.12 (GND), U8.4 (GND), U10.2, U11.2, U12.2, U13.2, U14.2 (GND), U15.17 (EPAD), U18.7 (GNDANA), U18.22 (GND), U18.33 (GND), U18.47 (GND), U18.54 (GND); also elsewhere on the board
GNSS_FOn: U4.7 (FORCE_ON), U18.61 (PB00)
GNSS_Reset: U4.10 (~RESET), U18.60 (PB31)
I2C_SCL: R7.1, U1.17 (SCL), U5.3 (SCL), U6.6 (SCL), U7.4 (SCL/SPC), U18.64 (SCL/PB03)
I2C_SDA: R6.1, U1.19 (SDA), U5.4 (SDA), U6.5 (SDA), U7.6 (SDA/SDI/SDO), U18.63 (SDA/PB02)
LIS3DH_INT1: U7.11 (INT1), U18.11 (PB08/A4)
LedsB-K: LED11.1 (-), LED12.1 (-), LED13.1 (-), LED14.1 (-), LED15.1 (-), LED16.1 (-), LED17.1 (-), LED18.1 (-), LED19.1 (-), LED20.1 (-), LED21.1 (-), LED22.1 (-), LED23.1 (-), LED24.1 (-), U11.3
LedsB-S: R54.1, U18.41 (D9/PA20)
LedsL-K: LED1.1 (-), LED2.1 (-), LED3.1 (-), LED4.1 (-), LED5.1 (-), LED6.1 (-), LED7.1 (-), LED8.1 (-), LED9.1 (-), LED10.1 (-), U10.3
LedsL-S: R15.1, U18.42 (D8/PA21)
LedsR-K: LED25.1 (-), LED26.1 (-), LED27.1 (-), LED28.1 (-), LED29.1 (-), LED30.1 (-), LED31.1 (-), LED32.1 (-), LED33.1 (-), LED34.1 (-), U12.3
LedsR-S: R56.1, U18.15 (PA06/A2)
McuRX: U4.2 (TXD1), U18.44 (RX/D0/PA23)
McuTX: U4.1 (RXD1), U18.43 (TX/D1/PA22)
unnamed: C2.1, R1.1, U2.1
unnamed: C21.1, J5.1, R64.2
unnamed: C21.2, D3.1 (K), J5.2, U13.3
unnamed: J1.A5 (CC1), R3.1
unnamed: J1.B5 (CC2), R2.1
unnamed: LED1.2 (+), R20.2
unnamed: LED2.2 (+), R21.2
unnamed: LED3.2 (+), R22.2
unnamed: LED4.2 (+), R23.2
unnamed: LED5.2 (+), R24.2
unnamed: LED6.2 (+), R25.2
unnamed: LED7.2 (+), R26.2
unnamed: LED8.2 (+), R27.2
unnamed: LED9.2 (+), R28.2
unnamed: LED10.2 (+), R29.2
unnamed: LED11.2 (+), R30.2
unnamed: LED12.2 (+), R31.2
unnamed: LED13.2 (+), R32.2
unnamed: LED14.2 (+), R33.2
unnamed: LED15.2 (+), R34.2
unnamed: LED16.2 (+), R35.2
unnamed: LED17.2 (+), R36.2
unnamed: LED18.2 (+), R37.2
unnamed: LED19.2 (+), R38.2
unnamed: LED20.2 (+), R39.2
unnamed: LED21.2 (+), R40.2
unnamed: LED22.2 (+), R41.2
unnamed: LED23.2 (+), R42.2
unnamed: LED24.2 (+), R43.2
unnamed: LED25.2 (+), R44.2
unnamed: LED26.2 (+), R45.2
unnamed: LED27.2 (+), R46.2
unnamed: LED28.2 (+), R47.2
unnamed: LED29.2 (+), R48.2
unnamed: LED30.2 (+), R49.2
unnamed: LED31.2 (+), R50.2
unnamed: LED32.2 (+), R51.2
unnamed: LED33.2 (+), R52.2
unnamed: LED34.2 (+), R53.2
unnamed: R15.2, R57.1, U10.1
unnamed: R54.2, R55.1, U11.1
unnamed: R56.2, R58.1, U12.1
unnamed: R59.2, R60.1, U13.1
unnamed: C27.2, U1.14 (INR-)
unnamed: J6.1, U1.10 (OUTR+)
unnamed: J6.2, U1.9 (OUTR-)
unnamed: R63.2, U7.8 (CS)
unnamed: R18.2, U7.7 (SDO/SA0)
unnamed: R13.1, U14.3 (EN)
unnamed: L1.1, U14.5 (SW)
unnamed: C23.1, U15.15 (C+)
unnamed: C23.2, U15.12 (C-)
unnamed: R61.1, R62.2, U15.10 (CPO_FB)
unnamed: R14.2, U15.9 (PROG)
unnamed: C12.2, C13.2, C14.1, C15.1, U15.14 (VMID)
unnamed: C24.2, U18.1 (PA00), X1.2
unnamed: C25.2, U18.2 (PA01), X1.1
unnamed: C26.2, C29.2, C30.1, L4.1, U18.53 (VDDCORE)
unnamed: L4.2, U18.55 (VSW)
OLED_BL: U18.38 (D11/PA19)
OLED_CS: J3.1, U18.37 (D10/PA18)
OLED_DC: J3.2, U18.36 (D12/PA17)
OLED_RST: J3.3, U18.35 (D13/PA16)
SPI_MISO: U18.31 (PA14/MISO)
SPI_MOSI: J3.4, U18.29 (PA12/MOSI)
SPI_SCK: J3.5, U18.30 (PA13/SCK)
SWD_CLK: J2.4 (SWCLK/TCK), R66.1, U18.57 (SWDCLK/PA30)
SWD_IO: J2.2 (SWDIO/TMS), U18.58 (SWDIO/PA31)
SWD_RST: J2.10 (~RESET), R67.1, SW6.1, SW6.2, U18.52 (RESETN); also elsewhere on the board
SWO: J2.6 (SWO/TDO), U18.59 (SWO/PB30)
Speaker: R59.1, U18.39 (D3/PB16)
USB_N: J1.A7 (DN1), J1.B7 (DN2), U2.3, U18.45 (USB-D-/PA24)
USB_P: J1.A6 (DP1), J1.B6 (DP2), U2.2, U18.46 (USB-D+/PA25)

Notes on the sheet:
LED Driver
USB-Connector
SWD-Connector
Filter Capacitors
LEDs
GNSS
LM3671MFX-3.3/NOPB kan kanskje nøye seg med DFE252010F-2R2M=P2 for å spare plass MCU må ha vref forsøke å bytte ut supercap med liion i2c-EEPROM er overflødig Ambilight-sensor ville vært bra Sjekk footprint på forsterker (mask) Legg inn BL på display-kontakt
RTC I2C: 0x52
LIS3DH motion sensor
Display Connector
EEPROM I2C: 0x50
Cofigured at max charging speed of LTC3226 (315mA). Configured for 5v and 2x 2.7v supercaps
32 ohm 0.5W
I2C: 0x19
Volum-reducer
FLASH
i2c-Pullups
3.3v Regulator Iout: 600mA
Buttons
2 Cell Supercap charger
Speaker

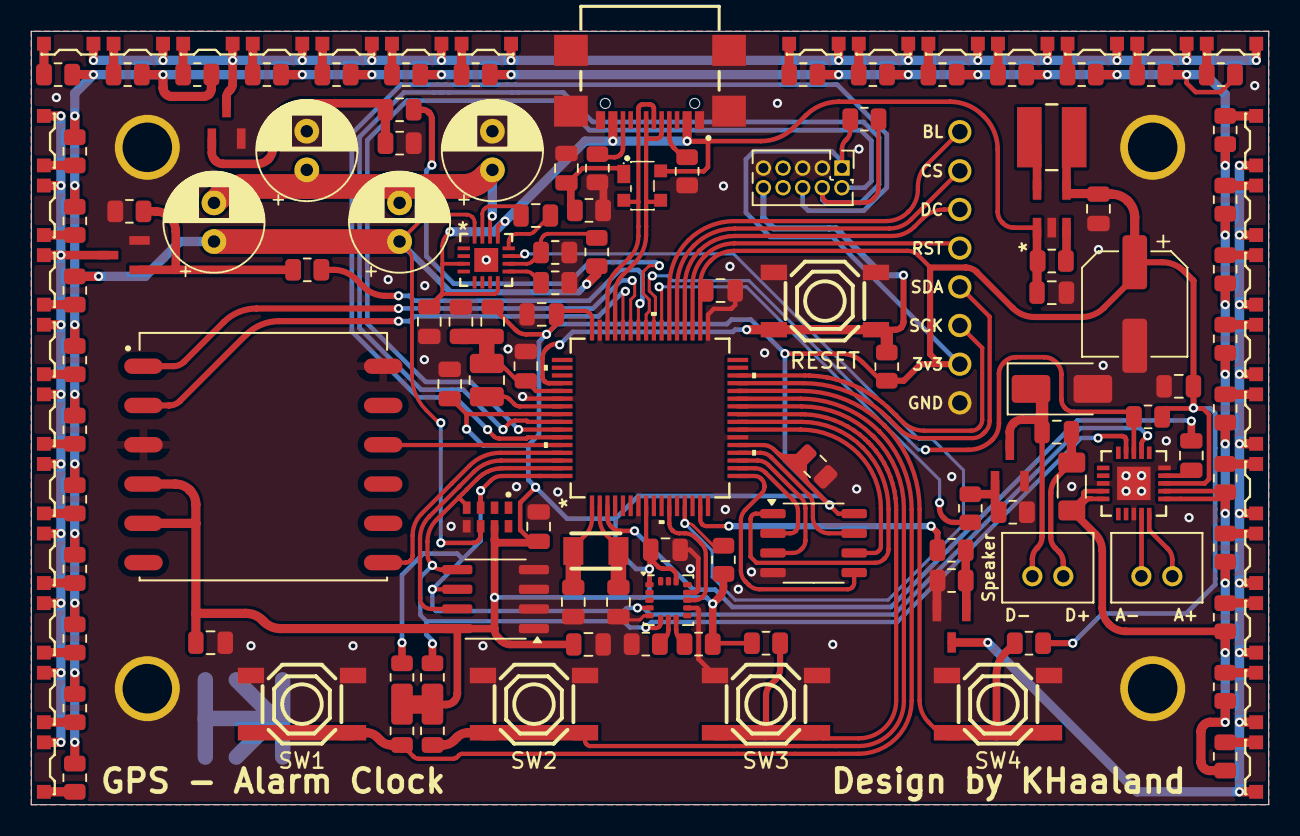
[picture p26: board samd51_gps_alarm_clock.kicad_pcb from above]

Board: 2 copper layers, 80.0 x 50.0 mm, 150 parts (0 on the bottom side), 102 nets.

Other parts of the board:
RESET: TS-1187A-B-A-B

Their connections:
GND: RESET.3, RESET.4; also elsewhere on the board
SWD_RST: RESET.1, RESET.2; also elsewhere on the board

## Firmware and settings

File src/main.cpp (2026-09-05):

// GNSS Alarm Clock — main firmware entry.
//
// Custom SAMD51J19A board (Metro M4 compatible). See include/pins.h for the
// full hardware map and README.md for behavior. Broad strokes:
//   - Time: GNSS (L86, Serial1) disciplines the RV-3028 RTC; timezone is
//     derived offline from coordinates and persisted to internal flash.
//   - Alarm: LED sections chase from the supercap rail, a tune plays from
//     QSPI-flash WAV (or builtin melody) through DAC0 -> TPA2016D2, with
//     optional power-buzzer escalation. Snooze by button short-press or
//     accelerometer tap, stop by long-press.
//   - UI: LVGL on the NV3007 428x142 color TFT, 4 buttons above the display.
//   - Tunes: the QSPI flash appears as a USB drive (drag & drop WAVs).

#include <Arduino.h>
#include <Wire.h>
#include <lvgl.h>

#include "pins.h"
#include "Settings.h"
#include "TuneStorage.h"
#include "Display.h"
#include "Buttons.h"
#include "Leds.h"
#include "AmpTPA2016.h"
#include "AudioEngine.h"
#include "AccelLIS3DH.h"
#include "Gnss.h"
#include "PmicNPM1300.h"
#include "RtcRV3028.h"

#ifdef __SAMD51J20A__
LV_IMAGE_DECLARE(img_lowbatt); // src/img_lowbatt.c (128x70, I1, white)
#endif
#include "ClockKeeper.h"
#include "AlarmManager.h"
#include "Ui.h"
#include "SimConsole.h"
#include "UsbGamepad.h"

// Diagnostic: when 1, setup() scans the whole I2C bus and prints every address
// that ACKs, in a loop over USB serial, instead of booting normally. Set to 0
// for normal operation. Known devices: RTC 0x52, LIS3DH 0x18/0x19,
// 24LC512 EEPROM 0x50, TPA2016 amp 0x58.
#define I2C_SCAN 0

static bool s_escalated = false;
static uint32_t s_ringStartMs = 0;   // when the current ring/re-ring began
#define TAP_ARM_MS 2000u             // ignore taps for the first 2 s of a ring

// ---- Alarm ring/silence orchestration -------------------------------------

static void start_ringing(int8_t idx, bool escalated) {
  const AlarmConfig &a = settings().alarms[idx];

  // Discard any stale accelerometer tap. The tap flag is set on any handling
  // of the clock but only consumed while ringing, so without this a bump from
  // minutes ago would instantly snooze the alarm the moment it fires.
  accel_tapped();
  if (!escalated)
    s_ringStartMs = millis(); // arm-delay reference for tap-to-snooze

  if (a.lights)
    leds_start(LedPattern::Chase, 150); // per-alarm: off = sound-only alarm

  if (!escalated) {
    // Initial fire or snooze re-ring: kill any tune preview and (re)start
    // the alarm sound from the beginning.
    audio_stop();
    // Digital volume pinned high: with AGC leveling on the amp, loudness is
    // set by the amp's limiter (amp_set_volume/amp_ramp_to). See ADR-0010.
    audio_set_volume(10);
    amp_enable(true);
    if (!alarm_fire_was_rering() && a.rampSeconds > 0)
      amp_ramp_to(settings().volume, a.rampSeconds); // gentle wake (per alarm)
    else
      amp_set_volume(settings().volume); // re-ring: no mercy
    bool ok = false;
    if (a.tune[0] != '\0')
      ok = audio_play_wav(a.tune, true);
    if (!ok)
      audio_play_melody(a.melodyId, true);
  }

  if (escalated && !s_escalated) {
    s_escalated = true;
    amp_set_volume(settings().volume); // escalation jumps past any ramp
    buzzer_start();
    if (a.lights)
      leds_start(LedPattern::Blink, 250); // more aggressive pattern
  }

  ui_show_ringing(idx);
}

static void stop_ringing() {
  buzzer_stop();
  audio_stop();
  amp_enable(false);
  leds_stop();
  s_escalated = false;
  ui_hide_ringing();
}

// Route button events: while ringing, short = snooze / long = stop; while
// snoozed, long = stop (short presses navigate normally); otherwise UI nav.
static void dispatch_buttons() {
  ButtonEvent ev;
  while (buttons_pop_event(ev)) {
    ui_poke();
    if (alarm_state() == AlarmState::Ringing) {
      if (ev.action == BtnAction::Long)
        alarm_stop();
      else
        alarm_snooze();
    } else if (alarm_state() == AlarmState::Snoozed &&
               ev.action == BtnAction::Long) {
      alarm_stop();
    } else {
      ui_handle_event(ev);
    }
  }
  if (alarm_state() == AlarmState::Ringing && settings().tapSnooze) {
    bool tapped = accel_tapped(); // always drain so it can't accumulate
    if (tapped && (millis() - s_ringStartMs) >= TAP_ARM_MS)
      alarm_snooze();
  }

  // Shake/tap to wake: any motion restores full brightness and resets the dim
  // timer (same as a button press). Harmless while ringing (already bright).
  if (accel_moved())
    ui_poke();
}

// ---- Arduino entry points --------------------------------------------------

void setup() {
  // Batteryless-boot survival (v2): the nPM1300 holds its VBUS limit at
  // 100 mA until we raise it, and with no battery to supplement, any excess
  // browns the board out. Clamp the two big loads firmware can reach BEFORE
  // anything else runs: hold the L86 in reset (it hangs straight on 3.3V,
  // no enable pin, and bursts ~100 mA acquiring) and force the amp off
  // (R68 pulls TPA2016 ~SD high = ON by default). The UF2 bootloader phase
  // remains unprotected — a custom bootloader is the full fix.
  // Core buck regulator: the Arduino core defaults to the LDO, but the
  // board carries the VSW inductor (L4), so switch VDDCORE to the internal
  // buck — saves ~4-6 mA at 3.3 V continuously (and trims the MCU's draw
  // inside the PMIC's 100 mA power-up window as a bonus).
  SUPC->VREG.bit.SEL = 1;
  while (!SUPC->STATUS.bit.VREGRDY) {
  }

  portb_output(GNSS_RESET_PORTPIN, false); // L86 core stopped
  pinMode(PIN_AMP_SHUTDOWN, OUTPUT);
  digitalWrite(PIN_AMP_SHUTDOWN, LOW); // amp off
  // Some display modules strap BL with a PULL-UP: a floating PA19 means the
  // backlight burns at full power all through the bootloader phase (found
  // the hard way — batteryless boot-loop). Drive it low the instant the app
  // starts; display_init() ramps it up properly later.
  pinMode(PIN_OLED_BL, OUTPUT);
  digitalWrite(PIN_OLED_BL, LOW);

  Wire.begin();
  // 100 kHz (standard mode): the custom board's I2C devices lack local HF
  // decoupling (see HARDWARE_REVIEW finding #12), so 400 kHz was unreliable and
  // the RV-3028 RTC intermittently failed to ACK ("RTC missing"). All bus
  // devices (RTC, accel, EEPROM, amp) work fine at 100 kHz.
  Wire.setClock(100000);

  // v2 boards: raise the nPM1300's VBUS current limit from its 100 mA
  // power-up default BEFORE any real load (LED sections!) can switch on.
  // No-op on v1 (no PMIC on the bus).
  pmic_begin();

  portb_hiz(GNSS_RESET_PORTPIN); // budget secured: release the L86

  Serial.begin(115200); // USB CDC; no wait — clock must boot headless

  // Storage first: it brings up TinyUSB MSC, best done early after boot.
  storage_begin();
  // HID gamepad interface must exist before the host enumerates (descriptors
  // are fixed after that); it stays silent unless MODE_GAME is selected.
  gamepad_begin();

  // After storage (alarm tune names are re-matched against the TUNES
  // directory) and after Wire (settings live in the RTC's user EEPROM).
  settings_begin();

#if I2C_SCAN
  // Loop-scan the bus so the result streams over USB serial (delay() services
  // TinyUSB, keeping CDC alive). Reports which 7-bit addresses ACK.
  for (;;) {
    Serial.println("=== I2C scan (0x03..0x77) ===");
    uint8_t found = 0;
    for (uint8_t a = 0x03; a <= 0x77; a++) {
      Wire.beginTransmission(a);
      if (Wire.endTransmission() == 0) {
        Serial.print("  ACK 0x");
        if (a < 0x10)
          Serial.print('0');
        Serial.print(a, HEX);
        const char *name = (a == 0x52)                  ? "  <- RV-3028 RTC"
                           : (a == 0x18 || a == 0x19)   ? "  <- LIS3DH accel"
                           : (a >= 0x50 && a <= 0x57)   ? "  <- 24LC512 EEPROM"
                           : (a == 0x58)                ? "  <- TPA2016 amp"
                                                        : "";
        Serial.println(name);
        found++;
      }
    }
    Serial.print("  total = ");
    Serial.println(found);
    delay(1500);
  }
#endif

  buttons_begin();
  leds_begin();
  amp_begin();
  audio_begin();
  accel_begin();

  rtc_begin();
  gnss_begin();
  clock_begin();

  display_init();

  // Low-battery boot gate: woken on battery with the cell still under
  // 3.45 V (hysteresis above the 3.40 V runtime cutoff), we say so for 4 s
  // and return to ship mode. A connected charger always allows boot.
  if (pmic_present()) {
    PmicStatus st;
    if (pmic_read_status(st) && !st.vbusPresent &&
        st.vbatMv < PMIC_VBAT_BOOT_MIN_MV) {
      lv_obj_t *scr = lv_screen_active();
      lv_obj_set_style_bg_color(scr, lv_color_black(), 0);
      lv_obj_t *l = lv_label_create(scr);
#ifdef __SAMD51J20A__
      // 128x70 battery icon (the user's XBM from an earlier project) on the
      // left, big text filling the right half. Montserrat 48 costs ~67 KB
      // flash — fine on the J20, but it OVERFLOWS the J19 by ~36 KB, so v1
      // builds keep the plain small-text message (their PMIC-less boards
      // can never reach this code anyway; pmic_present() is false).
      lv_obj_t *icon = lv_image_create(scr);
      lv_image_set_src(icon, &img_lowbatt);
      lv_obj_align(icon, LV_ALIGN_LEFT_MID, 18, 0);
      lv_obj_set_style_text_font(l, &lv_font_montserrat_48, 0);
      lv_obj_set_style_text_align(l, LV_TEXT_ALIGN_CENTER, 0);
      lv_label_set_text_static(l, "LOW\nBATTERY");
      lv_obj_align(l, LV_ALIGN_CENTER, 80, 0); // centered in the right half
#else
      lv_obj_set_style_text_font(l, &lv_font_montserrat_20, 0);
      lv_label_set_text_static(l, "LOW BATTERY");
      lv_obj_center(l);
#endif
      lv_obj_set_style_text_color(l, lv_color_white(), 0);
      uint32_t t0 = millis(), lastChk = 0;
      bool charger = false;
      while (millis() - t0 < 4000) {
        lv_timer_handler();
        delay(5);
        // A charger plugged mid-message rescues the boot ("a connected
        // charger always allows boot" — and the PMIC would refuse ship
        // entry with VBUS present anyway, which used to hang here).
        if (millis() - lastChk >= 250) {
          lastChk = millis();
          PmicStatus st2;
          if (pmic_read_status(st2) && st2.vbusPresent) {
            charger = true;
            break;
          }
        }
      }
      if (!charger)
        pmic_enter_ship_mode(); // powers off — or reboots if VBUS won a race
      lv_obj_delete(l); // charger appeared: clean the splash, boot normally
#ifdef __SAMD51J20A__
      lv_obj_delete(icon);
#endif
    }
  }

  display_set_contrast(settings().brightness);
  ui_begin();

  alarm_begin();
  alarm_set_callbacks(start_ringing, stop_ringing);

#ifdef GNSS_SIM
  sim_console_begin(); // env:sim — type coordinates over serial (no real GPS)
#endif
}

void loop() {
  // Low-battery cutoff (battery operation only): three consecutive 10 s
  // readings under 3.40 V -> ship mode, so the cell never grinds through
  // the brownout-loop zone below the LM3671's dropout. BUTTON1 or a USB
  // plug wakes the PMIC; the RTC keeps time throughout (VBACKUP on VBAT).
  // nPM1300 IRQ line (GPIO0 -> PA04): high while VBUS attach/removal events
  // pend. Attach must re-apply the input-current limit, which the PMIC
  // resets to 100 mA on every replug.
  if (pmic_present() && digitalRead(PIN_CAPGOOD))
    pmic_handle_irq();
  pmic_task(); // delayed VBUS reconfigure passes (CC settle + retry)

  // The check pauses whenever an alarm is Ringing OR Snoozed: the LED show
  // + speaker sag VBAT 50-100 mV (cell IR), which would false-trigger the
  // cutoff mid-alarm — and a shutdown while snoozed would kill the re-ring.
  // Waking someone up beats saving the last percent of a battery.
  static uint32_t s_batChkMs;
  static uint8_t s_batLowCount;
  if (pmic_present() && (uint32_t)(millis() - s_batChkMs) >= 10000) {
    s_batChkMs = millis();
    PmicStatus st;
    if (pmic_read_status(st)) {
      bool alarmActive = alarm_state() != AlarmState::Idle;
      if (!st.vbusPresent && !alarmActive && st.vbatMv < PMIC_VBAT_SHIP_MV) {
        if (++s_batLowCount >= 3) {
          // Farewell alert: one short high chirp + a sequential light sweep,
          // so a clock dying on the nightstand announces "charge me" instead
          // of silently going dark. Moderate volume + one LED section at a
          // time keeps the draw small at this battery level. The manual
          // Shutdown menu stays silent on purpose (the user is present).
          amp_enable(true);
          amp_set_volume(6);
          audio_play_beep(2200, 500);
          static const bool SEQ[4][3] = {
              {1, 0, 0}, {0, 1, 0}, {0, 0, 1}, {0, 0, 0}};
          for (uint8_t i = 0; i < 4; i++) {
            leds_set(SEQ[i][0], SEQ[i][1], SEQ[i][2]);
            uint32_t t0 = millis();
            while ((uint32_t)(millis() - t0) < 170)
              audio_task(); // keep the chirp fed while the sweep runs
          }
          amp_enable(false);
          pmic_enter_ship_mode(); // does not return
        }
      } else {
        s_batLowCount = 0;
      }
    }
  }

  // Debug screenshot: a '~' on the USB serial console streams the next frame
  // (tools/screenshot.py). peek() so GNSS_SIM console lines pass through.
  if (Serial.available() && Serial.peek() == '~') {
    Serial.read();
    display_screenshot_arm();
  }

  // Inputs & housekeeping
  buttons_task();
  accel_task();
  gnss_task();
#ifdef GNSS_SIM
  sim_console_task(); // read simulated coordinates from the USB serial console
#endif
  clock_task();
  storage_task();
  audio_task();
  leds_task();
  display_task();

  // Alarm engine
  alarm_task();

  dispatch_buttons();
  ui_task();
  gamepad_task(); // HID reports while in MODE_GAME (tilt + B2..B4)
  amp_task();     // gentle-wake volume ramp

  lv_timer_handler();
}

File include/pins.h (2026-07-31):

// pins.h — Board pin map for the GNSS Alarm Clock (custom SAMD51 board,
// Adafruit Metro M4 compatible variant; v1 = J19A, v2 = J20A — pin-identical
// in TQFP64).
//
// Verified against the v2 KiCad design (HARDWARE/, see HARDWARE_V2.md for the
// full 64-pad reference) and cross-checked against HARDWARE_OLD/ (v1). The map
// is near-identical between v1 and v2; the v2-only differences are:
//   - PA04 = nPM1300 GPIO0 (was LTC3226 CAPGOOD; unconfigured reads LOW)
//   - PB16 unconnected (escalation buzzer removed)
//   - PB01 unconnected (24LC512 EEPROM removed)
//   - BUTTON1 (PB14) is driven by a 74LVC1G17 buffer (U9) whose input is the
//     PMIC SHPHLD pin, not a raw switch; the physical SW1 doubles as the
//     nPM1300 wake/reset. Same active-low polarity as v1 at the MCU.
// Arduino pin numbers are the adafruit_metro_m4 variant (verified against
// variant.cpp / variant.h). "direct port" = pin is NOT in that variant, so it
// needs raw PORT register access (see portb_*() helpers below).
//
//  SAMD51 pin | Net         | Arduino | Function
//  -----------+-------------+---------+---------------------------------------
//  PA02       | Analog      | 14/A0   | Audio out (DAC0) -> C27 -> TPA2016 INR-
//  PA04       | PMIC_GPIO0  | 17/A3   | nPM1300 GPIO0 (v1: LTC3226 CAPGOOD)
//  PA06       | LedsR-S     | 16/A2   | Right LED section gate -> 470R -> U12
//  PA12       | SPI_MOSI    | 26/MOSI | Display SPI MOSI (SERCOM2) -> J4.5
//  PA13       | SPI_SCK     | 25/SCK  | Display SPI SCK  (SERCOM2) -> J4.6
//  PA14       | SPI_MISO    | 24/MISO | SPI MISO (not routed to J4 panel)
//  PA16       | DISP_RST    | 13      | display reset (active low), J4.4
//  PA17       | DISP_DC     | 12      | display data/command, J4.3
//  PA18       | DISP_CS     | 10      | display chip select (active low), J4.2
//  PA19       | DISP_BL     | 11      | display aux/backlight output, J4.1
//  PA20       | LedsB-S     |  9      | Bottom LED section gate -> 470R -> U11
//  PA21       | LedsL-S     |  8      | Left LED section gate  -> 470R -> U10
//  PA22       | McuTX       |  1      | Serial1 TX -> L86 GNSS RX (U4.1)
//  PA23       | McuRX       |  0      | Serial1 RX <- L86 GNSS TX (U4.2)
//  PB02       | I2C_SDA     | 22/SDA  | RV-3028 (0x52), TPA2016 (0x58),
//  PB03       | I2C_SCL     | 23/SCL  | LIS3DH (0x18), nPM1300 (0x6B); 4.7k PU
//  PB08       | LIS3DH_INT1 | 18/A4   | Accelerometer interrupt 1 (U7.11)
//  PB12       | BUTTON3     |  7      | Button 3 (active low, 1M pullup R9)
//  PB13       | BUTTON2     |  4      | Button 2 (active low, 1M pullup R8)
//  PB14       | BUTTON1     |  5      | Button 1 (active low; via U9 buffer,
//             |             |         | input = PMIC SHPHLD)
//  PB15       | BUTTON4     |  6      | Button 4 (active low, 1M pullup R10)
//  PB16       | (unconn.)   |  3      | v2: unconnected (v1: SPEAKER buzzer)
//  PB17       | AmpShutdown |  2      | TPA2016 ~SD (HIGH = amp on, 10k PU R68)
//  PA08..11,  | Flash IO    | QSPI    | U8 tune flash. Supported: W25Q128JV
//  PB10,PB11  |             |         | (3V) or MX25L3233F. NB: first v2
//             |             |         | board has a 1.8V W25Q128FW — wrong
//             |             |         | part, storage disabled (HARDWARE_V2)
//  --- not in the Metro M4 variant: direct PORT access ---
//  PB00       | GNSS_FOn    |  -      | L86 FORCE_ON (U4.7)
//  PB31       | GNSS_Reset  |  -      | L86 RESET_N (U4.10), active low
//  PB01       | (unconn.)   |  -      | v2: unconnected (v1: 24LC512 WP)
//  PA00/PA01  | 32.768 kHz  |  -      | X1 crystal (XOSC32K) — not GPIO
//
// Buttons sit in a row above the display, left to right: SW1 SW2 SW3 SW4.

#pragma once
#include <Arduino.h>

// --- Display (NV3007 428x142 landscape RGB565 TFT, 4-wire SPI on J4) ---
#define PIN_OLED_CS 10
#define PIN_OLED_DC 12
#define PIN_OLED_RST 13
#define PIN_OLED_BL 11

// --- Buttons, left to right as mounted above the display ---
#define PIN_BUTTON1 5 // PB14 (SW1, leftmost)
#define PIN_BUTTON2 4 // PB13 (SW2)
#define PIN_BUTTON3 7 // PB12 (SW3)
#define PIN_BUTTON4 6 // PB15 (SW4, rightmost)

// --- LED sections (gates of low-side MOSFETs, HIGH = section on) ---
// v2: LED anodes fed from +5V (TPS61023 boost) via 100R each (R20-R53);
// each gate has a 470R series resistor + 10k pulldown. (v1 fed from the
// supercap ALARMPOWER rail.)
#define PIN_LEDS_LEFT 8    // PA21, 10 LEDs (LED1-10),  gate R15
#define PIN_LEDS_BOTTOM 9  // PA20, 14 LEDs (LED11-24), gate R54
#define PIN_LEDS_RIGHT A2  // PA06, 10 LEDs (LED25-34), gate R56

// --- Audio ---
#define PIN_AUDIO_DAC PIN_DAC0 // PA02, AC-coupled into TPA2016 right input
#define PIN_AMP_SHUTDOWN 2     // PB17, HIGH = amp on (TPA2016 ~SD, 10k PU R68)
#define PIN_BUZZER 3           // PB16, v2: UNCONNECTED (buzzer removed);
                               // v1 gated J5 load on the supercap rail
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

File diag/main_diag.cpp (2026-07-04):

// Minimal USB-CDC diagnostic — isolates whether the core-bundled TinyUSB 3.1.0
// enumerates at all on this board (no storage, no LVGL, no I2C).
// Build/flash:  pio run -e diag  then copy the .uf2 to METROM4BOOT.
#include <Arduino.h>
#include <Adafruit_TinyUSB.h>

void setup() {
  Serial.begin(115200);
}

void loop() {
  static uint32_t t;
  if (millis() - t >= 500) {
    t = millis();
    Serial.print("diag alive t=");
    Serial.println(millis());
  }
}

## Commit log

2026-07-04 Initial commit: GNSS alarm clock firmware (SAMD51, LVGL 9)
    Firmware for the custom SAMD51J19A GNSS alarm clock (Adafruit Metro M4
    compatible):
    - GNSS (Quectel L86) time sync disciplining an RV-3028 RTC; offline
    timezone-from-coordinates with DST, persisted to internal flash
    - LVGL 9.5 UI on an SH1122 256x64 OLED, 4-button navigation
    - Two alarms: LED chase + tune via DAC -> TPA2016 (WAV from QSPI flash or
    builtin melodies), optional supercap power-buzzer escalation, tap-to-snooze
    - QSPI flash (MX25L3233F) exposed as a USB mass-storage drive for
    drag-and-drop WAV tunes
    - Host-testable timezone/DST engine (pio test -e native)
    Includes the KiCad hardware design under HARDWARE/.
    Co-Autho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
    [bom.csv, designators.csv, positions.csv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]
2026-07-04 Fix alarm tap-to-snooze + value editing; add hardware review
    Alarm / tap-to-snooze:
    - Root cause: the LIS3DH click detector fired continuously on the 1 g gravity
    (threshold == 1 g with no high-pass filter). Enable the HPF on the click
    path (CTRL_REG2 = 0x84). This also cured "alarm doesn't ring after snooze":
    the re-ring worked all along, but the spurious tap auto-snoozed it ~2 s in.
    - Use double-tap, a 2 s arm-delay after each ring, and always-drain the tap
    flag so pre-existing taps can't accumulate and self-snooze.
    UI:
    - Value editing: B2 decreases / B3 increases, stepping rollers directly via
    lv_roller_set_selected (the indev LV_KEY path was unreliable — only one
    direction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
    [AccelLIS3DH.cpp, main.cpp]
2026-07-04 Alarm robustness: daily-when-no-days, no-swallow, GNSS cold-start guard
    - No days selected now means "ring every day" (both the trigger scan and the
    next-occurrence display), so an enabled alarm with all days cleared fires.
    - A second alarm due while another is snoozing now rings (takes over the
    snooze) instead of being silently swallowed.
    - GNSS: require an actual position fix before trusting the receiver's time.
    On a cold start (indoors, no fix) TinyGPS++ still reports the free-running
    GPS-epoch date (year 2080), which previously passed the sanity check and
    overwrote the supercap-backed RTC. Gate time on a valid fix (+ year < 2100).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
    [Gnss.cpp]
2026-07-05 TuneStorage: document the real 16MB Winbond flash (BOM substitution)
    The assembled boards carry a Winbond W25Q128 (JEDEC 0xEF4018, 16 MB) rather
    than the BOM's Macronix MX25L3233F (4 MB). The USB drive correctly reports
    16 MB — flash detection already falls back to the library's default device
    list. No functional change; comment updated to reflect the actual part.
    [TuneStorage.cpp]
2026-07-05 Add ST7789 display driver + display/timekeeping bring-up fixes
    - New DisplayST7789 driver replacing SH1122 (RGB565, 284x76 landscape)
    * window offsets 18/82 for the centered sub-panel, display inversion off
    * MADCTL 0x60, 24 MHz SPI
    * synchronous per-byte flush (avoids the unhandled DMAC_1 IRQ that froze
    the MCU with the DMA transfer path)
    * gated bring-up self-test (DISPLAY_SELFTEST) kept in-tree, disabled
    - Clock face: center HH:MM, drop the seconds display
    - I2C 400k -> 100k: RV-3028 RTC unreliable at 400k on this board (no local
    HF decoupling, HW review #12); adds a gated I2C bus scanner (I2C_SCAN)
    - HARDWARE_REVIEW: note the SH1122 -> ST7789 display change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
    [DisplayST7789.cpp, main.cpp]
2026-07-05 Add GNSS speed/altitude to info screen; refresh docs (README + STATUS)
    - Gnss: add gnss_get_speed_kmph() (RMC) and gnss_get_altitude_m() (GGA),
    both gated on a current fix; show a "Speed / Alt" line on the sysinfo screen
    (integer-formatted, this build has no %f)
    - README: rewrite to current reality — ST7789 (LVGL 9, 24 MHz, offsets 18/82,
    inversion off, backlight D11), I2C 100 kHz, 16 MB flash, openocd .bin@0x4000
    flashing (+ never-flash-.elf warning), corrected source layout & features
    - STATUS.md: new full status report (working subsystems, this session's
    changes, open hardware items incl. RV-3028 no-ACK + L86 1PPS/AADET unrouted,
    firmware TODOs)
    - Fix stale "SH1122" referenc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
    [Gnss.cpp, main.cpp, pins.h]
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2026-07-05 Add shake/tap-to-wake for the display
    - AccelLIS3DH: add motion detection (accel_moved()) alongside the double-tap
    click detector — inter-sample acceleration delta > MOVE_THRESHOLD (~0.6 g);
    data path is not high-pass filtered so getEvent() sees absolute accel
    - main loop: any motion calls ui_poke() to restore full brightness and reset
    the dim timer (same as a button press); harmless while ringing
    - README/STATUS: document shake/tap-to-wake
    [AccelLIS3DH.cpp, main.cpp]
2026-07-06 Timezone: fine-grained global box table (~32 -> 211 zones)
    - Expand kZones[] to 211 bounding boxes covering every UTC zone worldwide:
    multi-zone countries split (US/Canada/Mexico/Russia/Brazil/Australia/...),
    ordered most-specific-first so no-DST exceptions (Arizona, Saskatchewan,
    Queensland/NT/WA, Kaliningrad, Sonora, Quintana Roo, Crimea, Easter I.,
    Lord Howe, ...) override their broader zone
    - Current 2025/26 DST reality: Brazil/Mexico(most)/Iran/Turkey/Russia no DST,
    Egypt DST reinstated, Israel/EU/US/AU/NZ/Chile DST kept; 30/45-min offsets
    (India, Nepal, Iran, Afghanistan, Newfoundland, Chatham, Lord Howe)
    - Generated + adversarially verified region-by-region; corrected an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
    [Timezone.cpp]
2026-07-06 Timezone: fix border overreach + add missing island zones (211 -> 213)
    Coverage audit (100+ cities) found broad boxes swallowing neighbors and two
    uncovered territories; all fixed and guarded by tests:
    - Afghanistan (Kabul) no longer swallowed by India; Pakistan given priority
    over India along the ~74.6E border (Karachi/Islamabad/Lahore/Peshawar = +5,
    Kabul/Herat/Kandahar = +4:30)
    - Thailand (Bangkok/Chiang Mai) no longer swallowed by Myanmar (Yangon east
    edge pulled to the border; Yangon/Mandalay/Mawlamyine stay +6:30)
    - Jordan (Amman +3) no longer swallowed by Egypt; also lets Jerusalem use the
    Israel box (Egypt east edge trimmed to 34.9E)
    - Add America/Nuuk (Greenland -2 EU DST) a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
    [Timezone.cpp]
2026-07-12 Timezone: polygon layer (real IANA borders) + fix Morocco POSIX
    Adds a polygon stage checked before the bounding-box table, so real timezone
    borders (and same-offset neighbours like Oslo/Stockholm/Helsinki) resolve by
    name, not just offset:
    - src/TimezonePolyData.h: 357 zones / 498 polygons / 6193 int16 centi-degree
    vertices (~41 KB), generated from timezone-boundary-builder (ODbL/OSM) data
    - Timezone.cpp: integer even-odd point-in-polygon (PNPOLY) with a bbox
    prefilter; tz_lookup = polygons -> boxes -> longitude fallback; zones
    ordered smallest-first so enclaves (e.g. Lesotho) win
    - ClockKeeper: compare zone name as well as POSIX so the display updates when
    the polygon distinguishes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
    [Timezone.cpp, gen_tz_polys.py]
2026-07-12 Add simulated-GNSS serial console (env:sim / -DGNSS_SIM)
    Debug build that feeds coordinates + UTC over the USB serial monitor instead of
    a real L86 fix, to exercise the timezone/clock pipeline on-device:
    - platformio.ini [env:sim] extends the default env + -DGNSS_SIM (own USB name)
    - SimConsole.cpp: line console — pos/tz/utc/status/nofix/help; `pos` applies the
    resolved zone to settings so the on-screen clock follows immediately
    - Gnss: sim setters (fix/pos/utc) drive the existing state; gnss_has_fix() is
    sim-aware; L86 PMTK init skipped under GNSS_SIM
    - main: gated sim_console_begin()/task() calls
    Compiles to nothing in the normal build (production flash unchanged at 95.2%);
    sim env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
    [Gnss.cpp, SimConsole.cpp, main.cpp]
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2026-07-13 USB MaxPower: actually 500 mA (board key + patch both TinyUSB copies)
    Two reasons the first attempt still reported 100 mA, both fixed:
    - The atmelsam builder emits its own USB_CONFIG_POWER define from the board
    manifest key build.usb_power (default 100), placed after build_flags on the
    command line - so -DUSB_CONFIG_POWER=500 was silently overridden. Set
    board_build.usb_power = 500 instead (the supported knob).
    - The build compiles TWO copies of Adafruit_USBD_Device.cpp (lib_deps 2.4.1
    and the copy bundled in the SAMD core package) and the linker picked the
    bundled one; patch_tinyusb_power.py now patches both.
    Verified: firmware.bin config descriptor byte = 0xFA and lsusb reports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
    [patch_tinyusb_power.py]
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2026-07-13 Add main-screen Mode selector: clock / speedometer / altimeter / game mode
    Menu gains a "Mode" item (cycles in place, persists; settings bumped to v2 ->
    stored settings reset once):
    - Speedometer / Altimeter: the big figure shows GNSS ground speed (km/h, one
    decimal below 100) or MSL altitude (m); "---" until a fix. Unit rides in
    the small side label; date + next-alarm bottom line stays.
    - Game mode: the LIS3DH becomes a USB HID gamepad (new UsbGamepad module,
    TinyUSB HID): tilt = stick X/Y (~20 deg full deflection), B2..B4 = buttons
    1..3, B1 keeps its menu role (B4's menu shortcut is suppressed on the home
    screen in this mode). The HID interface is registered at boot in every mode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
    [AccelLIS3DH.cpp, Gnss.cpp, SimConsole.cpp]
2026-07-13 Game-mode hint shortened; Bouvet unified as "Atlantic/Bouvet"
    - Game mode bottom line: "tilt=stick B2-B4=btns B1=menu" (old text was too
    long for 284 px)
    - The hand-drawn Bouvet polygon (added via the editor on another machine) is
    named "Atlantic/Bouvet"; rename the fallback box + editor ref layer + test
    to match (polygon wins the lookup, all carry GMT0). 22/22 native tests.
    - Move TimezonePolyData_backup.h out of src/ to tools/ (not part of the
    firmware build)
    [Timezone.cpp]
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2026-07-13 RTC EEPROM: tolerate I2C NACK while the EEPROM engine is busy
    Settings reverted to defaults every boot. Bench trace (per-step fail probe):
    reads died at the post-command EEBUSY wait — the RV-3028 NACKs I2C entirely
    while its EEPROM engine executes (observed right after ReadSingle), and
    eeprom_wait_ready() treated one failed STATUS read as fatal instead of "still
    busy". It also timed out at power-on, where the POR auto-refresh holds EEBUSY
    past 100 ms.
    Fix: the busy-wait now keeps polling through failed STATUS reads until a
    300 ms deadline. Verified on hardware: 39-byte image round-trips (magic
    'G''C' reads back), writes and reads both ok every cycle.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
    [RtcRV3028.cpp]
2026-07-14 RTC EEPROM: retry + read-back verify per byte (fixes reflash wipe)
    Settings survived reboots but not reflashes. Bench trace of the write path
    showed why: the RV-3028 transiently NACKs register writes in a short window
    after a completed EEPROM programming cycle (observed as a NACKed EEDATA write
    on the byte following a successful one, even with STATUS/EEADDR ACKing).
    The multi-byte save aborted after 1-2 bytes, corrupting the block; the next
    boot then found an invalid image and wrote defaults.
    eeprom_byte_op now retries the whole byte transaction up to 5 times with a
    3 ms backoff, and every written byte is verified by reading it back before
    moving on. Verified on hardware: a 10-byte pattern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
    [RtcRV3028.cpp]
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2026-07-14 Amp: AGC loudness leveling, gentle-wake ramp, limiter-as-volume, status
    TPA2016 rework (ADR-0010):
    - AGC compression 1:4 levels differently-mastered WAV tunes; fixed gain
    constant +6 dB; digital DAC volume pinned high (AGC would undo it)
    - Volume 0..10 now maps to the OUTPUT LIMITER level in 0.5 dBV steps
    (ceiling +6.5 dBV until the speaker rating is confirmed; reg max +9)
    - Gentle wake: first ring ramps the limiter from minimum to the set volume
    over settings().rampSeconds (menu "Ramp": Off/15/30/60 s). Snooze re-rings
    skip the ramp (alarm_fire_was_rering()) and buzzer escalation jumps to
    full volume. amp_task() steps the ramp from the main loop.
    - amp_get_status() reads SETUP fau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
    [AmpTPA2016.cpp, main.cpp]
2026-07-14 Per-alarm gentle-wake ramp, configured in the alarm editor
    The ramp moves from a global menu item into each alarm's edit screen
    (weekday alarm can fade in gently, weekend alarm can blast immediately):
    - AlarmConfig gains rampSeconds (0/15/30/60); the ring path uses the firing
    alarm's own value
    - Alarm editor gains a "Ramp" dropdown (menu loses the global row)
    - EEPROM pack v3: the ramp packs into 2 spare BITS of each alarm's flag byte,
    freeing the v2 global ramp byte entirely - free space grows 3 -> 4 bytes.
    Valid v2 blocks migrate in place (global ramp copied to both alarms);
    v1 blocks default to 30 s. Nothing else resets.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
    [main.cpp]
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2026-07-20 Display swapped to NV3007 428x142: driver, panel select, scaled UI
    The board now carries a Newvision NV3007 bar TFT (native 142x428, driven
    landscape 428x142) on the same SPI pins as the old ST7789.
    - src/DisplayNV3007.cpp: new driver. The vendor register dump (0xFF 0xA5
    extended page: power/gamma/GOA/source timing, then 0xFF 0x00 back to DCS)
    is MANDATORY - with only DCS init the address engine wraps writes linearly
    across the glass (bench-observed as colored bands). Init cross-verified
    against five independent codebases (vendor reference txt, Arduino_GFX,
    LVGL lv_nv3007, STM32 and esp_lcd ports). GRAM 168x428, landscape MADCTL
    0x60 with RASET+14 (0xA0 -> +12), inversion off, S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
    [DisplayNV3007.cpp, DisplayST7789.cpp, main.cpp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]
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2026-07-21 Display: 15 ms LVGL refresh + 32-row render buffer; docs for the SPI speedup
    - LV_DEF_REFR_PERIOD 30 -> 15 ms: flushes are now fast enough that the
    refresh tick was the bottleneck for animation/scroll smoothness.
    - Partial-render buffer 24 -> 32 rows (~27 KB, RAM 49%): fewer flush
    windows per redraw.
    - README/STATUS: 30 MHz reclock + DRE-paced bulk flush documented; STATUS
    RTC status corrected (U5 soldered and verified, no longer a HW fault).
    [DisplayNV3007.cpp]
2026-07-21 Display: async DMA flush + double buffering (ADR-0012, supersedes ADR-0002)
    Dedicated DMAC channel (Adafruit_ZeroDMA) beat-triggered on SERCOM2 TX:
    flush_cb starts the job and returns; the completion IRQ waits out TXC,
    cleans the RX side, raises CS and calls lv_display_flush_ready(). Two
    32-row LVGL buffers (RAM 63%) let rendering overlap the transfer, and the
    main loop (audio feed, GNSS, buttons) no longer stalls behind a flush.
    ADR-0002's freeze was the *unhandled* DMAC_1 IRQ, not DMA itself —
    Adafruit_ZeroDMA installs handlers for all five DMAC IRQ lines. If channel
    allocation or startJob ever fails, the driver falls back to the synchronous
    DRE-paced loop; display_power() waits out in-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
    [DisplayNV3007.cpp]
2026-07-21 Audio: DMA-paced DAC playback (ADR-0013) — no more per-sample IRQ
    TC2 stays the sample-rate pacer (MFRQ, IRQ off); each overflow triggers one
    DMAC halfword beat from a two-half ping-pong buffer (2x2048 samples, same
    8 KB) into DAC->DATA[0]. The looped descriptor pair (BLOCKACT=INT) gives
    one IRQ per half (~93 ms @ 22 kHz) instead of 22-48k IRQ/s; the callback
    frees the played half and audio_task() refills it. If a half was never
    refilled in time, the IRQ overwrites it with midpoint silence so stale
    audio can't loop audibly. Drain pads the last half and stops after both
    queued halves play out. Per-sample TC2 ISR kept as fallback if DMA channel
    allocation fails.
    Display (ch0) and audio (ch1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
    [AudioEngine.cpp]
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2026-07-21 Sky view (GSV) + starry night + AM/PM baseline fix; LVGL pool 48->64K
    Sky view: new UI screen (menu) with a polar az/elev plot (zenith center,
    horizon ring, N up) and SNR bars for the 12 strongest satellites, colored
    by signal (green/yellow/red/grey) and constellation (white GPS, cyan
    GLONASS). The L86 now outputs GSV every 5th fix (PMTK314 checksum 0x2D) --
    full-rate GSV would crowd the 9600-baud link. TinyGPS++ has no GSV support,
    so a small checksum-verified line parser runs beside it, staging each
    talker's group and committing atomically. Works without a fix: this is the
    indoor antenna-placement aid.
    Starry night: optional toggle (Disp & sound) -- 26 twinkling stars behind
    the clock dig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
    [Gnss.cpp]
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2026-07-31 v2 power: nPM1300 driver + Battery screen; HARDWARE_V2.md reference
    PmicNPM1300: raises the VBUS input limit 100->500 mA at every boot (it
    resets on VBUS replug; 500 mA is the hard USB-port protection), then
    configures and enables the Li-ion charger: 200 mA (0.07-0.1C for the
    2000-3000 mAh cells), terminate at 4.10 V (user choice - the clock lives
    on the charger, undercharging extends cell life), NTC type 10k (fixed
    resistor on the board, reads constant ~25 C). All no-ops on v1.
    New "Battery" menu screen: VBUS presence, battery voltage + rough SoC
    estimate scaled to the 4.10 V target, decoded charge state (trickle/CC/
    CV/charged/battery-assisting), PMIC die temperature. supercaps_ready()
    re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
    [Leds.cpp, PmicNPM1300.cpp, main.cpp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]
2026-07-31 HARDWARE_V2: complete 64-pad MCU pinout from the v2 schematic; pins.h rewrite
    Systematic pass over HARDWARE/GNSS_Alarm_Clock.kicad_sch (symbol pin map)
    joined with the PCB netlist and cross-checked against the metro_m4 Arduino
    variant table. HARDWARE_V2.md now carries the full pad|PORT|net|function|
    Arduino table; pins.h's comment table is rewritten for v2 (with v1 notes)
    and gains I2C_ADDR_PMIC.
    Confirmed: the only signals needing direct PORT access remain PB00 (L86
    FORCE_ON) and PB31 (L86 RESET_N) — both already handled by the portb_*()
    helpers — plus PB01 which is unconnected on v2. New v2 facts captured:
    PA03/VREFA tied to 3.3V, BUTTON1 is push-pull driven by the U9 buffer (no
    MCU p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
    [pins.h]
2026-07-31 diag: L86 aliveness test — RESET_N pulse + NMEA byte counter/last sentence
    A healthy L86 answers a reset pulse with a $PMTK011 boot burst even with
    zero antenna signal, so silence after the pulse means power/solder/TX
    path, not RF. Diagnosed the v2 board's silent GNSS: cold VCC joint on U4
    (RESET_N read 2.8 V from the backup domain while FORCE_ON read 0 — main
    domain unpowered). Confirmed alive after reflow: 13 sats in view indoors.
    [main_ledtest.cpp]
2026-07-31 Tunes-freeze fix (LVGL pool 64->80K) + QSPI flash forensics on v2
    The Tunes screen froze the clock: same signature as the earlier Sky-view
    incident - the Tunes list is the only screen that builds its ~30 LVGL
    objects on entry, and the 64K pool (sized just-enough when Sky view was
    added) tipped over -> LV_ASSERT_MALLOC hangs forever. Pool now 80K
    (RAM 80.2%). Also bounded the FAT root-dir scan to 512 iterations so a
    corrupt directory chain can never freeze the UI.
    QSPI flash: the v2 board's U8 turned out to be a W25Q128FW (JEDEC
    EF 60 18) - Winbond's 1.8V variant, out of spec on the 3.3V rail. It
    answers JEDEC but has no library profile, so storage/TUNES is disabled
    (gracefully). Documented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
    [TuneStorage.cpp, main_ledtest.cpp, pins.h]
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2026-08-01 v2 boot robustness + battery status UI
    Boot-window load clamping (ADR-0014): setup()'s first instructions hold
    the L86 in reset, force the TPA2016 off (R68 pulls it ON) and drive the
    display BL pin low (some modules strap BL with a PULL-UP - a floating
    PA19 burns the backlight at full power through the bootloader phase,
    found as a battery-less boot-loop). pmic_begin() then raises the nPM1300
    VBUS limit to 500 mA before the loads are released, and display_init()
    soft-starts the backlight with a ~100 ms PWM ramp instead of a full step.
    Clock face status row: battery icon mirroring SoC + percent + charge
    bolt (PMIC polled every 5 s), spacing between symbols, v1 keeps the
    plain supercap indicat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
    [DisplayNV3007.cpp, PmicNPM1300.cpp, main.cpp]
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2026-08-01 Power: live IBAT on the Battery screen; charge 400 mA + 55/45 C thermostat
    IBAT: the nPM1300's battery-current measurement is enabled (piggybacks on
    every VBAT ADC round) and shown as a signed Current line - user-verified
    on battery: 150-175 mA discharge, matching expectations.
    Charge setpoint 200 -> 400 mA: the PMIC prioritizes system load in
    hardware and gives charging whatever remains of the 500 mA VBUS budget
    (datasheet-confirmed), so the setpoint is a max, not a demand - expected
    real rate ~325-350 mA. IBAT full-scale tracks the setpoint automatically.
    Die-temp charge thresholds 110/100 -> 55/45 C (DIETEMPSTOP/RESUME):
    deliberately tight thermostat behavior - charging may duty-cycle t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
    [PmicNPM1300.cpp]
2026-08-01 Low-battery policy + Shutdown menu item (ship mode)
    Runtime cutoff: on battery only, three consecutive 10 s readings under
    3.40 V enter nPM1300 ship mode (<500 nA, battery cut from VSYS) instead
    of grinding through the brownout zone below the LM3671 dropout. The
    check PAUSES while an alarm is Ringing or Snoozed - the LED show +
    speaker sag VBAT 50-100 mV through the cell IR and would false-trigger
    mid-alarm, and shutting down while snoozed would kill the re-ring.
    Waking someone up beats saving the last percent of battery.
    Boot gate: woken on battery with VBAT still under 3.45 V (hysteresis),
    show fullscreen "LOW BATTERY" for 4 s and return to ship mode. With a
    charger connected the clock al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
    [PmicNPM1300.cpp, main.cpp]
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2026-08-01 Power: CC-based VBUS limit (500/1500 mA) + IRQ-driven replug reconfig
    The input limit now follows the USB-C CC advertisement (USBCDETECTSTATUS
    comparators): Default USB / A-to-C / PC port -> 500 mA (the hard PC-port
    rule), detected 1.5 A / 3 A source -> 1500 mA, so charging + alarm peaks
    never touch the battery on a real charger. Battery screen shows the
    active limit.
    Replug fix: the PMIC resets its limit to 100 mA on every VBUS attach, but
    pmic_begin() only ran at boot - a replug used to leave the clock at
    100 mA, slowly draining the battery while "charging". nPM1300 GPIO0
    (wired to PA04) is now configured as an IRQ output for VBUS attach/
    removal events; the main loop services it and re-a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
    [PmicNPM1300.cpp, main.cpp]
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2026-08-01 Lights menu (per-section LED switches) + thermostat raised to 65/55 C
    "Lights" screen: manual on/off per LED section via leds_set() - a power-
    measurement companion to the Battery screen's live IBAT readout (flip a
    section, read the cost). State persists while navigating; alarm light
    shows override it.
    Die-temp charge thresholds 55/45 -> 65/55 C after bench observation
    (user call). ADR-0014 and the user guide updated to match.
    [PmicNPM1300.cpp]
2026-08-01 LOW BATTERY screen: fullscreen icon + Montserrat 48 text
    The boot-gate message grew from a 20 px line to a proper screen: the
    user's 128x70 battery XBM (from the AVR/DCF77-era ancestor project,
    bit-reversed to an LVGL I1 image with transparent background) on the
    left, "LOW BATTERY" in white Montserrat 48 centered in the right half.
    White on true black to match the clock's aesthetic (red was tried and
    voted out). Montserrat 48 relinks (~67 KB) - trivial on the J20.
    User-verified on a genuinely empty battery, which also field-proved the
    whole low-battery chain: 3.40 V cutoff -> ship mode -> B1 wake ->
    fullscreen message -> back to sleep.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
    [main.cpp]
2026-08-01 Fix J19 flash overflow: big LOW BATTERY screen is J20-only
    Montserrat 48 + icon overflowed the v1/J19 build by 36 KB. v1 boards
    have no PMIC so the boot gate is unreachable there anyway; they keep a
    small-text fallback and the linker GCs the font again.
    [main.cpp]
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
